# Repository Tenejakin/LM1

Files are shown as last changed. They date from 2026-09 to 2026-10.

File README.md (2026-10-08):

<p align="center">
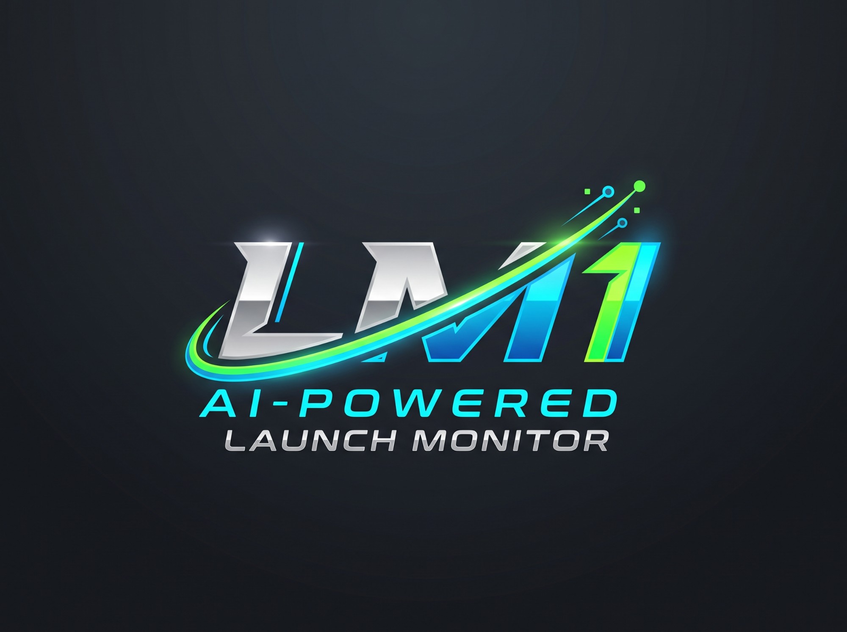
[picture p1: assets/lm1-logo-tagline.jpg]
LM1 - AI-powered launch monitor
  
</p>

<h1 align="center">LM1 — DIY Camera Golf Launch Monitor</h1>

<p align="center">
  A Raspberry Pi 5 + OV9281 global-shutter camera launch monitor, with a React Native companion app that talks to it over Bluetooth LE.
</p>

<p align="center">
  
  
  
  
  
</p>

---

> [!WARNING]
> **LM1 is an experimental hobby project.** Its measurements are unvalidated estimates and have not been checked against a reference launch monitor. Every value is labelled as measured, camera-estimated or club-estimated, with a confidence score. Treat the numbers as indicative only.

## What it is

LM1 has three parts:

| Part | Where | What it does |
| --- | --- | --- |
| **Mobile app** | [`App.tsx`](App.tsx), [`src/`](src) | Expo / React Native app for iOS and Android. It arms the monitor, shows shots, sessions and putting, and handles calibration and device setup. |
| **Pi service** | [`raspberry_pi/`](raspberry_pi) | A Python BLE peripheral on a Raspberry Pi 5. It keeps a rolling high-speed capture buffer, detects shots and runs the computer vision. |
| **Hardware** | [`hardware/`](hardware) | Parametric CAD scripts and printable STLs for the enclosure, camera brackets, IR light mounts and cable clips. |

```text
OV9281 camera ──► Raspberry Pi 5 ──BLE──► LM1 app ──► OpenGolfSim / n8n webhook
                  │                                  
                  ├─ rolling RAM buffer              
                  ├─ ball + AprilTag detection       
                  ├─ trajectory fit                  
                  └─ club silhouette / tag tracking  
```

The phone and the Pi talk **only over Bluetooth LE**. You don't need a shared network, an IP address or port forwarding. The Pi's Wi-Fi is left free for updates, SSH and simulator traffic.

## Features

**Measurement (Pi)**
- Ball speed, launch angle and start direction from a sub-pixel trajectory fit over up to 48 tracked frames
- Clubhead speed, attack angle and club path, from a club AprilTag or from the clubhead silhouette when no tag is fitted
- Smash factor, strike location on the face and surface spin estimates
- Putting motion analysis: pace, start line, skid and roll
- AprilTag ground calibration saved as a 3D pose, so the tag can be removed after calibration
- Lens calibration, a saved target line, and automatic exposure (shutter + gain)
- The last 100 rolling captures are kept on the Pi, each with a contact sheet for review

**App**
- Live monitor with ready → armed → processing → result states
- Club selection, carry estimates, shot history, session averages and consistency
- Shot review shows each metric's source and confidence
- Dedicated putting monitor and a manual shot calculator
- Device screen covering Wi-Fi setup over BLE, camera tuning, calibration and health diagnostics
- Metric or imperial units, set once and used on every screen
- [OpenGolfSim](OPENGOLFSIM.md) Desktop and Web forwarding, plus n8n webhook export
- Interactive demo mode, so you can try the app without any hardware

## Hardware

| Component | Notes |
| --- | --- |
| Raspberry Pi 5 | 1 GB is enough; use active cooling |
| OV9281 global-shutter camera | CSI, high frame rate (90–200+ fps depending on mode) |
| Continuous LED / IR lighting | Needed for the short exposure times |
| AprilTag target | For ground-plane calibration (see [`scripts/create_apriltag_target.py`](scripts/create_apriltag_target.py)) |
| 3D-printed parts | See [`hardware/enclosure/README.md`](hardware/enclosure/README.md) |

The full design rationale is in [`golf_launch_monitor_project.md`](golf_launch_monitor_project.md).

## Getting started

### 1. Run the app

You need Node.js 20+ and an LM1 **development build** installed on a phone. BLE uses native code, so the app **does not run in Expo Go**.

```bash
npm install
npm start
```

Then open the dev server from the LM1 development app on your phone. To build one:

```bash
npm run build:android:dev
```

```bash
npm run build:ios:dev
```

Android can also be built locally with `npm run android`. iOS builds go through EAS and need an Apple Developer account, but no Mac.

**No hardware?** Open the **Device** tab and choose **Use interactive demo**.

### 2. Set up the Raspberry Pi

Follow [`raspberry_pi/README.md`](raspberry_pi/README.md): flash Raspberry Pi OS Lite (64-bit), copy the `raspberry_pi/` folder over and run `install.sh`. This installs the BLE service as a systemd unit. The app finds the Pi by its BLE service UUID, so there is nothing to configure.

### 3. Calibrate

In the app, work through the checklist on the home screen:

1. **Lens calibration**, done once per lens and focus setting
2. **AprilTag ground calibration**, done with the tag in view; you can remove the tag afterwards
3. **Automatic exposure**, then fine-tune shutter and gain by hand if needed

[`LAUNCH_MEASUREMENTS.md`](LAUNCH_MEASUREMENTS.md) covers the full setup.

## Scripts

| Command | Purpose |
| --- | --- |
| `npm start` | Start the Expo dev server for the dev client |
| `npm run android` / `npm run ios` | Build and run on a connected device |
| `npm run web` | Web preview (demo only, no BLE) |
| `npm run typecheck` | TypeScript check |
| `npm run lint` | ESLint |
| `npm run ogs:bridge` | Start the OpenGolfSim Desktop WebSocket→TCP bridge |
| `npm run test:ogs` | Test the OpenGolfSim bridge |
| `npm run test:capture` | Test the capture client |

The Pi tests live in [`raspberry_pi/tests/`](raspberry_pi/tests). Run them on the Pi with:

```bash
python -m unittest discover -s raspberry_pi/tests -q
```

## Project layout

```text
App.tsx                  App shell and tab navigation
src/
  components/            UI and shot visualizations
  context/               Device/demo state and reconnection
  screens/               Home, Putting, Calculator, History, Calibration, Device
  services/              BLE client, OpenGolfSim and n8n integrations
  theme.ts, types.ts     Design tokens and shared types
raspberry_pi/            Pi BLE service, vision pipeline, calibration, tests, systemd
bridge/                  OpenGolfSim Desktop bridge
scripts/                 Calibration targets, capture audit and replay tools
hardware/                Enclosure, bracket and clip CAD (Python) + STLs
shared-hosting-server/   Optional PHP/MySQL API for uploading shot data and images
camera-tests/            Reference frames from camera bring-up
```

## Documentation

| Doc | Contents |
| --- | --- |
| [`DEVICE_API.md`](DEVICE_API.md) | BLE protocol spec (commands, events, chunking) |
| [`LAUNCH_MEASUREMENTS.md`](LAUNCH_MEASUREMENTS.md) | How measurements are made and how to calibrate |
| [`OPENGOLFSIM.md`](OPENGOLFSIM.md) | Simulator connection setup |
| [`raspberry_pi/README.md`](raspberry_pi/README.md) | Pi installation and service details |
| [`hardware/enclosure/README.md`](hardware/enclosure/README.md) | Enclosure revisions and print notes |
| [`shared-hosting-server/README.md`](shared-hosting-server/README.md) | Optional upload API |
| [`CHANGELOG.md`](CHANGELOG.md) | Release history |

## Security note

In this MVP, BLE pairing and Wi-Fi provisioning work for anyone in Bluetooth range. Before using LM1 in a shared space, turn off provisioning or add authenticated bonding.

## Contributing

This is a personal project, but issues and pull requests are welcome. Before opening a PR, run `npm run typecheck` and `npm run lint`, and run the Pi test suite if you changed the Pi service.

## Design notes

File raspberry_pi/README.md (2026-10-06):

# LM1 PRO Raspberry Pi BLE Service

Service **0.45.0**, protocol **2.31.0**: three clean paired stereo ball frames are sufficient for measured-grade speed, launch angle, and direction when all timing, geometry, calibration, and fit-quality gates also pass. Two paired frames remain an estimated speed-only fallback.

Service **0.44.0**, protocol **2.30.0**: putting captures can emit a putt result when ball and putter motion are resolved even if face strike is unavailable. An unavailable strike is `null`; `airborne` flags launch above 10° so the app does not present a ground-roll estimate for it.

Service **0.43.0**, protocol **2.29.0**: status reports the active capture mode so the app can show whether the Pi is set to a normal shot or putting, including after reconnecting. The app can switch modes in one tap before a ball is placed.

Service **0.42.0**, protocol **2.28.0**: full shots save up to 48 frames after the measured departure (plus any later tracked ball frame), discarding the empty detector-confirmation tail. Putting retains the full rolling burst. The Pi still observes the confirmation window before it reports a shot. Set `PINPOINT_FULL_SHOT_TAIL_FRAMES` to tune the saved full-shot tail.

Service **0.41.0**, protocol **2.28.0**: a signed-in app can issue a short-lived
ticket for one shot, then ask the Pi to upload every retained original JPEG from
both cameras directly to the Supabase frame ingest function. The ticket is
limited to that shot and expires after six hours. Set
`PINPOINT_SUPABASE_PROJECT_REF` in `/etc/default/pinpoint` for this feature.

Service **0.40.0**, protocol **2.27.0**: two high-quality stereo ball frames may
yield estimated interval-average ball speed, using the resting-ball impact
bracket as a consistency check. Two frames cannot resolve the flight curve,
so launch angle, direction, and carry remain unavailable.

Service **0.39.1**, protocol **2.26.1**: capture summaries distinguish a valid
mono fallback from shots where both stereo and mono tracking failed.

Service **0.39.0**, protocol **2.26.0**: the lower camera arms only when the
whole resting ball fits in the left-half green placement zone. The right half
remains available for outgoing tracking; the upper camera must still see the
resting ball and early flight. The stock ROI is `0,0.30,0.50,0.98`.

Service **0.38.1**, protocol **2.25.1**: tag-free club silhouette speed and
attack angle are retained for the selected club. Only an explicitly calibrated
club marker for a different club invalidates those values.

Service **0.38.0**, protocol **2.25.0**: full-shot carry now uses a
still-air drag/lift flight model. The selected club, ball speed and measured
attack angle set provisional spin when surface spin cannot be tracked.
`carryModel` records which spin source was used; landing is never observed.

Service **0.36.0**, protocol **2.23.0**: valid stereo geometry now supplies the
launch vector directly. Ball movement without resolved club motion is retained
as a capture, not emitted as a full shot. Ground recalibration invalidates the
previous target line; roll a fresh ball toward the target afterward. Keep the
entire resting ball, plus a little background, visible in both camera views.

Service **0.35.0**, protocol **2.22.0**: failed stereo tracks retain matched frame
indices and rejection counts for the app's capture review.

Service **0.34.0**, protocol **2.21.0**: stereo launch can use three validated paired
frames as an estimate, while three are needed for measured-grade metrics. A second
circle-detection pass recovers weak ball edges only when normal stereo pairing fails.

Service **0.33.0**, protocol **2.21.0**: when both camera lens and shared-ground-
tag calibrations are present, launch analysis triangulates the ball in both
views. If the lower-camera track fails, each view detects the ball independently
and pairs candidates using ray geometry and a coherent 3D path. It checks
tag-pose age, pair timing, resting position, ray agreement and two-view
reprojection before reporting a result. See
[dual-camera setup](../DUAL_CAMERA_SETUP.md) for calibration and limits.

Service 0.26.0 / protocol 2.17.0: speed, launch angle and direction come from an anchored trajectory fit to up to 48 sub-pixel tracked frames. It starts from the resting ball's ground position, chooses between a ground roll and a gravity flight, re-estimates the start of a ball nudged before release and reports fit uncertainty. Contact analysis ignores a hand or finger that stays in view. A departure must start at the resting ball, the resting ball must not reappear afterwards, and the motion nearest the trigger wins. A ball armed while the placing hand still touched it now tracks from a clean resting image. A ball that stays at resting height is reported as a ground roll with 0-degree launch, measured along the ground plane. The armed-ball reference stays paired with its original bounding box, refreshes only while the ball rests there, and is saved losslessly for replay. captures now retain calibration and outline-rejection diagnostics, and failure messages distinguish camera frames from usable 3D outlines. contact analysis now re-anchors slightly shifted resting balls and rejects stationary offset matches as outgoing motion. reconnect history is bounded to the newest ten records so the 100 retained captures cannot overflow one BLE message. The default ball-detection region covers 90% of the frame width and 68% of its height while retaining a small edge safety margin. Keep hands, clubheads, screens and moving shadows out of that region whenever possible. Tracker-guided partial silhouettes can produce explicitly lower-confidence launch estimates only after three consecutive matches, stable apparent radius and the existing 3D fit check. The strict full-silhouette path remains the default. Saved manifests now retain exact ball bounds for replay. The service also selects the best of up to 12 static ground-AprilTag detections; poses from 1–3 px reprojection error remain explicitly lower-confidence estimates and anything worse is rejected. It includes seam-split silhouette repair, convex-hull ball depth fitting, half-resolution ball tracking (analysis ~2 s instead of ~6 s), MTU-sized BLE notifications, no previews during result delivery, ~1.35 s rolling bursts by default, background AprilTag/focus/snapshot/BLE-preview work, an 8-request camera queue, per-capture contact sheets, live persistent exposure/gain controls, contact-window detection, AprilTag-referenced launch estimates, club-marker tracking, surface spin and putting motion analysis. The Pi retains the newest 100 rolling captures by default. See [measurement setup](../LAUNCH_MEASUREMENTS.md). Values remain unvalidated estimates.

Current service 0.42.0 · BLE protocol 2.28.0

This is the BLE-only Raspberry Pi half of Pinpoint. It opens no Pinpoint network port. The app can connect, arm, trigger, and receive synthetic shots or putts before the camera arrives, while Wi-Fi remains available for internet, SSH, software updates, and OpenGolfSim.

Synthetic results prove communication only. They are not measurements. When a USB webcam is attached, test mode also captures a real diagnostic JPEG so the camera path, framing, lighting, and exposure can be checked before the high-speed camera arrives.

Version 0.2.6 supports an automatic test loop: begin with an empty hitting area, wait for calibration, and place a ball inside the configured region. A ball that remains in the same location and at a consistent size changes the app state to **Armed**. Removing it changes the state to **Processing**, saves the last frame that contained the ball, and sends a synthetic result to the phone.

Version 0.3.0 sends a 160×120 grayscale placement preview to the LM1 app every three seconds over the existing BLE event channel. The app draws the configured detection area and target over the image. No Wi-Fi connection or camera web server is required.

Version 0.4.0 lets the LM1 app scan nearby Wi-Fi networks and ask Raspberry Pi OS NetworkManager to save and join one over BLE. Credentials are sent only in the connect command, are not returned to the app, and are not written to the service log.

## Prepare Raspberry Pi OS

In Raspberry Pi Imager, choose **Raspberry Pi OS Lite (64-bit)**. In customization:

1. Choose any hostname and create your own username/password.

2. Configure Wi-Fi or use Ethernet so the Pi can download the initial packages.

3. Enable SSH.

Bluetooth does not require the phone and Pi to share a Wi-Fi network. A suitable Raspberry Pi 5 USB-C power supply is recommended because under-voltage can cause unreliable radio and camera behaviour.

## Copy and install the service

From PowerShell in the project directory, replace `YOUR_PI_USER` and the hostname if needed:

```powershell

scp -r .\raspberry_pi YOUR_PI_USER@launchmonitor.local:~/pinpoint-setup

ssh YOUR_PI_USER@launchmonitor.local

```

Then run on the Pi:

```bash

cd ~/pinpoint-setup

chmod +x install.sh

sudo ./install.sh

```

The installer enables BlueZ and NetworkManager, installs the Python environment, removes the previous Pinpoint HTTP/mDNS service if present, and starts the BLE peripheral automatically at boot. Run the same installer again to update it.

If service 0.3.0 is already installed but the Pi has no internet, copy this folder to the Pi over temporary Ethernet or removable storage and reuse the existing packages:

```bash

cd ~/pinpoint-setup

sudo ./install.sh --offline

```

Offline mode requires the existing `/opt/pinpoint/.venv`, Bless dependency, and Raspberry Pi OS NetworkManager. It updates the service files and restarts LM1 without downloading packages.

The one-time 0.3.0 → 0.4.0 upgrade cannot be transferred through the old BLE protocol itself. After 0.4.0 is installed, Wi-Fi can be configured from the phone without SSH, Ethernet, or a monitor.

## Verify the Pi

```bash

systemctl status pinpoint --no-pager

bluetoothctl show

journalctl -u pinpoint -n 50 --no-pager

```

The service log should say that `LM1 PRO` is advertising. `bluetoothctl show` should report `Powered: yes`.

To confirm that Pinpoint no longer listens on the network:

```bash

sudo ss -lntup

```

SSH and other normal OS services may still appear, but there should be no Python process listening on port 80.

## Build the mobile app without a Mac

BLE uses native phone APIs and therefore cannot run inside Expo Go. Install a Pinpoint development build instead.

### Android from Windows

The simplest local route is Android Studio plus USB debugging:

```powershell

npm install

npm run android

```

This creates and installs the native Android app on the connected phone. No paid developer account is required.

Alternatively, use Expo's cloud build:

```powershell

npx eas-cli login

npx eas-cli build:configure

npm run build:android:dev

```

Open the build link on the Android phone and install the APK.

### iPhone from Windows

Expo's cloud can build iOS without a Mac, but Apple requires an Apple Developer account for signing and installing this custom BLE build:

```powershell

npx eas-cli login

npx eas-cli build:configure

npm run build:ios:dev

```

After installing either development build, start the JavaScript development server with `npm start` and open the Pinpoint development app.

## Connect and test

1. Keep the phone within a few metres of the Pi and enable Bluetooth.

2. Open **Device** and select **Find Pinpoint over Bluetooth**.

3. Allow the Bluetooth permission when prompted.

4. Confirm **Pi communication is working**.

5. Open **Wi-Fi setup**, scan, select a network, enter its password, and choose **Connect LM1 to Wi-Fi**.

6. Select **Arm**, then **Send test shot**.

7. Open Monitor and confirm a **Synthetic link test** result appears.

Wi-Fi remains connected throughout this process and can send the result to OpenGolfSim.

## Settings

Settings live in `/etc/default/pinpoint`:

```bash

PINPOINT_NAME="LM1 PRO"

PINPOINT_BLE_NAME="LM1 PRO"

PINPOINT_CAPTURE_BACKEND=simulator

PINPOINT_APRILTAG_ID=0

PINPOINT_APRILTAG_SIZE_MM=100

PINPOINT_CAMERA_DEVICE="/dev/v4l/by-id/usb-example-video-index0"

PINPOINT_CAMERA_RESOLUTION=1280x720

PINPOINT_CAMERA_FPS=30

PINPOINT_EXPOSURE_US=15700

PINPOINT_AUTO_BALL_DETECTION=true

PINPOINT_BALL_ROI="0,0.30,0.50,0.98"

PINPOINT_BLE_PREVIEW=true

PINPOINT_BLE_PREVIEW_INTERVAL_SECONDS=3

PINPOINT_CAPTURE_RETENTION=100

PINPOINT_WIFI_PROVISIONING=true

PINPOINT_WIFI_INTERFACE=wlan0

```

Apply changes with `sudo systemctl restart pinpoint`. Set `PINPOINT_WIFI_PROVISIONING=false` after setup when the device will be used in a shared or public space; the current MVP BLE link is proximity-only and not authenticated. Keep the short BLE name because advertising packets have limited space. Keep the simulator backend until the real camera capture module is installed. The installer records the first stable USB camera `video-index0` path it finds. Each test trigger then replaces `/var/lib/pinpoint/usb-test-latest.jpg` with a fresh frame and reports `frameCount: 1`, while `simulated: true` remains set because the shot numbers are synthetic.

`PINPOINT_BALL_ROI` is `left,top,right,bottom`, expressed from `0` to `1` across the camera frame. Keep hands, clubheads, screens, and moving shadows outside this rectangle when possible. Restart the service with an empty hitting area whenever the camera is moved.

Inspect the most recent diagnostic frame from another computer with:

```powershell

scp YOUR_PI_USER@launchmonitor.local:/var/lib/pinpoint/usb-test-latest.jpg .

```

## Main files

```text

pinpoint_ble.py          BlueZ/Bless GATT peripheral and notification framing

pinpoint_protocol.py     Commands, state, history, and synthetic capture backend

wifi_manager.py          NetworkManager Wi-Fi scan, status, and connection adapter

ball_detector.py         Debounced USB-camera ball placement/removal detector

install.sh               Repeatable Raspberry Pi OS installer/updater

systemd/                 Automatic startup and restart policy

tests/                   Transport-independent BLE protocol tests

```

## OV9281 on CAM0 (service 0.5.0)

Install `python3-picamera2` through apt (included by the online installer). The existing venv must expose system site packages. Offline installation needs Picamera2 already installed for CSI use.

With the ribbon attached to CAM0, boot configuration `/boot/firmware/config.txt` needs an `[all]` section containing `camera_auto_detect=0` and `dtoverlay=ov9281,cam0`. Back up the file before changing it and reboot once. Confirm with `rpicam-hello --list-cameras`.

Set these in `/etc/default/pinpoint` and restart `pinpoint`:

```bash

PINPOINT_CAMERA_SOURCE=csi

PINPOINT_CAMERA_INDEX=0

PINPOINT_CAMERA_RESOLUTION=1280x800

PINPOINT_CAMERA_FPS=30

PINPOINT_EXPOSURE_US=0

PINPOINT_DETECTOR_WIDTH=640

PINPOINT_DETECTOR_HEIGHT=400

PINPOINT_BLE_PREVIEW_WIDTH=160

PINPOINT_BLE_PREVIEW_HEIGHT=100

PINPOINT_BLE_PREVIEW=true

PINPOINT_CAPTURE_BACKEND=simulator

```

Exposure 0 enables automatic exposure; a positive value uses manual microseconds with `PINPOINT_CAMERA_GAIN` (default 1). `PINPOINT_CAMERA_INDEX=0` selects the first enumerated libcamera sensor, not the physical connector number. The boot overlay determines CAM0. `PINPOINT_CAMERA_DEVICE` is ignored for CSI.

For focus setup, set `PINPOINT_AUTO_BALL_DETECTION=false`: the preview continues without automatic shot triggers. Enable it again with an empty hitting area after positioning/focusing. The CSI stream runs at full resolution; detection uses a smaller copy and BLE sends a bounded 160×100 JPEG every three seconds. The same stream atomically saves `/var/lib/pinpoint/camera-latest.jpg` for full-resolution inspection. Do not start a second rpicam process while the service owns the camera.

The Device screen can change CSI exposure live from 20–250 μs while LM1 is ready. Changes are rejected while armed or processing so a capture cannot mix exposure settings. The selected value is saved atomically in `/var/lib/pinpoint/camera-settings.json`, overrides `PINPOINT_EXPOSURE_US` on later starts, and stays within the current launch-measurement exposure gate.

The same screen can change OV9281 analogue gain from 1×–16× in 0.25 steps while manual exposure is active. Higher gain brightens the frame but also amplifies noise, so prefer more lighting and the lowest gain that exposes the ball clearly. The selected value is stored with exposure in `camera-settings.json`, overrides `PINPOINT_CAMERA_GAIN` on later starts, and remains in effect when exposure changes.

Open Device in the app for the camera model, capture settings, preview and relative sharpness reading. Put a printed target at the intended ball distance in the green ROI. For a lens without autofocus, gently adjust its focus mechanism while keeping framing and lighting fixed; use the full-resolution snapshot to confirm details. A higher sharpness score can also reflect noise or different scenery, so it is not an absolute pass/fail grade.

```powershell

scp -i "$env:USERPROFILE/.ssh/lm1_codex_ed25519" lm1@192.168.0.140:/var/lib/pinpoint/camera-latest.jpg .

```

These settings verify the camera and positioning. They do not implement measured launch speed, angle or spin.

## Staggered cameras (0.55.0, experimental)

Set `PINPOINT_CAMERA_STAGGER=true` in `/etc/default/pinpoint` and restart the service. The two sensors then run
without libcamera sync and the upper one is held about half a frame (2 ms) behind the lower one, so the pair sees
the ball twice as often in time. The phase is chosen at start by restarting the upper camera until it lands near half
a frame, watched on every pair, and restored while the mat is empty if it drifts (about 25 minutes of margin).
Ball detection pauses while it is out of step. Club stereo is skipped on staggered bursts, and the camera pair must be
calibrated with the flag off. `scripts/test-stagger-phase.py` measures the phase behaviour on the device (stop the
service first), and `scripts/simulate-stagger.py` estimates the gain for each shot type.

## Level rig: no tag (0.54.0)

By default the Pi no longer needs the AprilTag. It assumes the stand sits level on the surface the ball is
hit from: gravity runs down the rig at the lower camera's stored pitch, the target is to the right of where the
bottom camera points, and the camera height is a stand constant that each shot corrects from the resting ball
(up to 40 mm). Lens intrinsics and the checkerboard camera-pair calibration are still required.

The tilt is a per-unit constant in `/var/lib/pinpoint/rig.json`, written once by `install.sh` from the saved
tag calibrations of both cameras (fused through the stereo pair), or by hand:

```text
python /opt/pinpoint/rig_pose.py --show
python /opt/pinpoint/rig_pose.py --from-tags --dry-run
python /opt/pinpoint/rig_pose.py --set 8.5 157.5     # pitch in degrees, height in mm
```

A tilt error costs accuracy: pitch error e shifts launch direction by about e x tan(launch angle) and a sideways
lean shifts launch angle by about the lean, so keep the stand level and re-measure the constants if the stand or
camera mounts change. `PINPOINT_GROUND_MODE=tag` restores the AprilTag ground calibration described below.
`scripts/compare-ground-modes.py` replays saved captures both ways and reports the difference.

## AprilTag calibration (0.12.0)

Print `output/pdf/lm1-apriltag-36h11-id0-100mm-v1.0.0.pdf` at 100% and verify its 100 mm ruler. Place the tag flat beside the ball with its top edge parallel to the intended target line. The Calibration screen outlines a detected tag and reports detection quality. **Capture AprilTag calibration** persists `/var/lib/pinpoint/apriltag-calibration.json`.

The saved record contains normalized image corners, pixels per millimetre, target-line rotation, perspective distortion, and a 3 × 3 homography that maps full camera pixels onto the tag plane in millimetres. Each later rolling capture copies this record into its `capture.json`, keeping the frame burst and its physical reference together for trajectory analysis. Set `PINPOINT_CAMERA_FOCAL_LENGTH_PX` after an intrinsic camera calibration if you also want an estimated camera-to-tag distance. Re-capture whenever the camera or tag moves.

AprilTag geometry gives the later trajectory analyzer a real scale and planar perspective correction. Current shot and putting numbers remain explicitly synthetic until the measurement backend consumes captured ball/club tracks.

## Ball detection overlay (0.6.0)

Set `PINPOINT_AUTO_BALL_DETECTION=true` to enable detection. For the 200 fps setup use `PINPOINT_BALL_FRAME_STRIDE=20`, `PINPOINT_BALL_CALIBRATION_FRAMES=30`, `PINPOINT_BALL_PRESENT_FRAMES=8`, and `PINPOINT_BALL_ABSENT_FRAMES=5`. Restart with the green ROI empty and wait for Waiting for ball before placing a ball there. Moving the camera requires a restart and empty-area calibration. The detector identifies a newly placed round object relative to its background, not semantic object identity.

The camera overlay shows Ball detected after stable placement and draws a box in the same preview image. It updates with the three-second BLE snapshot. During removal debounce it retains the last confirmed box. At 200 fps, service 0.7.0 samples detection at 50 Hz by default to reduce missed balls under flickering indoor lighting. Stale previews stop claiming detection. Automatic arming/removal still produces synthetic shot values.

## Analysis denoising (0.25.0)

Departure analysis uses a gentle per-frame bilateral filter (5 px, sigma colour 12, sigma space 3), also applied to the armed reference. Raw saved frames and displayed evidence stay unchanged. Set PINPOINT_ANALYSIS_DENOISE=none in the service environment and restart to disable. Filter time and parameters appear in capture diagnostics. Replay showed improved tag pose fit but no extra trajectory frames or spin, and worse radius fit; physical accuracy remains unvalidated. Filtering happens after capture, adding processing time rather than reducing camera acquisition FPS.

## Stored ground calibration (0.26.0)

Reset empty plane with the ball removed, then place the ground tag flat and fully visible and use Capture AprilTag calibration. Lens calibration at the exact current resolution must exist first. Successful capture saves 3D ground pose and lens inputs; you may remove the ground tag afterward. Keep camera position, focus, capture mode and surface fixed. Empty-plane reset and successful lens recalibration clear ground geometry and target line. Recalibrate with the tag again, then set target line from a roll. Old planar-only saved records are insufficient for tag removal. With no stored pose, a visible ground tag retains the previous burst fallback. Stored-pose diagnostics are retained in each analysis.

## Light controller (optional, service 0.57.0)

An ESP32-S3 on the IR ring can switch it off, steady or strobing. Plug it into a Pi USB port, flash
`hardware/strobe-test/strobe_master`, then add this to `/etc/default/pinpoint` and restart the service:

```
PINPOINT_LIGHT_CONTROL=esp32
# PINPOINT_LIGHT_PORT=/dev/ttyACM0   # only if auto-detection picks the wrong port
```

Without `PINPOINT_LIGHT_CONTROL` nothing changes. The Device screen's Light selector (Auto, Daylight, Flat,
Strobe) then moves the camera and the ring together. See `DEVICE_API.md` for `setLightMode`.

## Raw 10-bit frames (optional, service 0.59.0)

`PINPOINT_CAMERA_RAW=true` in `/etc/default/pinpoint` makes every camera frame also carry its linear raw 10-bit data
(only with `PINPOINT_CAMERA_BIT_DEPTH=10`). The service keeps the last 100 raw frames per camera
(`PINPOINT_RAW_BUFFER_FRAMES`, about 50 MB each) and saves those from 25 before to 45 after the impact next to the
JPEGs as 16-bit `raw-NNNN.png` files (value = 10-bit count x 64, data floor about 1024; `capture.json` has a `raw` entry).
Open them with `cv2.imread(path, cv2.IMREAD_UNCHANGED)`; subtract the black level and divide by 64 to get counts.

`PINPOINT_ANALYSIS_SOURCE=auto|raw|isp` chooses what the ball detector sees (default `auto`: raw-derived frames only while
strobing in a dark scene, the 8-bit picture otherwise; see `raw_frames.py` for why raw is not simply better).

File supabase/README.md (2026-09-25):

# LM1 cloud deployment

The mobile app uses Supabase Auth and row-level security. Each signed-in user's
shots and putts are stored under that user's `auth.uid()`. The app uploads shot
images through the `shot-images` Edge Function, which checks the user's session
and shot ownership before accessing Bunny Storage. The Bunny password must
never be included in an Expo build.

## Database

Run migrations in order using Supabase SQL Editor, or apply them with the
Supabase CLI if the project is linked:

1. `migrations/20260924000100_initial_cloud_sync.sql` (already applied if you
   created the accounts and cloud tables earlier).
2. `migrations/20260924000200_shot_images.sql` (adds Bunny image paths to shots).
3. `migrations/20260924000300_preserve_shot_images.sql` (keeps image paths when shot data changes and adds the RLS-scoped shot sync function).
4. `migrations/20260924000400_shot_frames.sql` (private per-user original frame index and upload tickets).

## Edge Function secrets

In Supabase Dashboard, open **Edge Functions → Secrets** and set:

| Name | Value |
| --- | --- |
| `BUNNY_STORAGE_ENDPOINT` | `https://storage.bunnycdn.com/lm1-live` |
| `BUNNY_STORAGE_PASSWORD` | The **Password** from Bunny's Storage Zone Credentials (write access) |
| `BUNNY_STORAGE_READ_ONLY_PASSWORD` | Optional read-only password for fetching images |

The function uses `@supabase/server` with user authentication and a client
scoped to that user's row-level security policies. Do not copy Bunny passwords
into the Expo `EXPO_PUBLIC_` variables.

## Deploy the function

Deploy `functions/shot-images/index.ts` as `shot-images`. Disable the platform's
automatic JWT check for this function: `config.toml` sets
`[functions.shot-images] verify_jwt = false`. `@supabase/server` verifies the
user's Supabase token, and the function checks the user's row-level-secured shot
record before any Bunny operation. The automatic check cannot accept newer
`sb_publishable_` client keys.

With the Supabase CLI linked to the project:

```powershell
npx supabase functions deploy shot-images --no-verify-jwt
npx supabase functions deploy shot-frame-ingest --no-verify-jwt
```

The app then uploads each live shot's primary image and, when present, its upper
camera image. Failed uploads remain in an account-scoped local queue and retry
when the app returns to the foreground. Opening a saved shot fetches its images
through the same authenticated function. The Sessions screen displays only the
signed-in user's cloud history and shots recorded in that app session.

The contact sheet is a small overview of 12 moments. Original capture frames
are separate files under `shots/<user>/<shot>/frames/`, with one primary and,
for a two-camera capture, one secondary JPEG per frame index. The app obtains a
short-lived upload ticket for the signed-in shot and sends it to the Pi over
Bluetooth. The Pi uploads the original files to `shot-frame-ingest` over HTTPS;
the function checks the ticket, writes Bunny objects, and records frame paths
under that user's shot. An interrupted upload resumes from missing frame
indices. Shot review reads uploaded originals through the authenticated
`shot-images` function, with live Pi previews as a fallback.

If an older app build cleared an image path, the `repair` action checks that
user's expected Bunny object and restores the path. If Bunny has no image, a
connected Pi can provide a retained contact sheet for the app to re-upload.

For private images, keep this Storage Zone off a public Pull Zone, or enable
Bunny Token Authentication on any Pull Zone attached to it. The app does not
publish or use a CDN URL for these images.

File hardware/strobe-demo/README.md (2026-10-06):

# LM1 Strobe Lab — 0.10.0

Standalone unchanged-wiring prototype for the dual OV9281 cameras and existing
ESP32-S3 IR ring controller. It temporarily replaces camera ownership by the
normal Pi service. No app, BLE protocol, calibration or ESP32 firmware update
is required. The browser page is at `http://192.168.0.140:3113` on the local network.

## Capture improvement (0.10.0)

The verified profile remains 120 captures/s and one 250 us flash per trigger.
Live trials at 200 and 160 triggers/s delivered only 100 and 80 primary frames/s;
those rates are therefore disabled. The underlying sensor/driver trigger limit
has not yet been isolated. Increasing the requested rate alone loses data.

The rolling capture now retains 350 ms before departure and 250 ms afterward
(42 pre-departure frames instead of 24). A manual scene check saved 73 frames per
camera, compared with 46 in the previous shot: about 59% more saved frames,
not 59% more motion samples per second. Both cameras delivered approximately
120 fps, with no timing gaps and 72/73 inferred shared-flash pairs.

Each new raw capture includes a copy of its lens and stereo calibration. Replay
uses that snapshot so later calibration changes cannot silently change old
geometry. Ball tracking retains up to 12 outgoing positions instead of five.
Empty scenes return unavailable measurements instead of failing the review.

Bridge 0.5.0 writes `raw-quality.json` next to the app replay: actual frame rate,
pre-departure frame count, timing gaps, inferred complete-flash coverage and raw
ball-core clipping. Quality warnings accompany the app analysis. The raw values
remain 10-bit data stored in 16-bit PNGs; a white preview is not proof of sensor
saturation. The last moving-ball shot had at most 0.573% sampled core clipping.

Timing correspondence is inferred from camera exposure metadata and the ESP
programmed delay; electrical STROBE feedback has not validated the flash phase.
Keep the room dark for this single-flash experiment. Longer buffers preserve
more approach/follow-through evidence but cannot extend the cameras' field of
view. Next validation: a gentle and faster chip, comparing actual visible head
positions, template consistency, stereo ray mismatch and timing coverage.

## App bridge (0.5.0)

`app_bridge.py` runs the existing LM1 Bluetooth protocol alongside the demo,
without opening either camera or the ESP32 serial port. It registers recent
0.7.1/0.8.0 captures and newly completed shots, and persists app-compatible
analysis and replay frames separately under `/var/lib/pinpoint/strobe-app-captures`.
Reconnect the app to LM1 PRO; newly completed captures become live app shots.
Recent historical captures are retained on the Pi for explicit recovery; the
app does not automatically import device history on connection. Select the club
in the app before new shots; imported historical chips default to lob wedge.

Camera 1 now runs at 120 fps with an 8 ms shutter, while camera 0 keeps its
1.5 ms shutter and one 250 us flash per frame. The longer secondary shutter
catches the same flash. Exposures are paired only when metadata shows that
the complete flash lies within both shutters; they are not paired by nearest
sensor timestamp. This requires a dark room so the flash dominates motion.

The bridge uses the existing fixed stereo calibration (checked against both
lenses, resolution and camera order) and the user-confirmed level/image-right
target assumption. Paired ball rays yield provisional 3D speed, launch and
left/right direction. A consistent pre-departure head/hosel stereo track yields
provisional club speed, attack angle and club path; smash divides the speeds.
These are estimates requiring reference validation. Failed tracks remain
unavailable. Without paired ball rays the image-plane fallback still uses an
explicitly assumed zero direction for the existing app flight model. Spin and
strike position remain unavailable; modeled spin and carry are not measurements.
Original raw captures are retained.

When only two consistent same-feature club positions can be triangulated, the
bridge reports low-confidence interval speed, attack and path. It does not use
two points to replace a longer club track that failed physical checks. Two
positions cannot independently validate feature identity or swing curvature.

Version 0.3.0 also forwards a usable two-point side-view club pair as a
low-confidence estimate (0.15) when stereo club tracking fails. Feature identity,
rotation and depth remain unverified; the reason is included in every metric.
It does not derive a left/right club path from that side-view angle. Stereo ball
rays missing by 6–12 mm are admitted only as low-confidence estimates (0.2),
with calibration bias and possible direction-sign error stated explicitly.
Ball-circle matching weighs radius agreement so a clipped bright-core contour
does not displace a better full-ball circle simply to reduce the ray gap.
Recent 0.9.1/0.10.0 shot analyses are upgraded under their existing capture IDs and
original timestamps, preserving club selection and avoiding duplicate shots.
Revised recent shots wait for the app's connection/status handshake before
delivery, so restarting the bridge does not send their initial fragments before
the app subscribes.

Version 0.4.0 searches for a broad head region near the shaft's projected ground
intersection, then matches a textured patch across consecutive pre-departure
frames. Correlation below 0.7, stationary motion, an image-border component,
or a ball-clipped head is rejected. A matched patch can provide provisional
image-plane club-feature speed and attack even when the visible head's area
changes with orientation; smash is the ratio of estimated speeds. Patch
correlation and the remaining depth/identity assumptions accompany the metrics.
Run this bridge instead of `pinpoint.service` while the demo owns the hardware.
Camera calibration commands are blocked while the demo runs to prevent another
camera owner. The bridge service is installed for this test and is not enabled
at boot. The demo must be running for live capture.

## Club visibility trial (0.7.1)

Version 0.8.0 also writes `review.json` for each new club-mode capture, with ball
trajectory, two-point/multi-position launch fits, velocity components, observed
displacement, departure bracket, and provisional club pair calculations. These
use the user's level-camera assumption. Two club candidates are sufficient for
provisional arithmetic but their identity remains unverified. Shaft orientation
is not face angle. `full_shot_review.py` exports saved shots to HTML and JSON.

Run `demo.py --club-mode --sync-camera0`. Camera 0 receives 120 triggers/s,
one 250 us flash 1 ms after each trigger, a requested 1.5 ms exposure, and gain 4.
The sensor uses its 242 fps limit to leave readout time between triggers.
Measured delivery is 8.333 ms per frame with 1491 us actual exposure. Camera 1
continues independently; stereo estimates require both exposures to contain
the same full flash as described above.

Saved summaries include `clubAnalysis`, and the page displays the latest club
result or rejection reason. A consistent pre-departure head-centroid path can
produce an experimental image-plane speed assuming the head is at ball depth.
This is not calibrated clubhead-centre speed. Attack angle remains unavailable
until the same physical club feature, flash correspondence and ground-relative
3D path are verified. Shaft endpoints and ball launch direction are not attack angle.

`--copies --sync-camera0` restores the three-copy ball experiment: 50 Hz,
8 ms exposure, 100 us flashes with 2.5/4 ms start spacings. Replayed multi-flash
club reflections do not become single-flash club measurements.

## Original free-running capture profile (0.3.2)

- 640 × 400, raw 10-bit words retained losslessly as 16-bit PNGs (count × 64).
- Both sensors free-run at 242 fps, 250 µs requested exposure, gain 4.
- ESP32: 250 Hz bursts, sixteen 20 µs flashes with 250 µs start intervals.
  The 4000 µs repeating period has the same spacing across its boundary, at 8% duty.
- IR supplies pulsed illumination inside short camera exposures. Positions are
  timed by the sensor, not by resolving individual flash copies. The continuous
  ambient contribution is still present; optical exposure is not claimed to be 20 µs.
- Trigger output stays off. No electrical camera synchronization is claimed.
- Each stream has its own sensor timestamps, actual exposure and gain metadata.
- 24 pre-trigger frames and approximately 180 ms after departure are retained.
- Before arming, both cameras locate the resting ball near the usual placement;
  green circles follow its actual position, which becomes the track origin.
- Replace the ball after each capture; the demo arms after a stationary interval
  with contrast and a clear surrounding annulus. Departure compares normalized
  ball-patch shape, so changes in pulse brightness cannot alone trigger it.
- Every departure/occlusion is a diagnostic capture, including rejected attempts.
- Positive, negative and absolute background-difference sweeps look for round
  ball silhouettes against the mat, floor, and their boundary, and require at least three
  consecutive sensor-timed positions, consistent size, a path originating at
  the resting ball, low fit residual and an estimated blur bound below 6 mm.
  Prefer the earliest valid interval. Conflicting positions over overlapping
  frames invalidate the estimate; different later interval speeds alone do not.
  Rejected fits retain their blur, origin and residual reasons. The old cyclic pulse fitter
  remains available for experiments with separated flashes; it is not used by
  this capture profile.
- Accepted numbers are **image-plane estimates** using reference ball diameter.
  Camera pitch, perspective, depth and stereo synchronization are not resolved.
  Spin, 3D direction and carry are unavailable.

`summary.json` retains the pulse pattern, per-view timestamps, candidate fits,
rejections and reference geometry. `contact.jpg` shows frames around departure.
The underlying raw frames and reference images are retained for offline iteration.

## Run on the Pi

Use the existing `/opt/pinpoint/.venv/bin/python`; no package installation needed.

```sh
sudo systemctl stop pinpoint
/opt/pinpoint/.venv/bin/python /home/lm1/strobe-demo-v0.3.2/demo.py
```

For the test session this runs under a temporary `lm1-strobe-demo` systemd unit.
Version 0.3.2 logs shutdown reasons and runs with `Restart=always` and
`RestartSec=3`, so unexpected process exits recover automatically.
Stop it before restarting `pinpoint`; they must never own the devices together.

```sh
sudo systemctl stop lm1-strobe-demo
sudo systemctl start pinpoint
```

Normal exit returns the ring to steady light. The existing ESP32 watchdog also
returns it to steady light if the host heartbeat stops. Captures are stored in
`/home/lm1/strobe-demo-v0.3.2/captures/`. There is no automatic capture deletion.
First prototype validation is against synthetic timing plus live static hardware;
moving-ball performance must be established from the user's wedge shots.

## Bench observations — 2026-10-01

At gain 4, stationary-ball raw data clips during long exposures. At gain 1,
4000 µs requested exposure, 60 µs flashes add about 71 raw counts in each view
in the sampled static setup. Near-full 8000 µs exposure with 100 µs flashes adds
about 100 raw counts averaged across the stationary ball. The stationary ball
partly clips, so these numbers establish visible flash contribution, not optical
pulse duration or moving-ball accuracy. Ambient light remains substantial.
`bench.py` contains the initial gain-4 diagnostic sweep; the Pi also retains the
gain-1 follow-up and its report in `/home/lm1/strobe-demo-v0.1.0/bench/`.

Version 0.1.1 adds ball-to-surrounding contrast to the arming check, so the empty
mat cannot automatically arm after a shot, and maps previews across the full
raw sensor range. Version 0.1.0 completed a live static capture in both views
without inventing a ball-speed result; both streams sustained approximately
120 fps, with frame intervals near 8.338 ms.

## First shot review and 0.2.0 changes

Version 0.1.1 retained three actual wedge shots and one placing-hand trigger.
All shot windows cover departure in both cameras, but the moving ball is an
elongated overlapping image rather than three resolved copies. No numerical
result was emitted. The first pattern cannot time those attempts unambiguously.
Their raw frames, timing and contrast reviews remain in the 0.1.1 directory and
were copied into `output/strobe-demo-v0.1.1/captures/` in the workspace.

Version 0.2.0 reduces exposure from 8000 to 500 µs and doubles camera sampling
rate, testing dense IR illumination and silhouette tracking for these shots.
It does not reinterpret the old long-exposure data as short-exposure data.
Ten focused tests on the Pi verify pulse timing rejection, frame-timed speed,
wrong-origin rejection, brightness-invariant departure and hands-clear arming.
Further moving-ball validation requires another shot batch.

## Second shot review and 0.3.0 changes

Four 0.2.0 shots were retained. The third produced an upper-view image-plane
estimate of 10.08 m/s from three points (0.65 px fit residual). The first and
fourth have coherent detections but fail the unchanged 6 mm blur gate at the
recorded 497 µs exposure. The ball becomes dark against the floor, where the
original positive-only detector loses it.

Version 0.3.0 adds bright/dark/boundary detection and halves the requested shutter
to 250 µs, increasing gain to 4 to maintain approximately the same ambient signal.
The ring pattern and 8% electrical duty are unchanged. Replay of the original
497 µs data preserves the third shot's upper estimate, recovers a later lower
view track on shot two and another lower track on shot three, and still rejects
the blur-limited shots. Those later image-plane speeds are not calibrated launch
speeds and should not be averaged with earlier intervals. Raw metadata is never
rewritten to simulate the new shutter. Twelve focused tests pass on the Pi.
Replay results and annotated frames are in `output/strobe-demo-v0.3.0/replay-v0.2.0/`.
The new live exposure still requires user-shot validation.

Version 0.3.1 locates the resting ball in both views before learning the reference,
fixing arming when placement differs from the original fixed circle. Thirteen
focused tests pass on the Pi, including a ball displaced from that anchor.

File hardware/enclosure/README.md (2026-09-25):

# LM1 enclosure CAD

## Vertical development stand v0.7.2

The newest development stand is v0.7.2 and is generated by
`lm1_development_v0_7_2.py`.
It uses an 85 mm vertical stereo baseline, mounts the Pi 5 behind the optical
carrier for 150 mm CSI ribbons, and places the measured 150 x 65 x 30 mm power
pack low in the base. Its camera plate now prints flat without supports; two
small side-printable rails provide the fixed 18-degree pitch. The power pack is
now crosswise behind the mast feet, and every major component has a separate
printable enclosure. See `VERTICAL_DEVELOPMENT_STAND_v0.7.2.md` for the print
list, provisional ring/light dimensions, assembly assumptions and safety notes.

Regenerate with `python hardware/enclosure/lm1_development_v0_7_2.py`.

## Open bench prototype v0.5.1 — 28-degree camera bracket

The latest three-piece bench prototype is generated by `lm1_test_v0_5_1.py`.
Its camera plate pitches **28 degrees downward from horizontal**, replacing
the 13-degree bracket in v0.5.0. The tray, mast and four M3 attachment holes
retain the v0.5.0 geometry, so only the camera bracket needs reprinting.
The bracket's print-oriented dimensions are 120 x 58 x 28 mm.

Print `stl/v0.5.1-test/lm1_test_camera_bracket_28deg_v0.5.1.stl` on its
provided side orientation. The folder also contains the tray, mast, assembly
reference, preview and build report. All three exported printable meshes
pass watertightness, positive-volume and single-connected-solid checks.

Regenerate with `python hardware/enclosure/lm1_test_v0_5_1.py`.
This revision changes pitch only; the model's lens centre remains 150 mm above
its base reference. Your measured 230 mm installation height depends on how
the stand is mounted or raised. Recalibrate the camera/ground pose and reset
the empty detection background after fitting the new bracket.

To set the target line left-to-right in the camera view, run
`sudo /opt/pinpoint/.venv/bin/python /home/lm1/set-camera-target-line.py`
after copying `scripts/set-camera-target-line.py` to the Pi. Tool v1.0.0
uses the newest capture, lens calibration and a tag lying on the ground.
Set it again after changing camera or tag placement. The previous line is
backed up to `/var/lib/pinpoint/target-line-before-camera-v1.0.0.json`.

## Flat-pack enclosure v0.4.0

Enclosure version **0.4.0**

This folder contains a narrow, flat-pack enclosure for the LM1 Raspberry Pi 5
launch monitor. Version 0.4.0 is an engineering prototype intended to verify
placement, camera framing, cooling and service access before cosmetic refinement.
The earlier v0.2.0 and v0.3.0 files remain available for comparison.

## Geometry represented by the model

- Lens centre is 150 mm above the hitting surface.
- The OV9281 plate is pitched 13 degrees downward.
- The assembled body is 174 x 144 x 189 mm, excluding the removable hood.
- The enclosure is placed approximately 500 mm downrange and 300 mm on the
  toe side of the ball, then aimed inward at the hitting area.
- The camera hood clears an approximately 100-degree horizontal field of view.
- Two generic 28 mm LED openings sit below the camera hood.
- A replaceable 3 mm polycarbonate window is clamped behind the camera opening.
- Raspberry Pi 5 mounting bosses use the standard 58 x 49 mm hole pattern.
- A generic 2.79-inch, 16:9 OLED sits in a separate display pod.
- The OLED face is tilted 35 degrees above horizontal.
- The OLED pod swivels 35 degrees left or right and locks with two M3 screws.
- A rear 40 mm fan pattern and side ventilation slots provide active airflow.
- Flat panels are clamped between a base, top and four universal corner rails.

## Generated files

The `stl/v0.4.0` directory contains:

- `lm1_base_v0.4.0.stl` - floor with Pi 5 bosses and ballast holes
- `lm1_front_sensor_panel_v0.4.0.stl` - replaceable camera/LED panel
- `lm1_rear_service_panel_v0.4.0.stl` - fan and cable-access panel
- `lm1_side_panel_v0.4.0.stl` - reversible ventilated panel; print two
- `lm1_corner_rail_v0.4.0.stl` - universal screw rail; print four
- `lm1_top_swivel_v0.4.0.stl` - removable roof with cable and swivel slots
- `lm1_oled_swivel_base_v0.4.0.stl` - rotating OLED base and cable collar
- `lm1_oled_tilt_cradle_35deg_v0.4.0.stl` - angled OLED bezel and supports
- `lm1_oled_retainer_v0.4.0.stl` - rear display clamp
- `lm1_sun_hood_v0.4.0.stl` - camera glare and sun hood
- `lm1_camera_mount_13deg_v0.4.0.stl` - adjustable OV9281 board plate
- `lm1_window_retainer_v0.4.0.stl` - clamp for the polycarbonate window
- `lm1_led_adapter_v0.4.0.stl` - generic LED adapter; print two
- `lm1_assembly_reference_v0.4.0.stl` - assembled reference, not for printing

## Important fit assumptions

The OLED dimensions are provisional because "2.79 inch" describes only its
diagonal, not the PCB or mounting holes. Version 0.2.0 assumes:

| Item | Assumed size |
| --- | --- |
| OLED visible opening | 65 x 37 mm |
| OLED PCB pocket | 80 x 48 mm |
| OLED mounting pattern | 72 x 42 mm, M2.5 |
| OV9281 board | up to 54 x 54 mm |
| OV9281 mounting slots | 24-34 mm centres, M2.5 |
| LED body opening | 28 mm |
| Fan | 40 mm, 32 mm mounting pattern |

Measure the exact OLED and camera board before committing to a long print.
The values are grouped at the top of `lm1_case_v0_2_0.py` for easy editing.

## Hardware

- 4 x M2.5 screws for Raspberry Pi 5
- 4 x M2.5 screws and nuts for the OLED retainer
- 4 x M3 screws for the camera mount
- 4 x M3 screws for the window retainer
- 4 x M3 screws for the sun hood
- 24 x M3 screws for the panels, rails, base and top
- 2 x M3 screws and lock nuts for the OLED swivel slots
- 4 x M3 screws for attaching the tilted cradle to its swivel base
- 4 x M3 screws for an optional 40 mm fan
- 90 x 68 x 3 mm clear polycarbonate camera window
- Heat-set inserts are recommended for repeatedly removed parts
- Rubber feet and a steel ballast plate are recommended for stability

Do not use acrylic for the protective window. A golf-ball impact can shatter
acrylic; polycarbonate is the safer sacrificial material. This prototype has
not been impact certified, so it must remain outside the intended ball line.

## Printing

- Material: ASA is preferred outdoors; PETG is the easier prototype material.
- Walls: 4 perimeters.
- Layer height: 0.20 mm.
- Infill: 25-35 percent, with 45 percent around the camera bracket.
- Every v0.3.0 part fits within 180 x 174 mm on the print bed.
- Print the base and all panels flat.
- Print four corner rails horizontally and two copies of the side panel.
- Print the hood on either side wall to avoid a long unsupported bridge.
- The OLED swivel base STL is already oriented with its main plate on the bed.
- Print the OLED tilt cradle on one triangular side support.
- Print the retainers flat.
- Use supports only for the camera mount if the slicer cannot bridge its arms.

## Regenerate the STL files

```powershell
python -m pip install -r hardware/enclosure/requirements-cad.txt
python hardware/enclosure/lm1_case_v0_4_0.py
```

After changing camera or display geometry, increment `CASE_VERSION` and the
output folder before exporting another revision.

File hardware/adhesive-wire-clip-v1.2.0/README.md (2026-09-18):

# LM1 vertical single-wire clip v1.2.0

A compact adhesive-backed clip for one wire running vertically along the
printed LM1 frame. It uses the same snap geometry as the two- and four-channel
clips and fits typical 1.5–3.8 mm electronics wires.

The clip is 10 x 16 x 8.5 mm. Mount it with the 16 mm channel direction vertical.
The complete flat 10 x 16 mm underside accepts double-sided tape.

Print flat-side down at 100% scale in millimetres using 0.2 mm layers, four walls
and 25–40% infill. PETG is recommended for repeated use; PLA is suitable for a
mostly permanent installation. No supports are required.

Clean the clip and mounting surface with isopropyl alcohol and allow both to dry.
Apply thin high-bond double-sided tape across the underside, press firmly for 30
seconds, and let the adhesive settle before inserting the wire. Keep the wire
away from heat, moving parts, sharp edges and tight bends.

The generated STL is validated as one watertight solid. Physical fit and tape
strength depend on printer calibration, filament and adhesive.

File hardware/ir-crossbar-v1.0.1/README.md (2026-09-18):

# IR tape-pad stand v1.0.1

Updated from the preliminary v1.0.0 zip-tie frames to two solid flat pads, as requested for double-sided tape.

Overall size: 120 x 28 x 42 mm. Each tape pad: 32 x 38 mm, 3 mm thick. LED optical centres should be 86 mm apart, aligned to the centre of each pad at 23 mm above the underside. Each pad turns inward 4.915 degrees. Nominal beam axes meet on the centreline 500 mm forward of the midpoint between LED centres, at the same height as those centres. This is aiming geometry, not optical focusing. Actual LED protrusion changes the intersection slightly. Tilt the entire stand if the ball sits lower than the LEDs.

The centre notch marks the forward side. Attach each board to the forward face of its pad, with the LED facing toward the notch/target. Keep boards parallel to their pads and centre the emitter, rather than the PCB. Board dimensions are not verified; boards may overhang the pads and the 120 mm outside limit applies to the printed part, not automatically to the attached boards. Measure the assembled outside width before use.

Use narrow strips of double-sided tape on clear PCB areas only. Do not cover the heatsink, contacts or components. These solid pads are unsuitable if they obstruct the board's heatsink; keep a gap or move attachment to clear edges. The plastic and tape do not replace LED cooling. Switch off LEDs before alignment and stop if tape loosens or plastic softens.

Print the broad 120 x 28 mm base flat on the bed. Suggested: PETG, 0.2 mm layers, 4 walls, 25% infill. The pads are vertical with straight walls; no window bridges or supports are needed. Two 3.4 mm base holes can take M3 fixings. Hardware and camera mounting are not included.

The STL is one connected watertight solid in millimetres. build-report.json records mesh checks and analytical beam-axis intersection. preview.png is rendered from that mesh. build.py is editable source, requiring numpy, trimesh, manifold3d and Pillow; run `python build.py` to regenerate. Fit, print tolerances, temperature and real beam shape require physical checking.

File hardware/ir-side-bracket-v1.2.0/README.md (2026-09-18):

# LM1 IR side brackets v1.2.0

These mirrored brackets move the two IR modules from below the camera to the
left and right sides of the open LM1 v0.5.1 mast. Each bracket uses the two
existing M3 holes in one upright (44 mm vertical spacing), so it can share the
camera-bracket bolts when fitted with longer screws.

The IR optical centres sit approximately 12 mm inward from the upright
centrelines. On the 110 mm upright spacing shown in the current mast, this puts
the LED centres 86 mm apart. Each 32 x 38 mm tape pad has an integrated
4.915-degree horizontal wedge that points the emitter slightly inward; the
nominal beam axes meet 500 mm in front of the device. Version 1.2.0 also pitches
both mounting faces 28 degrees downward to match the current v0.5.1 camera
bracket. The top of each pad therefore projects farther forward than the bottom.
This is aiming geometry, not optical focus, and the real beam pattern may need
a small physical adjustment.

## Print and fit

Print one left and one right STL with the broad flat rear face on the bed. Use
PETG, 0.16-0.20 mm layers, four walls and 35-45% infill. The model includes
3.4 mm clearance holes for M3 hardware. Start with M3 x 16 mm screws if the
part shares the existing camera-bracket stack, but verify the required length
and ensure the nut has full thread engagement.

Attach each IR board to the sloped forward face using thin high-temperature
double-sided tape on clear PCB areas. Centre the emitter on the pad rather than
centering the PCB. Keep the LED heatsink, components, solder joints and wiring
uncovered. The plastic bracket is not a heatsink. Power the emitters off while
aligning and stop using the mount if tape loosens or the plastic softens.

The front face gets thicker toward the outside of each bracket. Therefore the
left and right files are not interchangeable. Viewed from the front of the
device, install `left` on the viewer's left and `right` on the viewer's right.

## Files and validation

- `lm1-ir-side-bracket-left-v1.2.0.stl` and `...right...`: printable parts.
- `preview.png`: assembly concept; cream mast and black camera are references.
- `build-report.json`: dimensions and mesh checks.
- `build.py`: editable source; requires numpy, trimesh, manifold3d and Pillow.
- `lm1-ir-side-bracket-v1.2.0.zip`: complete printable package.

The meshes are checked as single connected watertight solids. Dimensions were
derived from the v0.5.1 CAD and the supplied photo, but the IR PCB footprint,
screw stack and physical clearances have not yet been measured on the actual
device. Test-fit before a long unattended run.

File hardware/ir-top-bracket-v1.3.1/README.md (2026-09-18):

# LM1 above-camera IR bracket v1.3.1

This one-piece bridge places both IR emitters above the camera on the open LM1
v0.5.1 mast. It shares the two upper M3 camera-bracket screws, located 110 mm
apart, and does not require drilling or replacing the mast.

The emitter centres are 28 mm above the upper screws and 86 mm apart. Each
32 x 38 mm adhesive pad points approximately 32.27 degrees downward and 4.915
degrees inward. Unlike v1.3.0, the lights are not merely parallel to the
28-degree camera: their extra downward pitch compensates for the IR centres
being 50 mm above the camera centre. All three nominal axes therefore target
the same point 500 mm forward. The camera opening remains clear beneath the
two pads.

## Print and install

Print the STL with its broad, flat rear face on the bed. Use PETG, 0.16-0.20 mm
layers, four walls and 35-45% infill. The part has two 3.4 mm clearance holes.
It will probably require longer upper camera-mount screws; begin by checking
M3 x 16 mm or M3 x 20 mm hardware and ensure the nuts fully engage.

Viewed from the front, the horizontal bridge sits across the upper screw pair
and the two pads extend upward. Their top edges project farther forward than
their bottom edges; this is what aims the emitters downward. Centre each LED
emitter on its pad rather than centring the PCB.

Use thin high-temperature double-sided tape only on clear PCB areas. Keep
heatsinks, components, solder joints and wiring uncovered. The printed bracket
is not a heatsink. Power the IR modules off during alignment and stop using the
mount if the tape loosens or the plastic softens.

## Package

- `lm1-ir-top-bracket-v1.3.1.stl`: printable one-piece bridge.
- `preview.png`: installed concept; cream mast and black camera are references.
- `build-report.json`: dimensions and mesh validation.
- `build.py`: editable source requiring numpy, trimesh, manifold3d and Pillow.
- `lm1-ir-top-bracket-v1.3.1.zip`: complete printable package.

The exported mesh is checked as one connected watertight solid. Geometry uses
the v0.5.1 mast dimensions and the supplied photo. PCB size, screw-stack length,
camera field-of-view clearance and physical fit still require a test-fit.

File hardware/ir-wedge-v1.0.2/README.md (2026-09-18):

# Simple IR triangular wedge v1.0.2

Replaces the full stand with just a triangular wedge for attaching to the existing bracket, as requested.

Size: 32 x 38 mm footprint, rising from zero to 2.752 mm. Angle: 4.915 degrees between flat back and sloping board face. Print two copies; rotate the second 180 degrees on its mounting face to reverse the tilt. No holes, frame or stand included.

Print flat-face down at 100% scale in millimetres, preferably PETG with 0.12-0.16 mm layers and solid infill. The thin tip may lose a fraction of a millimetre during slicing; do not place supports under the slope. Tape the flat face to the existing bracket and the board to the sloping face. Equal tape thickness across each face preserves the angle. Keep heatsinks and components clear, and do not rely on tape or plastic for LED cooling.

On a bracket initially parallel to the LED baseline, orient the wedges so both LED axes turn inward. Angle alone does not fix crossing distance: 4.915 degrees intersects 500 mm ahead only at 86 mm LED optical-centre spacing. At 120 mm optical-centre spacing it intersects about 698 mm ahead. Any existing bracket angle adds to the wedge angle. Set LED centres at 86 mm if the existing mount is straight and you want the nominal 500 mm crossing. Beam shape and actual LED protrusion affect real illumination.

Mesh checked as a single watertight solid; angle checked from the triangular section. Board footprint, mounting heat and physical fit remain unverified. Source requires numpy and trimesh.

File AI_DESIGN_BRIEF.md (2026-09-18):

# LM1 Mobile App — AI Design Brief

Brief version 1.0.0

Create an original mobile interface design for **LM1**, a portable golf launch monitor. Do not inspect, reproduce, or describe any existing LM1 interface. Develop a fresh visual direction from the product requirements below.

LM1 connects a phone to a Raspberry Pi camera device over Bluetooth. Golfers use it beside a hitting mat, often outdoors or in dim simulator rooms. The interface must be readable at a glance, usable with one hand, and clear in bright and dark conditions.

Design these main areas:

- **Launch monitor:** connection state, selected club, arm/disarm control, processing feedback, ball speed, club speed, smash factor, launch angle, start direction, carry estimate, trajectory, and strike location.
- **Putting:** putter speed, ball speed, direction, launch angle, skid, roll, target pace, and green-speed context.
- **Calculator:** manual measurement entry with immediate calculated results and clear validation.
- **Sessions:** shot history, sorting, session averages, consistency, and an easy way to inspect one shot.
- **Device:** Bluetooth connection, camera preview, ball-placement area, camera calibration, focus/sharpness feedback, exposure, frame rate, storage, temperature, Wi-Fi setup, and simulator connection.

The camera preview needs four unmistakable states: **Calibrating — keep area empty**, **Waiting for ball**, **Ball detected**, and **Detection off**. When a ball is detected, show its location directly on the image with a clear bounding marker. Keep status text readable over both bright and dark camera frames. Also communicate stale or disconnected camera data instead of leaving an old detection visible.

Prioritize the live shot workflow: connect, select a club, position the ball, confirm detection, arm, capture, process, and review the result. Distinguish real measurements from synthetic test results. Use plain language, large touch targets, strong contrast, accessible type sizes, and more than color alone to convey status.

Deliver:

1. A compact visual system covering color, typography, spacing, icons, controls, cards, charts, and status treatments.
2. High-fidelity mobile screens for the five main areas and all launch-monitor states.
3. Camera-preview states, including detected-ball annotation and focus guidance.
4. Reusable component specifications and responsive behavior for common phone sizes.
5. A clickable prototype of the primary shot flow.

Keep technical implementation details out of the golfer-facing interface unless they help diagnose or configure the device. The result should feel precise, fast, trustworthy, and suitable for repeated use during practice.

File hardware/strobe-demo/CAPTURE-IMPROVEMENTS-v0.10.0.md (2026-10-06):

# Capture findings — 0.10.0 / bridge 0.5.0

## What limits the current measurements

At the last estimated club-feature speed of 6.294 m/s, 120 fps spaces
observations about 52 mm apart. A 250 us flash allows about 1.57 mm of motion.
Only the time that the head remains visible near the ball provides useful
pre-impact positions. Extending a recording does not change this spacing.

The latest raw shot has useful intensity detail: sampled moving-ball cores
clip by 0–0.573%. Do not reduce flash energy merely because the display looks
white. A shorter pulse trades photon count for less blur and needs a real
moving-feature comparison.

Live trials:

| Requested rate | Primary delivered | Secondary delivered | Decision |
|---|---:|---:|---|
| 200 Hz, 150 us pulse | 100 fps | about 200 fps | Reject: alternate primary frames missing |
| 160 Hz, 187 us pulse | 80 fps | about 160 fps | Reject: alternate primary frames missing |
| 120 Hz, 250 us pulse | 120 fps | about 120 fps | Retain |

The faster trials kept LED duty at or below 3%. The primary trigger limit
requires a separate sensor/driver investigation; readout overhead alone is not
yet a proven explanation. No wiring, firmware or calibration change was made.

## Changes retained

- 350 ms of pre-departure data and 250 ms afterward; manual check saved 73
  raw frames from each camera, versus 46 in the previous shot.
- Up to 12 outgoing ball positions retained for replay, previously five.
- Calibration copied into each capture and validated before stereo replay.
- Recorded pulse width/delay used for exposure matching.
- Frame timing, inferred flash coverage and clipping saved in raw-quality.json;
  quality failures also accompany the app analysis warnings.
- Missing-ball recordings yield unavailable results instead of crashing.

Bench capture `capture-1790901129626628779`: primary 120.0048 fps, secondary
119.9472 fps, 42 pre-departure frames each, zero timing gaps, 72/73 inferred
shared-flash pairs. It was a manual scene check, not a golf measurement test.
Calibration replay used the capture snapshot. No ball or club metrics were
invented. Forty Python tests and the app payload/display regression passed.

## Next priorities using this hardware

1. Compare two new chips with saved raw head patches. Prefer the same textured
   feature across three or more positions; keep two-position results explicitly
   provisional. A changing reflective blob centroid is not a stable head point.
2. Investigate stereo calibration bias: recent ball rays miss by about 9–12 mm.
   More samples do not remove this bias. Club path and left/right direction
   need stronger geometric validation before they are trustworthy.
3. Benchmark shorter exposures and flash delay separately if pursuing higher
   trigger rates. Require both actual frame delivery and raw illumination tests
   before using a faster profile for shots.
4. Attempt spin only when multiple sharply resolved views show repeatable ball
   markings or dimple texture. Current inferred/model spin is not measured spin.

PiTrac's relevant principle is coordinated illumination, exposure timing and
calibrated views—not simply requesting a higher frame rate. Its camera approach
is described in [the PiTrac camera documentation](https://docs.pitrac.org/hardware/cameras/).

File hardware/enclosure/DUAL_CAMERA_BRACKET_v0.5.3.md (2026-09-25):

# LM1 dual-camera bracket — v0.5.3

This revision replaces the single-camera v0.5.2 bracket with one rigid carrier
for two camera boards. The camera optical centres are horizontal, share the same
15-degree downward pitch, and are 58 mm apart. A single carrier fixes the
relative camera pose, which is preferable to two independently flexing mounts
for stereo reconstruction or synchronized secondary-view measurements.

The four mast holes are unchanged, so the v0.5.3 bracket is a direct replacement
on the v0.5.2 tray and mast. Only
`lm1_test_dual_camera_bracket_15deg_v0.5.3.stl` needs to be printed when upgrading
an existing stand. Print it in the supplied orientation with 0.2 mm layers,
four walls, and 25–35% infill. Use a stiffer material such as PETG, ASA, or CF-PETG
when camera-to-camera calibration stability matters.

Each camera has its own 22 mm lens aperture and four diagonal slots supporting
nominal square mounting-hole patterns from 24 to 34 mm. Fit identical insulating
spacers under both PCBs and avoid overtightening one board more than the other.
Route the two CSI/USB cables separately down the open mast with a small service
loop and strain relief; cable tension must not twist the carrier.

The 58 mm baseline is a practical compromise for this 130 mm mast: the two
54 mm boards remain within the stand envelope, have a 4 mm nominal gap, and keep
their fasteners clear of the mast flanges. Both cameras intentionally share pitch
and height. Correct residual alignment in stereo calibration rather than bending
the mount.

After installation, verify that both lenses see the full ball flight region,
synchronize exposure and frame timing, calibrate intrinsics for each camera and
then calibrate their stereo/extrinsic relationship. Re-run the device ground-pose
and target-line calibration after any camera or bracket movement.

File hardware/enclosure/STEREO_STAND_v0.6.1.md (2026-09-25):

# LM1 modular stereo stand — v0.6.1

This revision fits a 180 x 180 mm print bed. The mast is divided into lower and
upper rigid frames, joined at 120 mm by four printed splice plates: one on the
front and rear of each upright. Use eight M4 x 25 mm bolts, washers and locknuts.
The joint is deliberately below the cameras and uses both faces of each upright
to resist pitch and yaw.

The carrier baseline is 90 mm instead of v0.6.0's 120 mm so the one-piece camera
carrier remains printable and calibration-stable. Lens centres remain 200 mm high
at 20 degrees downward, intersecting the ground about 550 mm ahead. The 176 x
150 mm tray, 174 mm mast frames and 170 mm carrier all fit the target bed.

Print one tray, lower mast, upper mast and camera carrier, plus four copies of the
splice plate. Use PETG, ASA or CF-PETG, 0.2 mm layers, at least five walls around
the mast and splice plates, and 35–45% infill. Assemble on a flat surface, tighten
both sides evenly, then check that the upper frame cannot twist before calibrating.

Use identical externally synchronized global-shutter cameras, equal spacers and
independent cable strain relief. Calibrate each lens, then stereo extrinsics,
ground pose and target line only after final assembly. Retightening a joint or
moving a camera invalidates extrinsic calibration.

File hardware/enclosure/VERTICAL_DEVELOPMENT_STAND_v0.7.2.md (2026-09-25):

# LM1 vertical development stand — v0.7.2

Version 0.7.2 is a printable fit prototype for the two-camera LM1 development
hardware. It replaces the horizontal stereo carrier with two parallel cameras
on an 85 mm vertical baseline. The lower lens centre is 162.5 mm above the
hitting surface and the upper lens centre is 247.5 mm. Both are pitched 18
degrees downward.

## Architecture

- The lower camera is the primary impact camera and receives the 42-LED ring.
- The upper camera supplies the synchronized second view.
- Two 20 mm light-lens openings sit left and right of the lower camera.
- The Raspberry Pi 5 mounts immediately behind the optical carrier so both
  150 mm CSI ribbons stay in the head.
- The 150 x 65 x 30 mm power pack lies crosswise at the rear of the base,
  completely behind both mast feet and their mounting bolts.
- The provisional LiPo box lies front-centre between the mast uprights.
- The mast is split and reinforced with four splice plates so every printable
  part fits a 180 x 180 mm bed.
- The camera/light plate is completely flat and prints face-down without
  supports. Two small triangular rails create the 18-degree optical pitch and
  should also be printed on their broad sides without supports.
- The power pack, LiPo, camera boards, Pi, IR ring and side lights each have
  separate printable protective boxes, covers or shrouds.

## Important provisional dimensions

This is deliberately a development-fit version, not a final protective product.
The camera carrier supports boards up to 54 mm square and mounting patterns from
24–34 mm. The ring retainer assumes an 80 mm outer diameter and 32 mm centre
opening. The side-light apertures assume 20 mm lenses. Measure the real parts
before committing to a long or expensive print.

The ring carrier includes four strap slots to tolerate a modest diameter
difference. Do not drill the camera carrier while cameras are fitted: a changed
camera pose invalidates stereo calibration.

## Print list

- 1 × `lm1_vertical_base_v0.7.2.stl`
- 1 × `lm1_vertical_mast_lower_v0.7.2.stl`
- 1 × `lm1_vertical_mast_upper_v0.7.2.stl`
- 1 × `lm1_vertical_camera_light_carrier_v0.7.2.stl`
- 2 × `lm1_camera_tilt_rail_18deg_v0.7.2.stl`
- 4 × `lm1_mast_splice_plate_v0.7.2.stl`
- 1 × `lm1_ir_ring_retainer_80mm_v0.7.2.stl`
- 1 × `lm1_ir_ring_shroud_80mm_v0.7.2.stl`
- 1 × `lm1_pi5_head_cradle_v0.7.2.stl`
- 1 × `lm1_pi5_cover_v0.7.2.stl`
- 2 × `lm1_camera_board_cover_v0.7.2.stl`
- 2 × `lm1_side_light_pod_20mm_v0.7.2.stl`
- 1 × `lm1_power_pack_box_v0.7.2.stl`
- 1 × `lm1_power_pack_lid_v0.7.2.stl`
- 1 × `lm1_lipo_box_provisional_v0.7.2.stl`
- 1 × `lm1_lipo_lid_provisional_v0.7.2.stl`

Use PETG for the fit prototype and ASA or CF-PETG after the geometry is proven.
Suggested settings are 0.2 mm layers, five walls around the mast and carrier,
and 35–45% infill. Use washers and locknuts at the mast splice.

## Safety and validation

- Use constant-current LED drivers and metal heatsinks for the two 3 W emitters.
- Confirm the IR ring voltage, current and heat load before installing it.
- IR can be an eye hazard even when it looks dim; test at reduced power.
- Secure the LiPo without crushing or piercing it and use a fuse/BMS appropriate
  to the actual pack.
- Use a replaceable polycarbonate shield before hitting real golf balls.
- Externally synchronize both cameras. Two unsynchronized streams do not form a
  valid high-speed stereo measurement pair.
- Recalibrate both lenses, stereo extrinsics, ground pose and target line after
  final assembly or any fastener movement.

Regenerate the files with:

```powershell
python hardware/enclosure/lm1_development_v0_7_2.py
```

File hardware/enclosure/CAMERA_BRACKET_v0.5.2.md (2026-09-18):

# LM1 15-degree camera bracket — v0.5.2

This revision changes the open test stand camera pitch from 28 degrees to
15 degrees downward. The mast bolt pattern and diagonal camera-board slots are
unchanged, so the bracket is a direct replacement for the v0.5.1 bracket.

Print `lm1_test_camera_bracket_15deg_v0.5.2.stl` in the supplied orientation
with 0.2 mm layers, four walls and 20–25% infill. Reuse the existing four mast
fasteners and camera hardware. Install the bracket with the lens facing through
the open mast frame and the top of the camera tipped toward the rear.

The diagonal slots support nominal square camera-hole patterns from 24 to
34 mm. Use insulating spacers between the camera PCB and printed bracket, and
leave enough ribbon-cable slack to avoid pulling the camera out of alignment.

To regenerate all v0.5.2 test-stand files, keep `lm1_case_v0_2_0.py` beside
`lm1_test_v0_5_2.py`, install the packages in `requirements-cad.txt`, and run:

```powershell
python lm1_test_v0_5_2.py
```

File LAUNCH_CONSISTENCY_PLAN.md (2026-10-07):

# LM1 — Launch Data Consistency Plan

Why shot-to-shot numbers wobble, what the OV9281 datasheet says we're doing
right and wrong, and a no-new-hardware plan to make results repeatable.

Status: analysis + plan. No hardware purchases required.

---

## 1. TL;DR

The monitor is fighting two physics problems at once, and compounding both by
running the sensor **above its datasheet frame-rate envelope**.

1. **A golf ball at 30–70 m/s needs a shutter ≤ ~57 µs** (driver) to keep blur
   under 4 mm. A 3 µm pixel at 30–100 µs collects very few photons, so the image
   is shot-noise-limited. Noise makes the ball edge wander, and the edge is what
   every sub-pixel centroid / circle fit / velocity fit is built on.
2. **Velocity is a derivative.** You get 3–5 samples for a driver, each noisy.
   Few noisy samples → large variance in speed and launch, exactly the
   "inconsistent" behaviour you're seeing.
3. We make both worse by running **640×400 @ 242 fps**. The datasheet specifies
   **VGA @ 180 fps** and **1280×800 @ 120 fps**. 242 fps is ~35 % above the VGA
   ceiling — there is zero readout headroom, so any host hiccup drops frames or
   shifts timing, and the software stagger/sync has no margin to correct with.

The good news: the sensor choice is right (global shutter, mono, high NIR QE),
the timestamping is right, and a lot of the hardening already exists. Most of the
fixes are tuning, not construction.

---

## 2. What the OV9281 datasheet says

Sources: [OmniVision OV9281 product page](https://www.ovt.com/products/ov9281/) and
[OV9281 product brief](http://www.ovt.com/wp-content/uploads/2024/05/OV9281-PB-v1.4-WEB.pdf).

| Datasheet fact | What it means for us |
| --- | --- |
| 1/4", 1280×800, **3.0 µm** pixel, OmniPixel®3-GS **global shutter** | Global shutter = no rolling-shutter skew on a fast ball (correct choice). Small pixel = small full-well = low SNR at short exposure (our #1 limit). |
| **Monochrome**, "best-in-class NIR QE" | No Bayer filter → full spatial resolution + good response to the IR ring. Right sensor for IR-lit, high-speed machine vision. |
| **1280×800 @ 120 fps; VGA (640×480) @ 180 fps** | **We run 640×400 @ 242 fps — above the VGA ceiling.** This is the single most important finding. |
| 2-lane MIPI, 8/10-bit RAW | 10-bit is there; the 8-bit ISP path crushes the low end (see §3.2). |
| **Built-in strobe control + LED PWM** | The sensor can drive/phase a light to exposure. We instead let the ESP32 ring free-run and drift. Untapped. |
| 2×2 binning, 2:1 / 4:1 subsampling, ROI / context switching | We use subsampling to reach 640×400; binning is a cheap SNR lever we don't use. |

### 2.1 The frame-rate envelope (why 242 fps is the problem)

- In-spec: **640×480 @ 180 fps** and **1280×800 @ 120 fps**.
- We run **640×400 @ 242 fps** — *faster than the sensor is specified for*.
- `DUAL_CAMERA_SETUP.md` already records the cliff: 243/244/245 fps "stalled
  during startup"; 280/300 fps (8-bit) failed the 250 µs timing gate; **242 fps
  was the fastest that "passed"**.

"Passed startup" is not "operates cleanly." At the edge, the readout has no spare
time. Raspberry Pi's own software-sync docs (linked in `DUAL_CAMERA_SETUP.md`)
say software sync needs **spare frame-rate capacity** to absorb timing
corrections — at 242 fps there is none. The result: occasional dropped frames,
irregular inter-frame gaps, and stagger phase drift, all of which silently make a
shot's velocity fit worse.

---

## 3. Root causes of inconsistency (ranked)

### 3.1 SNR at short exposure (fundamental, dominant)

`MAX_MOTION_BLUR_M = 0.004 m` and the blur gate force exposure ≤ ~57 µs at driver
speed. A 3 µm mono pixel at 30–100 µs under the IR ring collects few photons, so:

- Photon shot noise dominates → the ball's edge (used by `ball_edge_fit`,
  `_circle_candidates`, template matching) moves frame to frame.
- `EDGE_MIN_CONTRAST = 12` and `EDGE_MAX_RMS_PX = 0.8` are fought by noise; the
  sub-pixel peak interpolation quantises and jitters.
- Gain up to 16× is available and the auto-sweep will use it; the code itself
  measured **gain 16 → background noise σ≈32 grey levels** vs gain 4 → clean.
  High gain directly injects variance into the tracker.

**Effect:** even with perfect timing, per-sample position error is large, so the
velocity (slope) estimate varies shot to shot.

### 3.2 The 8-bit ISP crushes the signal we need

`camera_source.py` documents it precisely: the sensor is 10-bit, but the image
processor subtracts 64 counts of real signal and applies a ~0.45 gamma, so the
darkest ~3 % of the range becomes exactly 0. At 20–100 µs exposure, "99.8–100 %
of the 8-bit picture was 0 while the raw data held a clear signal." The primary
measurement path still runs on that crushed 8-bit picture; raw 10-bit is captured
but only used for the strobe-copy path.

**Effect:** the faint-but-real ball signal at short exposure is quantised away,
turning a weak gradient into a hard, noisy edge.

### 3.3 Few samples for the fit

`TRAJECTORY_MIN_FRAMES = 3`, "measured" needs 6. At 242 fps a driver moves ~29 cm
per frame. From `DUAL_CAMERA_SETUP.md`'s own table, at the 40–56 px ball sweet
spot a driver yields only **1–3 frames**; to get 4–5 you must pull back to ~1 m
where the ball shrinks to 19–25 px (below the reliable 40 px floor). There is a
hard geometric conflict between *trackable ball size* and *visible flight path*.

**Effect:** for the fastest clubs you are fitting a line through 3 noisy points —
variance is inherent, not a bug.

### 3.4 Illumination phase drift (indoor / strobe)

The detector normalises brightness per frame (`gain = bg.mean / frame.mean`),
which masks whole-frame flicker but does **not** restore a consistent *ball* SNR.
In strobe mode the ESP32 ring free-runs; the changelog notes bursts "straddle the
gap between exposures" and that "optical exposure is not claimed to be 20 µs."
Different frames see different flash phase → different brightness → different
centroid. The datasheet's **built-in strobe/LED PWM** would fix this but is
unused.

**Effect:** frame-to-frame brightness changes are indistinguishable from motion,
adding fit noise.

### 3.5 Calibration / setup variance

Stereo depth rests on the ground AprilTag + lens focus + stand rigidity. 3 µm
pixels with a short-focal lens mean a fraction-of-a-pixel calibration error is
millimetres at 1 m. `readiness.py` catches drift but is advisory only. Any stand
bump, focus shift, or tag move silently degrades every shot.

---

## 4. What is already good (keep these)

1. **Global shutter** is exactly the right sensor for a 70 m/s ball — no skew.
2. **Monochrome + high NIR QE** — no Bayer losses, IR ring is the right light.
3. **Real `SensorTimestamp`** for velocity (not host arrival time) — correct and
   essential; `DUAL_CAMERA_SETUP.md` verified offsets ≤ 54 µs.
4. **Software stagger** to double effective sample rate — clever; just needs the
   in-spec headroom to be reliable.
5. **Auto-exposure that judges the ball (99.5th pct) and respects per-club blur
   limits** — thoughtful and correct in principle.
6. **Raw 10-bit capture** to recover the signal the 8-bit path destroys — the
   right idea; it just isn't wired into the primary measurement yet.
7. **Readiness checks + plain-language rejection reasons** — good proactive
   diagnostics; the failure messages already tell you *why* a shot died.
8. **Debounced departure + template re-anchoring + false-removal rejection** —
   robust against hand-lift / club-occlusion false triggers.

---

## 5. The plan (no new hardware)

Ordered by expected impact on *consistency*.

### Phase 0 — Measure the variance (do first, ~1 session)

You cannot fix what you don't quantify. Take **20 identical shots** (same club,
same mat, same light, same ball placement) and, for each, record from the saved
`capture.json` / `analysis.json`:

- measured/estimated status and which gate failed
- ball diameter px, frame count used, fit residual (px/mm)
- `measuredFps`, max inter-frame gap, stagger phase/state, sync offset
- exposure µs and gain actually applied

Goal: a per-shot table that separates *detection failures* from *measurement
variance*. The existing `scripts/audit-capture.py` and
`scripts/review-capture-reliability.py` already read these captures — extend or
script the aggregation rather than writing new plumbing.

### Phase 1 — Bring the sensor back inside its envelope (biggest single lever)

Drop the frame rate into spec and lean on the stagger for temporal density.

1. Run **640×400 @ ~180–200 fps** (at/below the VGA ceiling), both cameras
   staggered. Staggered, that is still ~360–400 effective samples/sec.
2. Alternatively evaluate **1280×800 @ 120 fps** full-res, staggered → the ball
   is ~2× bigger in pixels (50 px vs 25 px at 1 m), spatial resolution and travel
   room double, and 120 fps is rock-solid in-spec. Trade-off: fewer temporal
   samples per shot, so verify the driver still clears `TRAJECTORY_MIN_FRAMES`.
3. Measure, for each candidate rate: dropped-frame rate, max inter-frame gap,
   stagger phase drift over 60 s, and the 20-shot speed variance. **Pick the rate
   by variance, not by max fps.** (The current 242 fps was chosen because it was
   the fastest that *passed*, not the most *repeatable*.)

This is reversible via `PINPOINT_CAMERA_FPS` in `/etc/default/pinpoint` — no code
change to try.

### Phase 2 — Stabilise the light (remove flash-phase noise)

1. **Measure in "Flat" (ring steady), not "Strobe".** Strobe captures are already
   saved-for-review-only and carry no measurements; steady light is the only mode
   that gives consistent frame-to-frame ball brightness. Auto-set already prefers
   Flat unless daylight is enough.
2. Prefer the **lowest gain that still exposes the ball** (target ≤ 4×, never
   16×). Buy brightness with the ring position/intensity and camera distance, not
   gain.
3. (Optional, existing hardware only) The OV9281 has **built-in strobe control /
   LED PWM**. Investigate driving the existing ESP32 ring from a signal derived
   from the sensor's exposure (via libcamera's flash/strobe controls or a GPIO on
   the existing camera module) so every flash lands deterministically inside every
   exposure. This is a firmware/software change; treat it as a stretch goal after
   Phases 1–2, and only if strobe is ever needed for measurement.

### Phase 3 — Use the raw 10-bit signal for measurement (SNR)

1. Run the **ball edge / circle fit and centroid on the linear raw 10-bit data**
   (`raw_frames.py` already preserves it; `RAW_SCALE` / `raw_black_level` are
   already in place), instead of the gamma-crushed 8-bit picture. At short
   exposures this is the difference between "real signal" and "exactly 0".
2. Keep the 8-bit path only for display/preview and the presence detector.

### Phase 4 — More usable samples per shot (geometry, not hardware)

1. Enforce the documented sweet spot operationally: ball **40–56 px**, near the
   **upstream edge**, camera ~1 m back for fast clubs. `readiness.py` already
   computes this — make it a *hard* gate for "measured" grade, not advisory.
2. Reject (downgrade) any shot with **< 5–6 frames** or a **frame gap** rather
   than letting a 3-point fit carry "measured" status. The code already has the
   `FREE_START_MIN_FRAMES = 6` / measured-needs-6 logic; extend the same bar to
   the mono path.
3. Verify the frame-gap warning (`intervals.max() > 2.5 / fps`) actually
   downgrades the shot; it currently only appends a warning string.

### Phase 5 — Calibration & validation discipline

1. Re-run lens + stereo + AprilTag calibration at the **exact** resolution and
   fps you settle on in Phase 1 (calibration is mode-specific).
2. Build a **no-hardware reference** for repeatable validation: roll balls down a
   fixed ramp/incline (known height → repeatable speed), or putts of known
   distance, and use those to measure shot-to-shot variance. Compare against the
   same reference for every tuning change.
3. Use `readiness` "Camera alignment" (ray-gap / rest-height) before each session;
   treat a `fail` there as blocking, not advisory.

### Phase 6 — Surface consistency to the user

1. Add a per-shot / session summary showing **why** shots varied: blur, ball size,
   frame count, frame gaps, SNR, gate failures. The data already exists in
   `diagnostics`; it just isn't surfaced as a trend.
2. Keep the rejection hints — they are already good — but tie them to the new
   variance table so a user can see "driver shots fail 60 % on blur/coverage"
   at a glance.

---

## 6. What NOT to do

- **Do not raise fps further.** 242 fps is already above spec; more fps buys
  nothing but dropped frames and drift.
- **Do not chase gain to 16×.** Noise is the enemy of consistency, and gain is
  noise.
- **Do not trust strobe mode for measurement.** It is review-only by design.
- **Do not keep the ball centred.** Half the frame is wasted behind the ball;
  upstream-edge placement is the single cheapest "more frames" win.
- **Do not tune constants to make numbers look right.** Reject unsupported
  metrics (the code already does this; keep it).

---

## 7. Expected outcome

| Change | Expected effect on consistency |
| --- | --- |
| In-spec frame rate (Phase 1) | Fewer drops, stable timing/stagger → cleaner fits |
| Steady light + low gain (Phase 2) | Stable ball SNR → stable centroid |
| Raw 10-bit measurement (Phase 3) | Real signal instead of quantised 0 → better edges |
| More frames + hard gates (Phase 4) | Velocity fit from 5–6 points instead of 3 |
| Variance table + reference (Phase 0/5) | Visible, measurable progress instead of guesswork |

**Reality check:** this is still a 1 MP, 3 µm-pixel camera measuring a 70 m/s
ball at 1 m. Absolute accuracy will remain limited and should be validated
against a real reference monitor before trusting any number. This plan targets
**repeatability** (same input → same output), which is the concrete symptom you
asked about and is fully addressable with the hardware you already have.

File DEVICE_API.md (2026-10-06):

# Pinpoint Device BLE Protocol

Protocol version 2.31.0

Protocol 2.31.0 permits a three-frame stereo trajectory to receive measured-grade status when every timing, geometry, calibration, and fit-quality gate passes. Protocol 2.30.0 permits `putt.strike: null` when face contact is unavailable and adds `putt.airborne` for launch above 10°. Ball/putter speed, smash and launch inputs are still required before a putt result is emitted.

Protocol 2.29.0 adds `captureMode` (`full-shot` or `putting`) to status responses and status events. Clients should use this device-reported value when showing the active mode after reconnecting. Sending `arm` with a different mode switches modes while armed, provided a capture is not processing; the app also waits until the ball is removed.

Protocol 2.27.0 permits a `shared-tag-stereo-two-point-v1` speed-only estimate.
Capture `tracking.status` is `stereo-two-point`, with `speedOnly: true` and
`speedUncertaintyPct`; launch angle, direction, and carry remain unavailable.
The resting-ball/impact bracket checks the two-point path but is not treated
as an exact third timed observation.

Protocol 2.26.1 adds `tracking.monoFallback`, `tracking.stereoFailure`, and
`tracking.monoFailure` to capture summaries. `tracking.source` is null when no
ball speed survived validation; a rejected stereo fit does not count as a
stereo-matched measurement.

Protocol 2.26.0 changes the default lower-camera placement `preview.roi` to
`[0,0.30,0.50,0.98]` and its `preview.target` to `[0.25,0.72]`. This is a
placement/arming region only; outgoing-ball analysis continues across the full
frames from both cameras. Custom `PINPOINT_BALL_ROI` values remain supported.

For the fixed left-to-right rig, `startDirectionDeg` remains a signed number:
positive is right/toward the cameras, negative is left/away, and zero is the
bottom camera's across-image target line. This is a display clarification in
app 3.18.2, not a protocol sign change.

Protocol 2.25.1 preserves tag-free club measurements when no club-marker
profile ID is attached to the capture. A present marker profile ID still must
match the selected club. The returned metric values and confidence retain the
camera's estimated provenance.

Protocol 2.25.0 adds `capture.measurements.carryModel` with `version`,
`spinSource`, `spinRpmUsed`, and `attackAngleDegUsed`. `estimatedCarryM` is
always a modeled still-air target-line distance to the launch-height plane;
it is never a measured landing. Missing spin uses the selected club's average,
scaled for ball speed and adjusted for attack angle only when that angle was
resolved. Wind, terrain, spin-axis curvature and landing-height differences
are not included.

Protocol 2.23.0 adds `measurements.shotEvidence` (`status`: `club-motion-observed`
or `motion-only`, `clubFrames`, `reason`) and `measurements.tracking.source`
(`stereo` or `single-camera`). Full-shot consumers must not promote or send a
`motion-only` capture as a shot. Putting still accepts resolved ground motion.
The matched-pair count describes detection evidence; `source` identifies the
fit actually used for the returned launch metrics.

Protocol 2.32.0 changes the meaning of `motion-only`: the ball was measured but no
pre-impact club track was resolved. Such a capture is a shot with club speed,
smash and strike unavailable. A new full-shot status, `not-a-strike`, marks
movement that cannot be a strike (ball speed under 2 m/s, direction more than 60°
off the target line, or a ground roll with no club seen); consumers must not
promote or send it. Putting captures are never classified this way.

Protocol 2.38.0 adds staggered capture diagnostics to `status.camera`: `syncMode` may be `"stagger"`,
with `staggerState` (`locking`, `locked`, `drift-soon`, `drifted`, `resyncing`, `failed`), `staggerPhase`
(the upper camera's offset behind the lower one as a fraction of a frame, 0.5 ideal) and `staggerRelocks`.
While the state is `drifted`, `resyncing` or `failed` the Pi does not arm on a ball. Saved bursts carry
`dualCamera.mode: "stagger"` and `dualCamera.staggerOffsetUs`; `pairOffsetsUs` is then about half a frame,
not zero, and `stereo.staggered` and `stereo.instants` appear in the analysis diagnostics.

Protocol 2.37.0 adds `status.rig`: `{mode: "rig"|"tag", pitchDeg, rollDeg, heightMm, source: "default"|"tag-derived"|"measured", createdAt, error?}`.
In `rig` mode (the default, `PINPOINT_GROUND_MODE=tag` restores the old behaviour) the Pi takes its ground
from the stand: gravity runs down the rig at the stored camera pitch, the target is to the right of the
bottom camera, and the camera height is a stand constant corrected on every shot from the resting ball
(up to 40 mm; `diagnostics.surface`). No AprilTag is looked for; `groundCalibration` may be null and the
readiness `ground` item reports the rig constants. `diagnostics.groundPose.source` is `level-rig`,
and `diagnostics.calibration.groundMode` records the mode used. Constants live in `rig.json`
(`PINPOINT_RIG_PATH`); `python rig_pose.py --from-tags|--set PITCH HEIGHT|--show` manages them.

Protocol 2.36.0 adds a `placement` readiness item (`status`, `detail` with the move to make,
`clubFrames`, `ballFrames`, `ballDiameterPx`, `speedBasis`) and `diagnostics.surface` on each
analysis (`source: resting-ball|calibration`, `offsetMm`, `rayGapMm`, `frameIndex`).

Protocol 2.35.0 adds `{"id":"..","type":"captureClip","captureId":"capture-..","startFrame":100,"count":8}`
(count 1-8). It returns `{captureId, mimeType, frameCount, cropBox:[x,y,w,h], frames:[{frameIndex,
timeMs, base64}], impactFrameIndex, firstMovingFrameIndex, lastStationaryFrameIndex}`: lower-camera
frames cropped to one fixed box around the resting ball (club approach behind it, flight ahead and
above), 240 px wide, brightened for display only. Use a 30-second timeout; the first request can
wait while the Pi finishes saving the burst.

Protocol 2.34.0 adds named clubs. `setClub` and `arm` accept an optional
`"bagClub": {"id": "bag-...", "name": "Vokey 56", "faceWidthMm": 78, "faceHeightMm": 50}`
(id 1-64 of letters, digits, `-`, `_`; name 1-40 characters; face size optional but both or
neither, 55-135 x 20-80 mm). `clubId` stays the club type. Captures and legacy shot events then
carry `bagClubId` and `bagClubName`, and `status.selectedBagClub` reports `{id, name}` or null.
A face size is written to the club profile with `"source": "app"`; a profile without that
marker is never replaced or removed. Omitting `bagClub` clears the named club.

Protocol 2.32.0 also adds pre-shot readiness. When a ball arms, the Pi checks the
resting ball in both cameras and sends
`{"type":"readiness","data":{"version":1,"status":"ok|warn|fail","items":[...],"checkedAt":"..."}}`.
Each item has `id` (`exposure`, `ground`, `stereo-rest`, `club-profile`), `label`,
`status` and a `detail` saying what will fail and how to fix it; `stereo-rest` also
reports `offsetPx`, `rayGapMm` and `heightErrorMm`. The same object is returned as
`status.readiness`, re-evaluated for the current club and mode (null on the
simulator backend). It is advisory and never blocks a capture.

Protocol 2.22.0 adds a bounded `capture.measurements.tracking` summary to BLE
capture events and `listCaptures`: `status` (`failed`, `stereo-matched`, or
`single-camera`), `lowerFrames`, `pairedFrames`, `pairedFrameIndices`, `spanMs`,
`detection`, `imageResidualPx`, `failure`, and candidate `rejections`. Full
per-frame geometry stays in saved `analysis.json`. A failed track has null
physical metrics; the app does not replace missing ball speed with a club
profile or send it as a simulator shot. Three stereo pairs can produce an
estimate, while at least three clean pairs are required for measured-grade status.

Pi service 0.33.0 adds an optional stereo launch path without changing the BLE
contract. When both cameras have valid lens intrinsics and saved AprilTag poses,
paired ball detections can triangulate depth and recover speed, launch and start
direction even when the monocular ball track or outline fit fails. The capture's
`measurements.method` and `measurements.diagnostics.stereo` identify this path;
missing calibration or failed stereo quality gates leave the metrics
unavailable. The upper pose must be within five seconds of the lower pose, and
each paired exposure must be within 250 μs.

Protocol 2.17.0: `{"type":"status","mtu":247}` states the connection's negotiated ATT MTU (23–517). The Pi then sends notification chunks of `min(244, mtu - 3)` bytes and reports `notificationChunkBytes` in status; a status request without `mtu` restores 20-byte chunks. Send it first on every connection.

Service 0.15.0 adds `capture.measurements`: a `method` string, per-field `metrics` with `value` (number or null), `unit`, `status` (`estimated`/`unavailable`), and `reason`. Full 3D/spin traces are stored in Pi `analysis.json`; the BLE summary omits them to bound transfer size. Complete core results also emit the existing shot/putt shape with `simulated: false` and `measurementSource: monocular-estimate`. Optional metrics are omitted when unavailable. Reported metrics also carry `confidence` (0.05–0.95) and `checks` (`[{label, passed}]`); `status` is `measured` only when every check passed, otherwise `estimated`. Confidence is a quality grade, not a calibrated error bound. See LAUNCH_MEASUREMENTS.md for setup and coordinate conventions.

Service 0.27.0 adds `clubPathDeg` and `attackAngleDeg` to `metrics`, using the same value/unit/status/reason shape, so existing consumers need no change and may ignore them. The tag-free clubhead path supplies `clubSpeedMps`, `smashFactor` and `attackAngleDeg` when no club AprilTag is calibrated; `clubPathDeg` comes only from a calibrated club tag, because the silhouette path's swing plane is defined by the ball's own direction and a path taken from it would merely restate `startDirectionDeg`. `diagnostics.clubSilhouette` reports method, candidate and accepted frame counts, fit residual and, when resolved, shaft lean. Everything on this path is an estimate whose reason names the swing-plane assumption behind it, and `strikeXmm`/`strikeYmm` additionally require a measured `club-profile.json` rather than being inferred.

Start direction now defaults to a target line taken from the camera's across-image axis, so it no longer requires the rolled-ball calibration; `diagnostics.calibration.targetHeadingSource` is `camera-axis` or `rolled-ball`, and a saved explicit line still wins. Captures also carry `targetLineSource` alongside `targetLineHeadingDeg`.

Camera workflow (service 0.23.2): the default detection ROI is `[0.05,0.30,0.95,0.98]`, covering 61.2% of the camera frame. Status includes `automaticCapture` and, for CSI cameras, `exposureControl` and `gainControl` capability metadata. `autoCalibrateExposure` (service 0.28.0) measures the current lighting and picks both values automatically; manual control is unaffected. `setExposure` applies and persists a measurement-safe 50–250 μs manual exposure; `setGain` applies and persists OV9281 analogue gain from 1×–16× while manual exposure is active. Both commands require the device to be ready. Automatic camera departures emit `capture` events containing `id`, optional `captureId`, `capturedAt`, `clubId`, `mode`, `classification`, `frameCount`, `captureDurationMs`, `measuredFps`, backward-compatible `impactFrameIndex`, `coarseDepartureFrameIndex`, nullable `lastStationaryFrameIndex` and `firstMovingFrameIndex`, `imageFrameIndex`, `track`, `warnings`, and a bounded JPEG `image` (`mimeType`, `base64`). Measurements can include `tagPoseFrameIndex`, `tagPoseReprojectionErrorPx`, and quality warnings: the best of up to 12 static ground-tag detections is used, 1–3 px poses are labeled lower-confidence, and poses above 3 px are rejected. When the strict full-disc silhouette path cannot resolve three points, a tracker-guided partial-silhouette fallback may estimate launch only after independent image-plane agreement, three consecutive frames, stable apparent radius and the existing 8 mm 3D fit gate. Saved `capture.json` manifests include `ballBounds` for exact offline replay. A resolved contact window spans the last resting-ball frame and first coherent moving-ball frame; the coarse trigger is diagnostic and is not impact. Classification is `motion-observed` or `unconfirmed-departure`, never a claim of measured club contact. Unsupported physical metrics are omitted. `listCaptures` retrieves the newest ten records, including images; the Pi retains 100 captures by default, configurable with `PINPOINT_CAPTURE_RETENTION`. Use a 60-second BLE timeout. Existing `captureFrame` retrieves a frame from the named burst and includes all marker fields. Unsolicited `error` messages must be displayed. Automatic capture disables manual synthetic triggering. Explicit demo/test mode keeps the existing synthetic `shot`/`putt` contract.
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

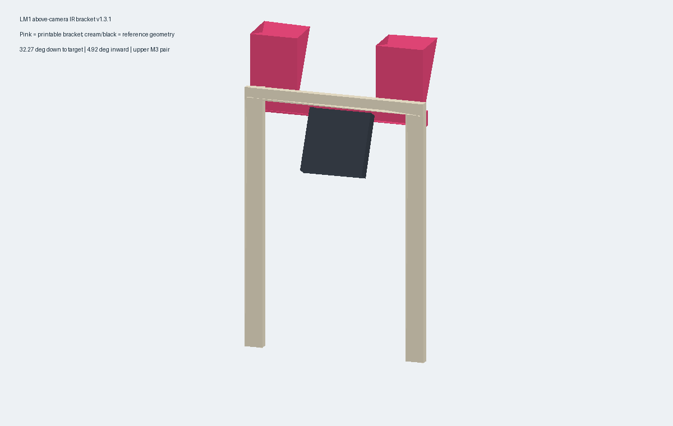
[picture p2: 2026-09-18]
hardware/ir-top-bracket-v1.3.1/preview.png

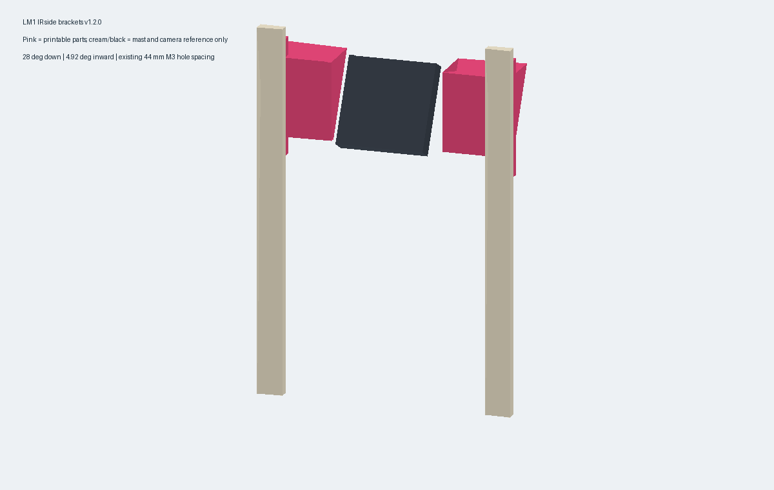
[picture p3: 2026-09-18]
hardware/ir-side-bracket-v1.2.0/preview.png

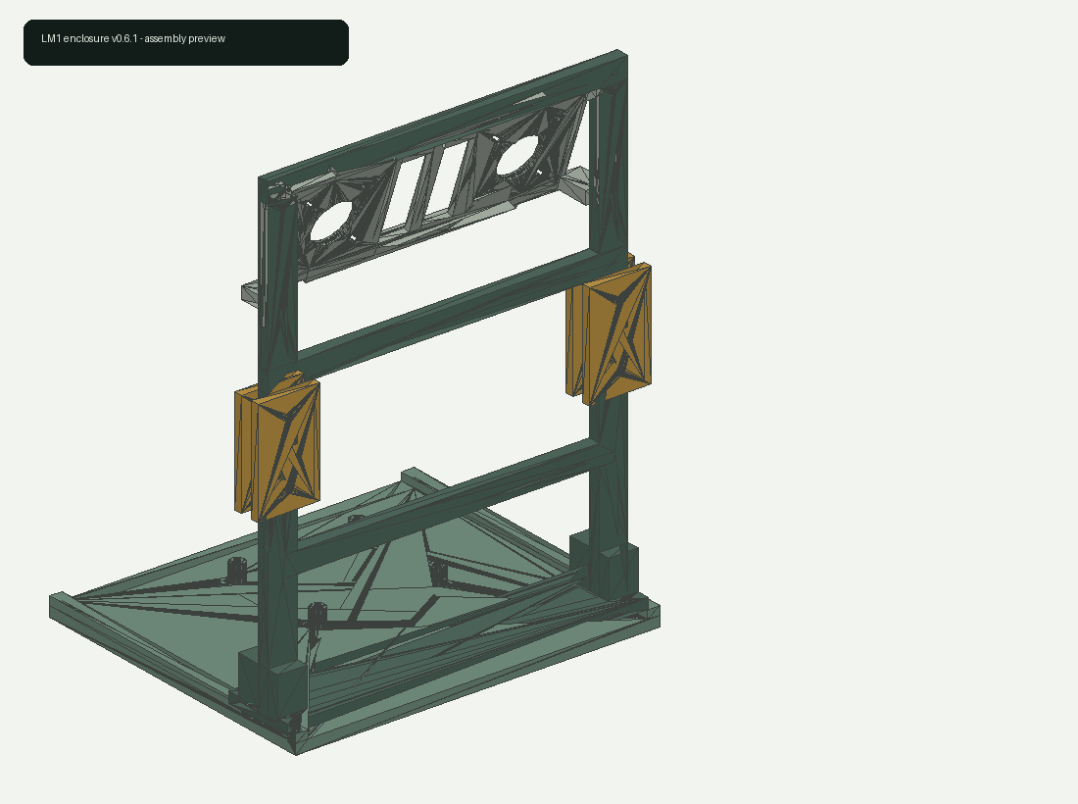
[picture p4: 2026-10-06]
hardware/enclosure/stl/v0.6.1-stereo-modular/preview.png

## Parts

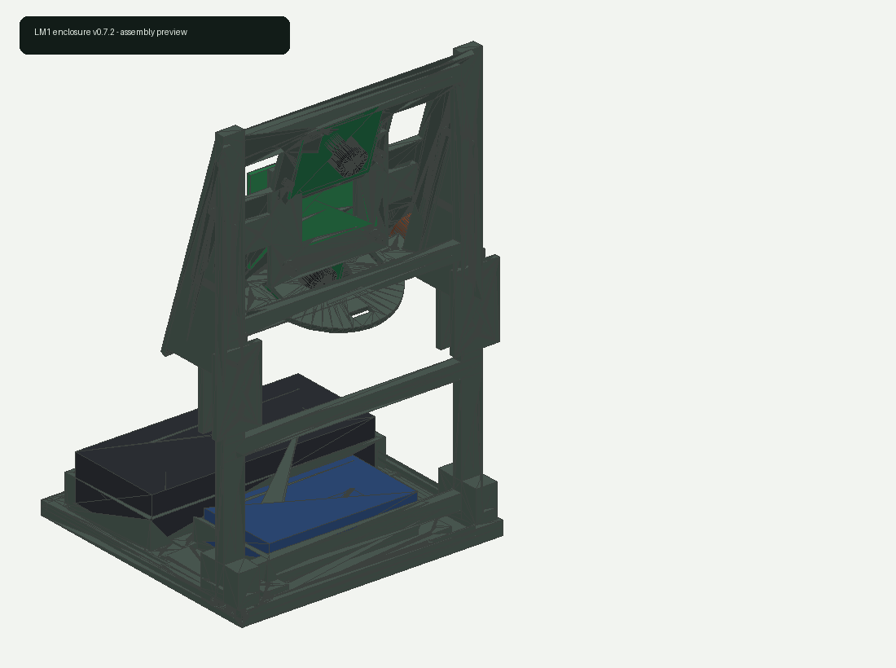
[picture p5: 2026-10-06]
hardware/enclosure/stl/v0.7.2-vertical-development/component-render.png

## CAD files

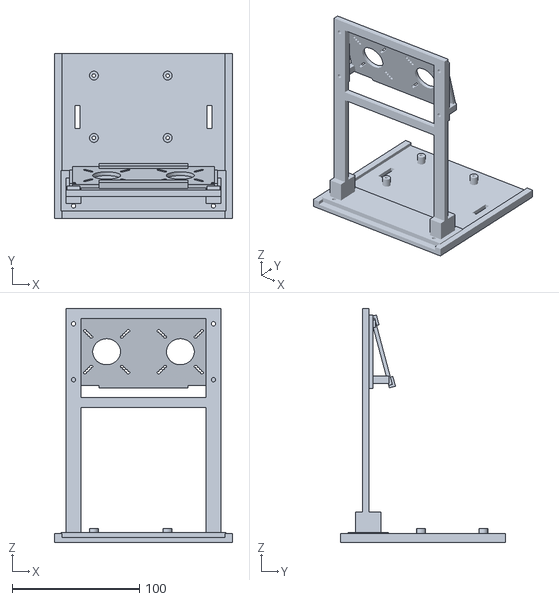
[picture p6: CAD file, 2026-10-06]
hardware/enclosure/stl/v0.5.3-test/assembly_reference_v0.5.3.stl
140.0 x 130.0 x 184.0

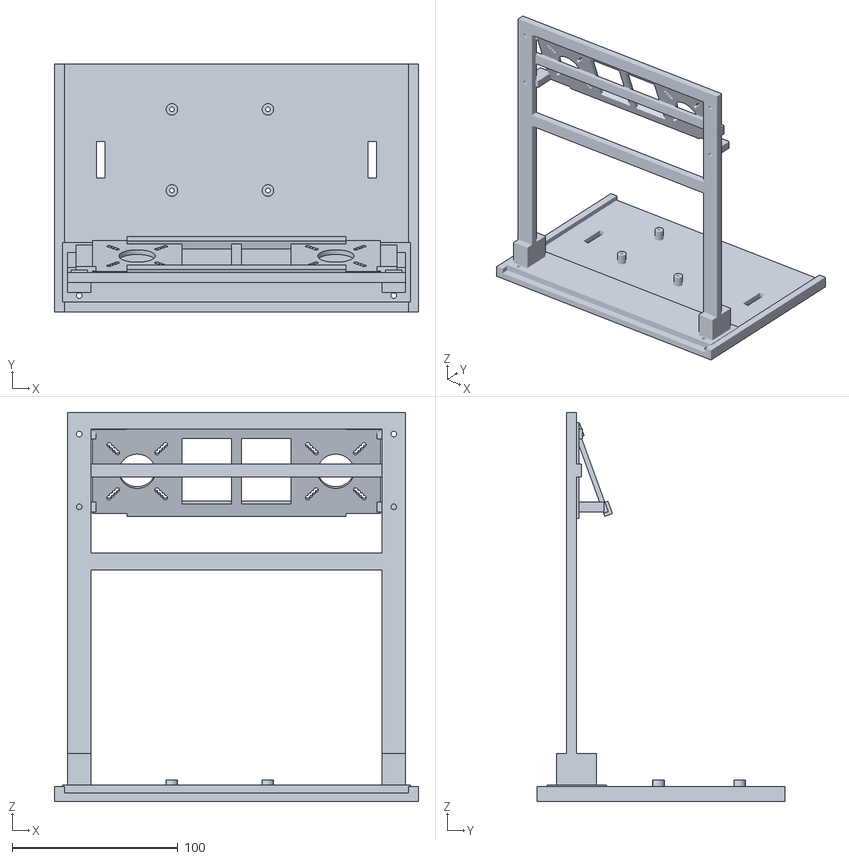
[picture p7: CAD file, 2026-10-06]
hardware/enclosure/stl/v0.6.0-stereo/assembly_reference_v0.6.0.stl
220.0 x 150.0 x 235.0

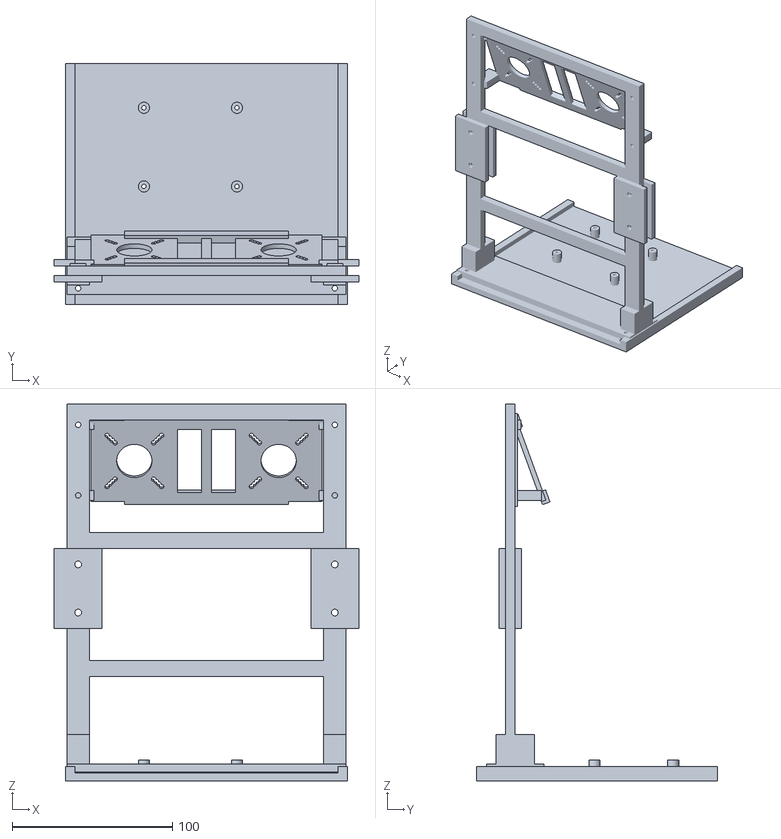
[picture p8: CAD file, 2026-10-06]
hardware/enclosure/stl/v0.6.1-stereo-modular/assembly_reference_v0.6.1.stl
190.0 x 150.0 x 235.0

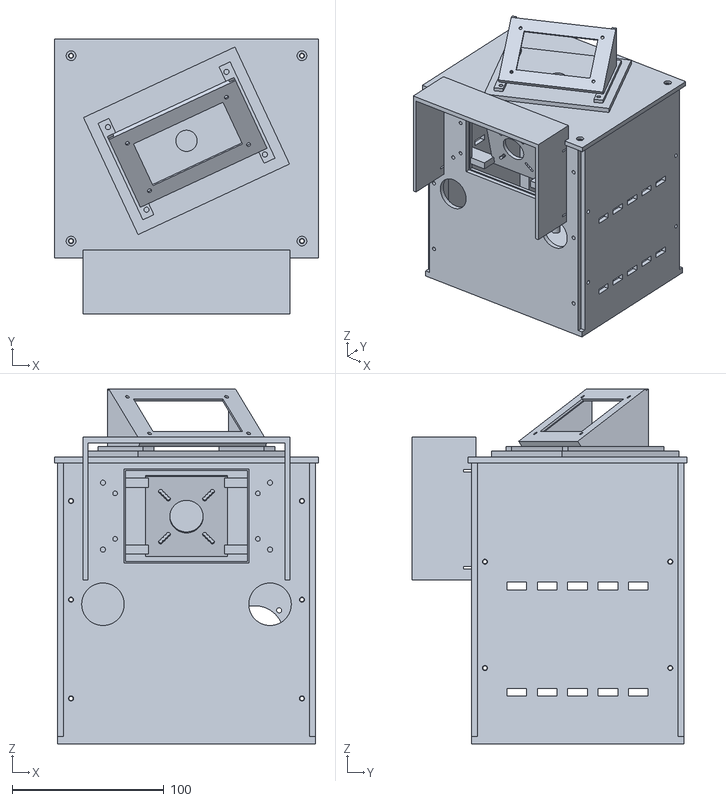
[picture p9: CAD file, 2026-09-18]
hardware/enclosure/stl/v0.4.0/lm1_assembly_reference_v0.4.0.stl
174.0 x 181.0 x 233.7

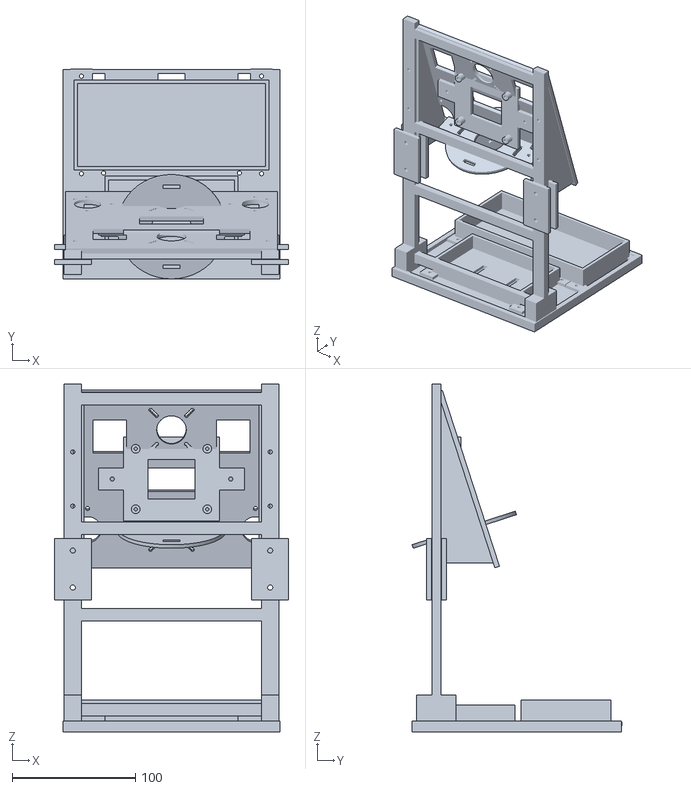
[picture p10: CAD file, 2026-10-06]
hardware/enclosure/stl/v0.7.2-vertical-development/assembly_reference_v0.7.2.stl
190.0 x 170.5 x 282.0

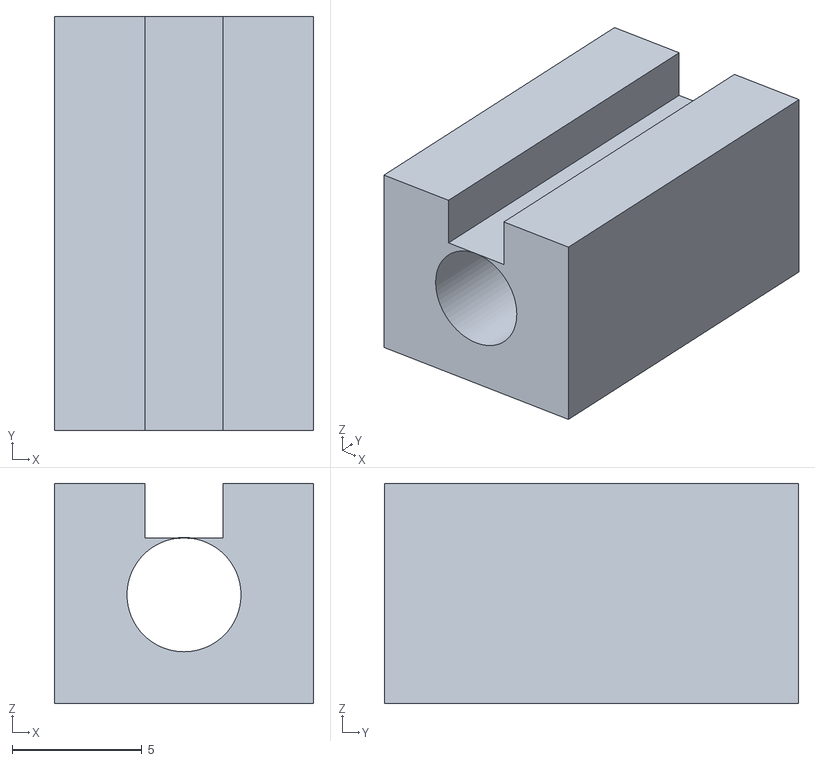
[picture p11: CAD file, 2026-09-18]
hardware/adhesive-wire-clip-v1.2.0/lm1-vertical-1-wire-clip-v1.2.0.stl
10.0 x 16.0 x 8.50

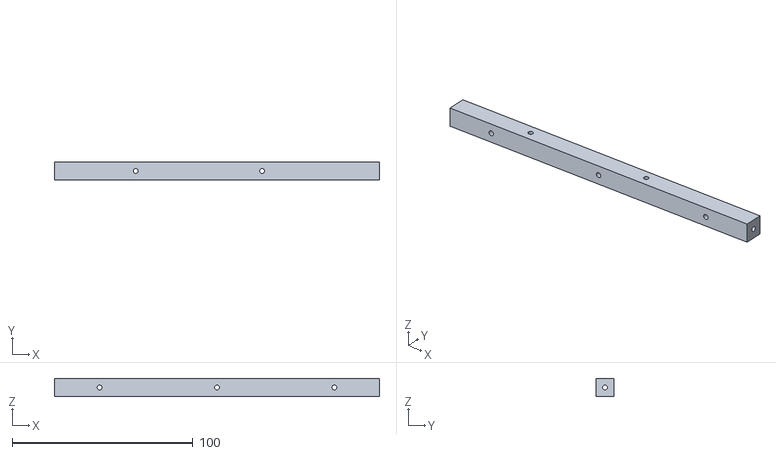
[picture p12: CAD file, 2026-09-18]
hardware/enclosure/stl/v0.4.0/lm1_corner_rail_v0.4.0.stl
180.0 x 10.0 x 10.0

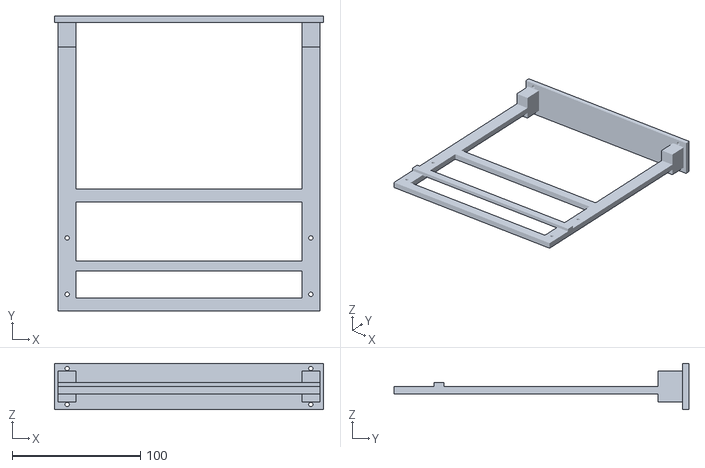
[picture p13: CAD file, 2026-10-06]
hardware/enclosure/stl/v0.6.0-stereo/lm1_test_camera_mast_v0.6.0.stl
210.0 x 230.0 x 36.0

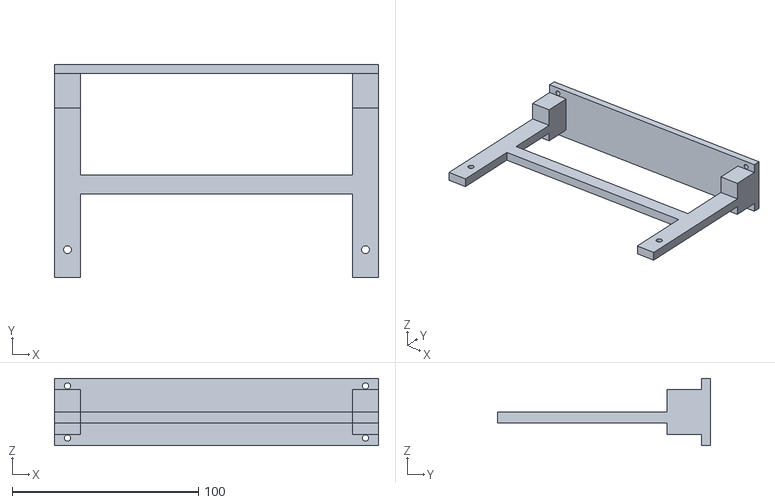
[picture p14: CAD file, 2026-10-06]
hardware/enclosure/stl/v0.6.1-stereo-modular/lm1_mast_lower_v0.6.1.stl
174.0 x 114.5 x 36.0

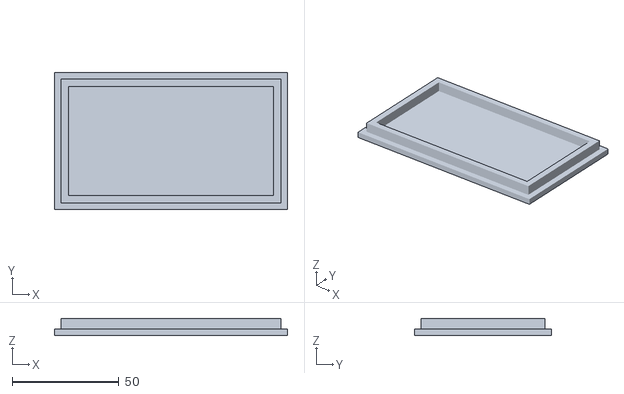
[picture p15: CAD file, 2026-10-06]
hardware/enclosure/stl/v0.7.2-vertical-development/lm1_lipo_lid_provisional_v0.7.2.stl
109.0 x 64.0 x 8.00

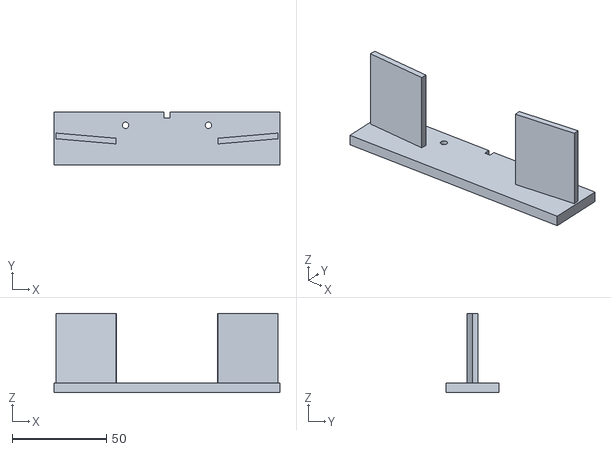
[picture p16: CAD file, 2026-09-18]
hardware/ir-crossbar-v1.0.1/ir-crossbar-v1.0.1.stl
120.0 x 28.0 x 42.0

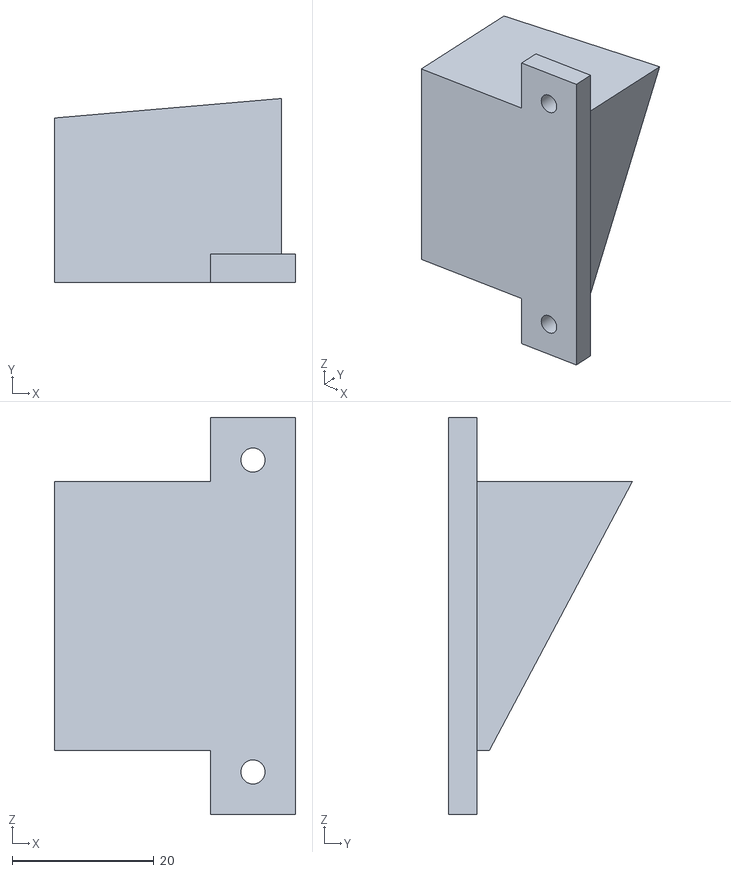
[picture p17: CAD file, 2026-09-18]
hardware/ir-side-bracket-v1.2.0/lm1-ir-side-bracket-right-v1.2.0.stl
34.0 x 26.0 x 56.0

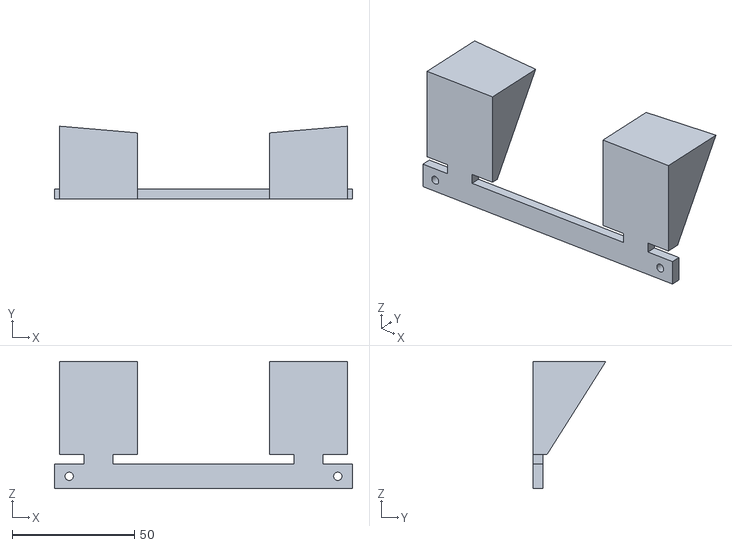
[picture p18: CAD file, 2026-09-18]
hardware/ir-top-bracket-v1.3.1/lm1-ir-top-bracket-v1.3.1.stl
122.0 x 29.8 x 52.0

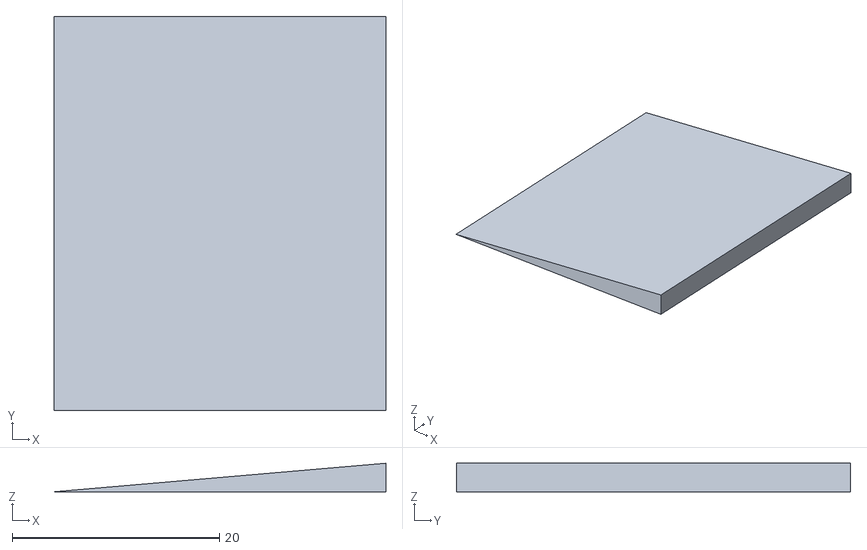
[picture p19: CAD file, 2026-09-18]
hardware/ir-wedge-v1.0.2/ir-wedge-v1.0.2.stl
32.0 x 38.0 x 2.75

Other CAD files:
hardware/enclosure/stl/v0.4.0/lm1_base_v0.4.0.stl
hardware/enclosure/stl/v0.5.3-test/lm1_test_dual_camera_bracket_15deg_v0.5.3.stl
hardware/enclosure/stl/v0.6.1-stereo-modular/lm1_dual_camera_bracket_20deg_v0.6.1.stl
hardware/enclosure/stl/v0.7.2-vertical-development/lm1_pi5_head_cradle_v0.7.2.stl
hardware/adhesive-wire-clip-v1.0.0/lm1-adhesive-wire-clip-v1.0.0.stl
hardware/adhesive-wire-clip-v1.1.0/lm1-vertical-2-wire-clip-v1.1.0.stl
hardware/enclosure/stl/v0.2.0/lm1_assembly_reference_v0.2.0.stl
hardware/enclosure/stl/v0.2.0/lm1_camera_mount_13deg_v0.2.0.stl
hardware/enclosure/stl/v0.2.0/lm1_chassis_v0.2.0.stl
hardware/enclosure/stl/v0.2.0/lm1_led_adapter_v0.2.0.stl
hardware/enclosure/stl/v0.2.0/lm1_oled_retainer_v0.2.0.stl
hardware/enclosure/stl/v0.2.0/lm1_sun_hood_v0.2.0.stl
hardware/enclosure/stl/v0.2.0/lm1_top_oled_v0.2.0.stl
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

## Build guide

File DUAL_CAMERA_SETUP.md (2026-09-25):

# Dual OV9281 setup — v1.2.0

App 3.14.0 / build 50 · Pi service 0.33.0 · protocol 2.21.0.

## Enclosure and camera roles

This profile follows the latest vertical enclosure v0.7.2. The user confirmed
that **CAM0 is the lower camera**. It detects the ball and triggers both saved
views. CAM1 is the upper camera. The stand's nominal lens heights are 162.5 mm
and 247.5 mm, its vertical baseline is 85 mm, and both cameras point down 18°.
These CAD dimensions are mounting references, not measured stereo calibration.

1. Keep both lenses parallel in the carrier. Aim the whole enclosure so the
   ball and its initial path are visible in both previews.
2. Turn on the hitting-area illumination. Both views were still very dark at
   the saved short shutter setting during the installation checks.
3. Reload app 3.13.0 and connect. Device shows the lower placement preview,
   upper preview, matched frame rate and timing status. Use the existing shutter
   and brightness controls; both cameras receive the same settings. Automatic
   brightness uses the lower view, so also inspect the upper view for clipping.
4. Put a printed target at ball distance and focus each lens manually. The
   existing numeric sharpness score refers to the lower view only.
5. Remove the ball and hands, then reset the empty background after aiming or
   changing lighting. Place a ball in the lower preview's detection region.
   When it departs, both views are saved under one capture ID. The upper view
   accompanies the initial capture image and matching replay frames.

## Calibrating each camera

App 3.14.0 calibrates the lenses one camera at a time. On the Calibration
screen, the lens calibration card has a **Lower CAM0 / Upper CAM1** selector.
The preview under it shows the selected camera's live view, and the counts,
Clear images and Run calibration all act on that camera alone.

1. Select a camera, hold the printed checkerboard in its preview and capture at
   least 12 diverse tilted views. Views are never shared between cameras.
2. Run calibration for that camera, then repeat for the other one. The upper
   camera's intrinsics are written to
   `/var/lib/pinpoint/intrinsics-secondary.json`
   (`PINPOINT_SECONDARY_INTRINSICS_PATH`).
3. Running it for the lower camera clears the saved ground calibration and
   target line, because launch geometry is built on that lens; capture the
   AprilTag again afterwards. A run for the upper camera leaves them untouched.

Upper CAM1 is selectable only while the second stream is running; a capture
request for it is refused otherwise rather than saving the lower view.

The same fixed AprilTag 36h11 ID 0 calibration must be captured in both camera
views after installing each camera's intrinsics. Each stored camera pose uses
the tag's shared coordinate frame; together they define the stereo geometry.
The primary camera remains the shot trigger. When its own trajectory fit
succeeds, the upper image cross-checks the ball along the expected ray path.
When that fit fails, both image bursts independently supply ball-sized circle
candidates. The service pairs them using the calibrated rays, apparent ball
size and a coherent 3D path. Changing either camera, lens focus, tag location
or hitting surface requires recalibrating the affected lens/pose before trusting
stereo results.

## Stereo measurement quality gates

Service 0.33.0 keeps the monocular fit as the first path and runs stereo as a
cross-check. If the monocular fit fails, independent detections from both views
can recover a trajectory even without its lower-view track. A stereo-only
result needs at least three paired detections and passes paired timing (≤250 μs),
median ray gap (≤3 mm),
resting-ball height (≤5 mm), start anchor (≤30 mm), and joint image residual
(≤3 px) checks. Failed gates leave the result unavailable. Review
`measurements.diagnostics.stereo` in `analysis.json` to see matches, rejected
frame numbers and reasons, calibration errors and fit diagnostics. These are still camera-derived
estimates until checked against a reference launch monitor.

## Designing for 240 fps: shot coverage

At 241.6 paired fps there are 4.14 ms between frames. The launch fit needs the
ball in at least 3 frames after impact (4 gives it a residual to check), so the
limit is how much of the ball's early path the camera sees, not the frame rate:

| Shot | Ball speed | Travel per frame | Path for 3 frames |
|---|---|---|---|
| Putt | 3 m/s | 1.2 cm | 4 cm |
| Wedge | 30 m/s | 12 cm | 37 cm |
| 7-iron | 54 m/s | 22 cm | 67 cm |
| Driver | 70 m/s | 29 cm | 87 cm |

Projected through the lens and ground pose saved with capture
`capture-1789515451301879262` (the lower camera about 34 cm from the ball, as
set up before the v0.7.2 stand), then with that camera pulled back along the
same aim:

| Camera to ball | Ball placement | Ball width | 7-iron frames | Driver frames |
|---|---|---|---|---|
| 34 cm (as saved) | mid-frame | 70 px | 0 | 0 |
| 34 cm | upstream edge | 72 px | 1 | 1 |
| 67 cm | upstream edge | 37 px | 3 | 2 |
| 99 cm | mid-frame | 24 px | 2 | 1 |
| 97 cm | upstream edge | 25 px | 5 | 4 |
| 129 cm | upstream edge | 19 px | 6 | 5 |

Frame counts are the minimum of the two possible values. "Upstream edge" means
as close to the image edge as the whole ball still fits; at about 1 m, placing
the ball 10% in from the edge drops the driver to 3 frames. Rolled putts get
dozens of frames in every case.

Conclusions:

1. 240 fps is enough for ball speed, launch and direction if the lower camera is
   about **1 m from the ball** and the ball sits near the **upstream edge** of
   the image. Half of a centred view is wasted behind the ball.
2. The ball is then about 25 px wide. That is fine for centroid tracking and
   depth from ball size, but too small for spin from surface marks. Spin stays
   estimated unless strobed multi-exposure is added later.
3. Check your own setup with **Calibration → Shot coverage** after saving the
   lens and AprilTag calibration, with a ball placed where you hit from. It
   uses the live ball position and the measured paired frame rate.

The v0.7.2 stand has no saved ground pose yet, so its coverage has not been
calculated. The table above describes the older lower-camera geometry.

## Capture settings and timing

- Two OV9281 streams at **640×400, requested 242 fps, 10-bit sensor mode**.
- CAM0 is the software timing server; CAM1 is the client. Each sensor is drained
  independently into a bounded queue. Frames are paired using SensorTimestamp.
- Each accepted pair must be within 250 μs. Missing cameras, missing timestamps
  or failure to acquire timing lock fail acquisition; they do not silently
  produce a single-camera capture in dual mode.
- SyncReady is intermittent libcamera metadata. Its last explicit value is
  retained, while timestamp differences are checked on every frame pair.
- Existing short shutter/gain settings and ball detection thresholds are retained.
- Existing buffer settings retain 325 frames per camera, about 1.34 seconds at
  the verified rate. Sensor timestamps retain any frame gaps.
- This is **software synchronization**. It does not establish externally
  validated exposure timing. Service 0.33.0 uses both views for triangulated
  launch estimates after per-camera lens and shared-tag ground calibration;
  physical accuracy still needs reference validation.

Raspberry Pi's [software synchronization documentation](https://www.raspberrypi.com/documentation/computers/camera_software.html#software-camera-synchronisation)
explains why spare sensor frame-rate capacity is needed for timing corrections.

## Verification on this Pi, 2026-09-22

- Both sensors open concurrently and deliver distinct image data.
- At requested 242 fps, a saved real burst contained 325 frames per camera at
  241.57 observed paired fps. Maximum timestamp offset: 40 μs.
- A 30-second run of the full detector and preview pipeline produced 4,832 paired
  frames in its final 20-second measurement window: 241.56 observed fps,
  maximum offset 54 μs, maximum adjacent-frame gap 4.189 ms. Nine previews
  contained both camera images. No physical shot was performed in this check.
- 243, 244 and 245 fps in 10-bit mode stalled during startup. At 280 and 300 fps
  in 8-bit mode, the pair failed the 250 μs timing gate. Requested 242 fps was
  therefore the fastest tested setting that passed the capture checks.
- Old one-camera captures remain readable. New captures place upper frames in
  `camera-secondary/` with their own manifest/contact sheet. The main
  `capture.json` records both camera indexes and each pair's timestamp offset.
- This 2026-09-22 acquisition verification predates service 0.32.0. At that
  time, upper frames did not inherit the lower camera's AprilTag calibration;
  capture the shared tag with both views to save each camera's pose before
  stereo estimates can be used.
- 197 Python tests passed on the Pi with test calibration/storage paths isolated
  from production data. App type checking, lint and the fragmented BLE client
  integration check passed. Phone rendering/reception and a physical golf strike
  have not been verified in this setup session.
- The deployed service restarted successfully with zero automatic restarts;
  both snapshot files update and the detector reaches waiting-for-ball state.

## Installation and rollback

The Pi boot camera configuration is v0.2.0, with both `dtoverlay=ov9281,cam0`
and `dtoverlay=ov9281`. The existing SSH connection is
`lm1@192.168.0.140`, using `~/.ssh/lm1_codex_ed25519` on the Windows host.

The normal Pi installer includes the updated camera modules and preserves
existing environment settings. To enable the verified profile on this already
provisioned Pi, copy the service folder and run:

```sh
sudo python3 scripts/setup-dual-camera-v1.0.0.py raspberry_pi
```

The setup script backs up the four changed service files, environment and boot
configuration under `/var/lib/pinpoint/backups/pre-dual-0.30.0-*` before replacing
service files. It sets `PINPOINT_DUAL_CAMERA=true`, primary index 0, secondary
index 1, requested 242 fps and 10-bit mode. It restarts the service.

To return to one camera, set `PINPOINT_DUAL_CAMERA=false` in
`/etc/default/pinpoint` and restart `pinpoint`. To roll back code, stop the
service, restore the four Python files and `pinpoint.env` from the printed
backup location, then start it. The second boot overlay can remain enabled.

The diagnostic scripts must run while the service is stopped, with a shell
trap to restart it on exit. Hardware test captures live separately from shot
history in `/home/lm1/dual-camera-0.30.0/`.

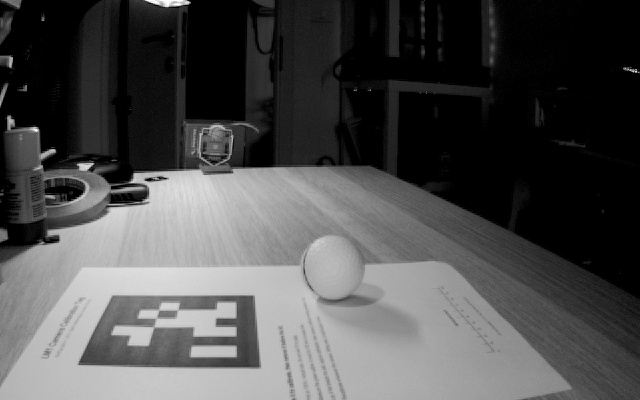
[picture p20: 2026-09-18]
tmp/apriltag/live-ball-final-setup.jpg

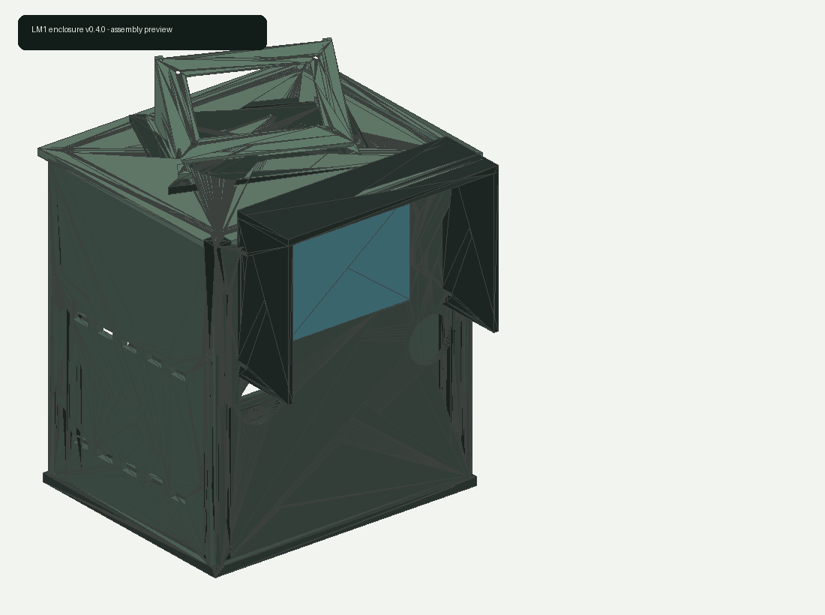
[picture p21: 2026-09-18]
hardware/enclosure/stl/v0.4.0/lm1_assembly_preview_v0.4.0.png

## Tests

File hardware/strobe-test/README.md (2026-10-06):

# LM1 strobe bench test

Firmware 0.3.0 drives two low-brightness addressable status pixels on GPIO 7:
breathing blue for `led searching`, steady white for `led ready`, and breathing
orange for `led processing`. Pi service 0.62.0 supplies actual ball/processing
state and restores it after reconnect. The breathing cycle is 2.2 seconds.
The original 0.2.0 blue test used the same pixels
(GRB, 800 kHz protocol). This does not identify the connected 12 V strip model;
blue output was visually confirmed by the user. Power comes from the strip's
specified supply, with common ground.

The current Pi connection uses a USB-to-UART adapter. Build with
`CDCOnBoot=default` (disabled) so commands use UART0. The old native-USB
configuration is only appropriate when connected through native USB.

Work in progress on the `strobin-effect` branch. Nothing here touches the Pi service.

| File | What it is |
|---|---|
| `strobe_smoketest/` | ESP32-S3 sketch, no serial needed. Idle, slow blinks, then 120 Hz bursts. First power-up check. |
| `strobe_test/` | ESP32-S3 sketch with serial commands for single bursts and uneven spacing. |
| `strobe_master/` | ESP32-S3 light controller: `mode off\|flat\|strobe [driver\|iron\|chip]`, `ping`, a 3 s watchdog back to steady light, plus the bench commands below. Boots in flat light. This is what the Pi service drives (`PINPOINT_LIGHT_CONTROL=esp32`). |
| `strobe_capture_test.py` | Pi script: compares camera frames with the light off and on, saves images. |

## Wiring (ESP32-S3)

| ESP32 | Goes to |
|---|---|
| GPIO 4 | ULN2003 IN1 to IN4 (joined) |
| GPIO 5 | Camera STROBE `+`, with a 1 to 4.7 kΩ pull-up to 3.3 V (optional) |
| GND | ULN2003 `−`, camera STROBE `−`, 12 V supply `−` |

The camera TRIG input is **not used**. The camera free-runs and the ESP32 flashes
on its own clock. `strobe_master` has a TRIG output on GPIO 6 that is off by default.

## How the free-running setup works

- Camera: 640×400 at 242 fps, exposure about 4000 µs (nearly the whole 4132 µs frame),
  so a burst from the ESP32 almost always lands inside an exposure.
- ESP32 default ("driver" preset): 5 flashes of 15 µs with gaps of 0.7, 0.8, 0.9 and
  1.0 ms, repeated 242 times a second. At 80 m/s a 15 µs flash blurs the ball by 1.2 mm.
  The copies of a 60 to 85 m/s ball do not overlap, and the uneven gaps tell you which
  copy came from which flash.
- The two clocks drift slightly, so some bursts straddle the gap between exposures and
  lose a flash or two. The shot is still there.
- `preset iron` is the same idea for about 40 to 60 m/s.

## Flash the ESP32

```
arduino-cli compile --fqbn esp32:esp32:esp32s3:CDCOnBoot=default strobe_master
arduino-cli upload -p COM5 --fqbn esp32:esp32:esp32s3 strobe_master
```

Open a serial monitor at 115200. It starts flashing on its own. Useful commands:

```
show              current settings
preset driver     60-85 m/s (the boot default);  preset iron for 40-60 m/s
rate 242          bursts per second, match the camera's real frame rate
f 4 1000          4 flashes 1 ms apart
i 700 800 900     uneven spacing (4 flashes)
p 15              15 us flashes
light off / on    flashes off or on
stop / go         stop or resume
strobe on         print the camera STROBE statistics
```

## Test with the camera (on the Pi, dark room)

```
sudo systemctl stop pinpoint
python3 strobe_capture_test.py --serial /dev/ttyACM0
sudo systemctl start pinpoint
```

It sets the ESP32 to the driver preset and the camera's real frame rate, prints the
mean brightness with the light off and on, and says PASS when the flashes are visible. Then wave a small ball through the view and open
`strobe_test_out/on_*.png` to look for separate copies.

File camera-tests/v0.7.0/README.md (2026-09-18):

# Stationary ball stability v0.7.0

The live Pi logs showed that the ball was detected repeatedly, but the detector alternated between detected and removed while the ball remained visible. The 200 fps image also showed strong horizontal bands from the indoor lighting.

Service 0.7.0 samples CSI detection every fourth frame (about 50 samples per second at 200 fps) instead of every twentieth frame. It also keeps the last confirmed ball bounds during a brief missed-contour debounce period so the app does not drop the box immediately. BLE preview cadence remains three seconds.

App 2.5.0/build 15, Pi service 0.7.0, BLE protocol 2.5.0.

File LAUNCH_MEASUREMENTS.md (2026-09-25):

# Update: App 3.8.2 / Pi 0.26.0 — stored ground pose

Explicit ground calibration now permits tag removal. Reset empty plane requires recalibration with the tag. See raspberry_pi/README.md for the current flow.

# AprilTag launch measurements — app 3.16.0 / Pi 0.36.0

This release implements monocular and calibrated stereo measurement paths. Values derived from camera geometry are **estimates** until checked against a reference launch monitor. Missing evidence produces an unavailable value with a reason.

Current 3.16.0 behavior: three geometrically matched stereo frames spanning at
least 8 ms can provide a speed **estimate**; six are required for measured-grade
status. A camera capture becomes an app shot only when its speed, launch, and
direction come from camera measurements. If tracking fails, these values stay
unavailable, no club-profile ball speed is substituted, and nothing is sent to
the simulator. The app reports matched frame indices and failed quality checks.
The Pi's numeric `confidence` is an uncalibrated quality score, not a percentage
chance of correct tracking or speed accuracy, so it is not shown as a percentage
for camera shots.

Valid stereo fits are preferred over a successful single-camera fit. Stereo
geometry failures stay visible and force the remaining single-camera result to
estimated status. The app names the actual measurement source. Since 3.35.0 a
measured ball without a resolved club track is still a shot, with club values
unavailable; only movement classified `not-a-strike` (under 2 m/s, over 60° off
line, or a roll with no club) is excluded. This is evidence
of a swing near departure, not direct proof of face contact. Ground recalibration
invalidates a saved target line, since it may rotate the coordinate system.

## Pipeline and metrics

Sensor-timestamped grayscale burst → resting-ball position and camera poses → primary trajectory and ball-outline analysis. When that fit fails, each calibrated camera detects ball-sized circles independently. Candidates are paired by ray geometry, apparent size and a coherent 3D path; a joint fit recovers speed, launch and direction without using apparent ball size for depth. Stereo needs both lens calibrations and saved ground-tag poses from the same fixed tag placement. Three paired frames spanning at least 8 ms are eligible for measured-grade status when every timing, geometry, calibration, and fit-quality gate passes. Pair offsets must be ≤250 μs, median ray gap ≤3 mm, resting-height error ≤5 mm, start-anchor error ≤30 mm, and reprojection residual ≤3 px. Failure of a required geometry gate leaves metrics unavailable; failing a stricter grading gate leaves them estimated. Ground-tag pose error above 3 px is rejected. The sampled presence detector supplies only `coarseDepartureFrameIndex`; the last stationary and first coherent moving observations bound contact.

| Metric | Implemented method | Required evidence |
| --- | --- | --- |
| Ball speed | Fit velocity through monocular sphere centers or at least three paired stereo centers; three clean pairs can receive measured-grade status | Resolved ball positions and valid sensor timestamps |
| Launch / start direction | Vertical/horizontal angles of the fitted 3D velocity; start direction is measured against the calibrated target line (`/var/lib/pinpoint/target-line.json`, set from a ball rolled toward the target), not the tag's orientation | Ground tag lying flat; a target line for start direction (speed and launch angle do not need one) |
| Club / putter speed | AprilTag pose transformed to calibrated face center, then velocity regression | ≥3 pre-impact club-tag observations and correct club-specific rigid transform |
| Smash | Ball speed / club speed | Both accepted speeds |
| Strike toe/high | Ball relative to extrapolated face axes near departure; contact-plane proximity check | Face geometry, stationary ball observation, club pose within 10 ms |
| Backspin / spin axis | Optical-flow surface marks → ray/sphere intersection → rigid surface rotation | ≥3 nondegenerate marks, forward/backward flow agreement, ≥2 consistent pairs and <60° rotation per pair |
| Carry, total, apex, landing angle, offline | Still-air drag/lift model fitted to Trackman PGA Tour averages (carry within 1-7% driver to wedge), then a slide-to-roll turf model for roll | Accepted speed, launch and direction; spin from camera, else estimated from club speed and attack angle, else the club average. Excludes wind, terrain, curvature |
| Dynamic loft, spin loft | Rolling-contact impact model: launch minus attack angle fixes spin loft | Measured launch and attack angle; unavailable when launch exceeds attack by more than 40° |
| Putting roll distance | Straight-line placement-to-stop displacement on ground | Continuous ball visibility, ground-height consistency, ≥100 ms observed stop |
| Skid distance | Displacement until three consecutive low-slip translation/rotation pairs | Ground track and simultaneous resolved surface rotation |

Partial values appear automatically in the capture card on Monitor, Putting and Sessions. The Pi's legacy shot/putt message still requires all seven core values (speed, club speed, smash, launch, direction, strike X/Y). The app creates a camera shot only when camera-derived speed, launch and direction are all available; missing ball speed remains a failed capture, never a club-profile shot. Optional spin/carry/roll/skid fields are included only when available. `measurementSource` identifies camera estimates. Ball size in the trajectory fit comes from a sub-pixel edge fit (`ball_edge_fit`), and its comparison with the standard ball is a grading check.

Each reported value is graded by `grade_metrics`: `measured` means every applicable device quality gate passed, not that accuracy was validated against a reference launch monitor. Stereo checks include both pose errors, reprojection residual, ray gap, resting height, start anchor, pair timing, paired-frame count, and fit uncertainty. Anything else is `estimated`, with a `checks` list naming failed gates. The legacy `confidence` field multiplies gate penalties; it is an uncalibrated quality score, not the probability that the ball was tracked or that speed is accurate. The app shows Measured/Estimated labels and individual checks, not that percentage, on camera shots. Carry, face contact, roll/skid, and tag-free club values remain estimates.

## Physical setup needed

1. Keep the existing OV9281 rigidly mounted and focused. Use its **actual sensor timestamps**, fixed short exposure and enough light. The software rejects exposure above 250 µs and rejects estimated blur above 4 mm; at a hypothetical 70 m/s, 4 mm requires exposure below about 57 µs. This is a calculation, not a lighting specification.
2. Calibrate intrinsics/distortion for both cameras at exactly the capture resolution, sensor crop and lens focus. The ground AprilTag alone cannot determine lens parameters.
3. Print the supplied ID 0 ground tag at 100 mm black outer-edge size. Keep it fixed, flat, visible to both cameras and outside the swing path/detection region. Its decoded top edge points downrange. After lens calibration, use **Capture AprilTag calibration** with both cameras seeing the same tag; verify that both camera poses are saved. The shared tag frame establishes their relative geometry. Then you may remove it while both cameras and the surface remain fixed. Empty-plane reset invalidates saved poses and target line.
4. Attach a different tag (supplied ID 1, 20 mm) rigidly to the club where the camera can see it before contact. It must not interfere with the face or change position relative to the head. Size is a starting template, not a guarantee it will resolve at your speed/distance. Measure its transform for each club; do not reuse a driver's transform for an iron.
5. Use a ball with distinct, nonrepeating visible surface marks for spin. A plain silhouette cannot reveal rotation. The pipeline assumes radius 21.335 mm; actual ball size/deformation and image threshold bias affect depth.
6. For complete putting distance, keep the ball visible until stopped. The current burst tracker examines up to 256 post-departure frames. Longer putts outside that field/time window will correctly remain unavailable.

**Recommended next hardware step:** a second externally synchronized global-shutter camera for more reliable depth and occlusion coverage. An independently timestamped impact sensor would help reject hand-lift events. A ground tag plus a single image cannot guarantee exact club contact. Do not purchase a specific camera solely from this document; choose a supported synchronized pair after checking the required frame rate, exposure and field of view with your fastest shot.

## Lens calibration

Collect at least 12 images of a checkerboard with diverse tilts and positions covering the image, at the exact capture mode and fixed focus. The dimensions below count INNER corners. Measure the square size; replace the example values with the actual board.

```text
python scripts/calibrate-lens.py calibration-images --columns 9 --rows 6 --square-mm 20 --output intrinsics.json
```

Copy the accepted file to `/var/lib/pinpoint/intrinsics.json`, or set `PINPOINT_INTRINSICS_PATH`. The script rejects reprojection RMS above 0.7 pixels; low RMS alone does not establish absolute accuracy. Verify known distances across the hitting volume, not only on the tag plane. Changing focus, crop, sensor mode or resolution requires recalibration.

## Club calibration file

Create `/var/lib/pinpoint/club-marker.json` (or `PINPOINT_CLUB_MARKER_PATH`). This example is a **schema illustration, not usable measured geometry**:

```json
{
  "clubId": "driver",
  "tagId": 1,
  "tagSizeMm": 20,
  "faceCenterM": [0.01, -0.01, -0.03],
  "faceAxes": [[1, 0, 0], [0, 1, 0], [0, 0, 1]]
}
```

Replace the position and axes with measurements for the actual mounting. Position is face center in tag-local metres; columns of `faceAxes` are unit toe, high and outward-normal vectors expressed in tag coordinates. The basis must be orthonormal and right handed. Match `clubId` to the selected app club (`putter` in putting mode). Unsupported or mismatched geometry blocks club and strike values.

## Target line

Start direction is measured against a target line. By default this now comes from the **camera's own across-image axis**, projected onto the ground from the calibrated pose: with the monitor squared to the target, the ball's line is whatever runs left to right across the image, so no calibration step is needed. This is taken from the camera pose rather than the tag, so it is unaffected by how the ground tag happens to be rotated. `diagnostics.calibration.targetHeadingSource` reports `camera-axis` when this is used.

Rolling a ball and using **Set target line** still saves an explicit heading, and an explicit line takes precedence (`targetHeadingSource: rolled-ball`). Clearing it returns to the camera axis rather than making start direction unavailable. The only case with no target line at all is a camera rolled towards portrait, where the across-image axis has no ground direction; level the monitor or save an explicit line.

## Tag-free club measurement

**Two cameras (preferred, 0.47.0).** The clubhead is dark against the mat, but the lit shaft and hosel highlight form a "check" whose lowest point, the hosel, is one physical point in both views. It is triangulated per frame (rays must meet within 10 mm), the longest run that one smooth path explains within 10 mm is kept, and its velocity at the last frame before impact gives `clubSpeedMps`, `attackAngleDeg` and `clubPathDeg`. Three frames are the minimum; five or more add a constant-acceleration term for the swing arc. The hosel moves slightly slower than the face centre. The single-camera swing-plane method below remains the fallback when the pair is not calibrated or the stereo track fails; on real chips it read about 20% low.

**Single camera (fallback).**

When no `club-marker.json` exists, the analysis falls back to tracking the clubhead silhouette. A monocular view cannot scale an unknown shape, so this path borrows scale from geometry that is already known: the head is back-projected onto a vertical swing plane pinned to the ball's position at contact, using the ball's own outgoing direction for the plane. It yields `clubSpeedMps`, `smashFactor` and `attackAngleDeg` as **estimates**, each naming its assumption.

`clubPathDeg` is deliberately **not** produced by this path. The swing plane is constructed from the ball's horizontal direction, so a club heading read off that plane equals the ball's start direction exactly, by construction. It would look like an independent measurement while restating one that already exists. Horizontal club direction needs depth the silhouette cannot supply, so it stays unavailable until a club tag or a second camera is present. Attack angle survives the same objection because the plane is vertical and does not constrain vertical motion.

This requires the camera to look **across** the swing, not along it. A camera whose rays lie inside the swing plane cannot resolve clubhead depth at all; that geometry is refused with a message rather than answered, and no amount of lighting fixes it.

Face contact needs one more number that a silhouette cannot supply: how wide the clubhead actually is. Since app 3.38.0 enter it per named club in the app ("My clubs"); the Pi writes it to `/var/lib/pinpoint/club-profile.json` (or `PINPOINT_CLUB_PROFILE_PATH`) when that club is selected. A hand-made file in the format below is still honoured and never overwritten. No tag and no mounting are involved:

```json
{
  "version": 1,
  "clubId": "sand-wedge",
  "faceWidthMm": 82,
  "faceHeightMm": 48
}
```

`faceWidthMm` is the heel-toe width, `faceHeightMm` the sole-to-crown face height. With the profile present, `strikeXmm`/`strikeYmm` are derived in the contact frame using the ball's known 42.67 mm diameter as the local scale reference, since ball and contact patch sit at the same depth. The measured face span is cross-checked against the profile, so a profile for the wrong club is rejected rather than applied. Without the profile both stay unavailable with a reason; they are never filled from a club profile.

Accuracy of the tag-free path has not been established against any reference. Attack angle is the most sensitive to the swing-plane assumption and should be the last value trusted.

Print-ready SVGs are in `output/measurement-targets-3.4.0`. Regenerate with `python scripts/create-measurement-targets.py`. Measure the black outer square and 100 mm ruler after printing.

## Install and acceptance

Run the existing Pi installer; it also installs `launch_measurements.py`. Keep automatic detection enabled. Deploy app 3.8.0/build 39, configure lens/club files and fixed exposure, then restart the service.

First validate slow motion at known distances. Then test actual strikes against an independent launch monitor and impact tape. Check image overlays, missed detections, false ball identity, ball-depth bias, club-pose ambiguity and spin aliasing. Test each club separately. Reject unsupported metrics rather than adjusting constants until they look plausible.

Known remaining engineering risks: analysis/JPEG saving still pause the acquisition worker; long occlusion can overwrite the trigger interval; brightness-based silhouettes can merge with the background; single-tag planar pose can be ambiguous; surface-flow rotation can alias or follow wrong marks; face extrapolation is not exact compression-time contact; full ball roll often exceeds the current capture window. The spin and roll/skid algorithms need real marked-ball footage before accuracy claims. A second-camera acquisition/synchronization pipeline is **not** implemented in this release.

## Evidence and references

Tests exercise off-axis sphere geometry, tag-pose round trips, known nonuniform-time velocity, surface rotation, sensor metadata, calibration rejection, a rendered moving-ball burst, core-result delivery and mismatched-club rejection. These are algorithm/software checks, not real-shot validation.

Verification for 3.4.0: 69 Python tests passed, including club speed/contact geometry and observed stop/skid fixtures. Fragmented-BLE client and OpenGolfSim bridge integration tests passed. TypeScript, ESLint and production web export passed. No real Pi/camera deployment, native-screen visual verification or real golf strike was performed.

Primary documentation: [OpenCV calibration and 3D reconstruction](https://docs.opencv.org/4.x/d9/d0c/group__calib3d.html) and [Picamera2 sensor metadata](https://datasheets.raspberrypi.com/camera/picamera2-manual.pdf). [Raspberry Pi camera documentation](https://www.raspberrypi.com/documentation/accessories/camera.html) explains short-exposure global-shutter capture and its lighting requirement.

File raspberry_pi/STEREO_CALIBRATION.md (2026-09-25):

# Fixed-pair calibration — workflow version 1.0.0

Available in app 3.17.0 / Pi 0.37.0 / protocol 2.24.0.

## App workflow

1. Keep both cameras rigidly attached; lock lens focus. Calibrate each lens at the
   actual capture resolution first. Stereo calibration does not alter lens files.
2. Open **Calibration → Calibrate both cameras as a fixed pair**.
3. Enter checkerboard INNER-corner columns and rows and measured square size.
   Defaults match the existing 5×5 inner-corner, 25 mm board. Mount it flat on a
   rigid backing. A square size error creates a scale error even with good fit.
4. Start a new set. Existing sessions and active calibration are retained.
5. Hold the entire board still and clearly visible in both previews. Capture at
   least 16 distinct pairs, ideally 20–28, distributed left/right, high/low and
   near/far, with forward/back and sideways tilts. Move only the board, never the
   cameras. The previews are live, not evidence that a capture succeeded.
6. Press **Capture synchronized pair** at each pose. Images come from the same
   dual-camera read, with actual sensor timestamps, not the phone previews.
   Both board detections must succeed; missing timestamps, more than 250 µs skew,
   near-edge corners and near-duplicate poses are rejected. Accepted PNG pairs,
   corners, timestamps, camera order and lens inputs stay on the Pi.
7. Press **Solve camera pair**. Every fourth accepted pair is held out. At least
   12 training and 4 validation views are required. Training must cover multiple
   positions and tilts. Intrinsics remain fixed during OpenCV stereoCalibrate.
   Symmetric board corner rotations are aligned by transform consistency across
   training views; validation ordering is compared against the frozen transform.
8. Review separation and errors. Initial engineering gates: training RMS ≤0.7 px,
   held-out prediction RMS ≤1.0 px, worst held-out view ≤2.0 px, separation
   10–1000 mm. These are quality gates, NOT a guarantee of millimetre accuracy.
   Failed candidates remain visible but cannot be activated. Capture more varied,
   sharp views, or start a new set if existing views are poor.
   The app also shows a 0–100 fit score. A score of 100 means training RMS ≤0.35 px,
   held-out RMS ≤0.50 px, and worst held-out view ≤1.00 px. It summarizes margin
   inside the validation limits; it is not a physical accuracy measurement.
9. **Use this calibration** explicitly activates a passed candidate. The previous
   active file is backed up. Existing lens, ground and shot-history files are not
   rewritten. Verify the reported separation against the physical mount.
10. Remove the board before closing the screen. Shot detection is paused while
    the screen is open, and its empty-scene model resets on exit. If the phone
    disconnects, the pause expires after 120 seconds without a refresh.
11. Capture/check the bottom-camera ground AprilTag after moving the rig. Future
    shots use the bottom ground pose plus the fixed pair transform for the top
    camera. Left-to-right camera-relative zero direction is unchanged. Validate
    known stationary ball positions/heights before trusting launch estimates.

## Storage and safety

Default root: `/var/lib/pinpoint/stereo` (`PINPOINT_STEREO_PATH` override).
`sessions/<uuid>/session.json` stores board, lens inputs, accepted paired corners
and timing; matching PNGs are adjacent. `candidate.json` is a staged result.
`current.json` points to the current resumable session. `active.json` is the
atomic active selection; previous selections are under `backups/`.

The fixed transform uses `X_secondary = R_pair X_primary + t_pair`. Therefore
`R_secondary_world = R_pair R_primary_world` and
`t_secondary_world = R_pair t_primary_world + t_pair`.

If no fixed calibration exists, legacy independent ground poses still work.
If an active calibration exists but lens parameters, image size or configured
camera indices differ, stereo fails explicitly; stale geometry is not used.
Changing physical focus/mount position cannot be detected reliably by a file
fingerprint: recalibrate after either changes. New capture manifests include the
active stereo snapshot for diagnosis. Old captures are not reprocessed.

## Offline script

Use the same solver on an existing paired session (OpenCV and NumPy required):

```sh
python stereo_calibration.py --session /path/to/session.json --output /path/to/candidate.json
```

The command writes a candidate only; it never activates it or captures from a
second competing camera handle. Use a new output path to preserve older reports.

BLE command: `stereoCalibration`, actions `status`, `start`, `capture`, `solve`,
`activate`, `end`. Start accepts `columns`, `rows`, `squareMm`; activate requires
the exact staged `candidateId`. Capture replies only after the camera callback
has saved or rejected the paired images. A compact status is returned for each
action. The app polls status every 30 seconds while idle to keep the pause alive.

Reference: [OpenCV stereo calibration](https://docs.opencv.org/4.13.0/d9/d0c/group__calib3d.html),
using `CALIB_FIX_INTRINSIC` and independent held-out cross-camera reprojection.

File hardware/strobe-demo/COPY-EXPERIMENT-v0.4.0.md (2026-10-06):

# Three-copy experiment 0.4.0

Run `demo.py --copies` using the existing Pi environment. Current deployed folder is `/home/lm1/strobe-demo-v0.4.0`, browser port 3113. Stop the existing camera owner first. The temporary service uses automatic restart; stop it explicitly before returning to normal operation.

The camera runs at 50 fps with requested exposure 19500 us and gain 1. The ring emits 100 us pulses at offsets 0, 5000, 13000 us in each 20000 us cycle. Cyclic gaps are 5000, 8000, 7000 us, at 1.5% electrical duty. No peak-current increase or hardware modification is made.

Distance is speed times elapsed time. At 10 m/s the consecutive spacings are 50, 80, 70 mm, while a pulse contributes 1 mm of movement. At 14 m/s these become 70, 112, 98 mm and 1.4 mm pulse blur. For a 42.67 mm ball, the shortest gap separates complete copies above about 8.53 m/s. Slower shots may overlap. Perspective and ambient contribution remain unresolved.

Each image is analyzed independently for at least three distinct ball copies. All cyclic flash phases are fitted; ambiguous phase or poor fit prevents a result. Camera exposure boundaries can clip or omit pulses, since there is no hardware synchronization. Raw images, commanded pattern, sensor metadata and failed attempts are preserved.

The off/on bench used the initial 5/6.5/8.5 ms gaps and 100/250/500 us pulse widths, with actual 19497 us exposure. Minimum gain did not make the room dark: the lower placement ROI had 4.45% clipping, upper 0.67%. ROI statistics are not isolated ball photometry. Saturation prevents concluding that a weak measured difference means the ring itself is weak. The raw bench is in `output/strobe-demo-v0.4.0/bench/`; moving shots are required to inspect whether separate flash copies survive ambient trails.

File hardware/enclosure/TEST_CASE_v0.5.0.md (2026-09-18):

# LM1 camera test case — v0.5.0

A three-piece open prototype for Pi 5 and camera setup. Print one tray, one
mast, and one camera bracket. No display or LED modules are required.

The footprint is 140 x 130 mm; assembled height is 184 mm. The nominal camera
board centre is 150 mm high with a 13-degree downward pitch. Actual lens-centre
height depends on lens projection and module construction. Add foot thickness
to all height measurements. Check framing before calibration.

## Assembly

1. Bolt the mast foot onto the tray with four M3 x 10 mm screws, nuts and washers.
   Screw heads enter the recessed underside holes. A shim/washer may be needed
   depending on the screw-head profile.
2. Bolt the camera bracket to the rear of the mast at its four matching holes
   with M3 x 12 mm screws and nuts. Lens looks through the open frame toward the
   short front edge of the tray. Both sides of these screws remain accessible.
3. Mount Pi 5 on the four tray bosses using M2.5 x 16 mm through-bolts and nuts.
   Holes are 2.8 mm clearance diameter. Add feet at least 4 mm thick to clear
   the underside nuts, or mount on a board with clearance pockets. Do not force
   the PCB down. Board outline is 85 x 56 mm and hole spacing is 58 x 49 mm.
4. Mount the camera with insulating spacers so solder joints cannot touch the
   bracket. Its diagonal slots span square hole patterns from 24 to 34 mm.
   Exact OV9281 module dimensions still need confirming. A USB webcam needs its
   own adapter; this bracket is intended for the planned board camera.
5. Route a sufficiently long CSI cable down through the open mast, with slack
   and no tight folds. All Pi ports and the active cooler remain accessible.

## Printing and use

STLs are millimetres and already oriented: tray flat, mast and bracket with
their broad faces parallel to the bed. They may need local supports under overhangs; inspect
the slicer preview. Use 0.2 mm layers, four walls and 20–25% infill. The longest
part is 180 mm. Test a fastener hole before committing to all parts.

This open stand is for dry bench/framing tests. It does not shield the electronics
from a golf-ball strike or rain. Secure it to a board or add ballast through the
tray slots before swing capture, and use a separate protective barrier outside
the camera view. There is no protective window included in this simple revision.

`assembly_reference` is for viewing, not a print job. Print the three named
parts separately. The green Pi and grey cooler in the preview are placeholders.

## Regeneration

Keep the included `lm1_case_v0_2_0.py` beside `lm1_test_v0_5_0.py`; it supplies
shared mesh primitives and the camera bracket. Install numpy, trimesh,
manifold3d and Pillow, then run `python lm1_test_v0_5_0.py`.

Mesh checks cover closed surfaces, positive volume and a single connected
solid for each exported printable STL. No physical print or hardware fit test
has been performed.

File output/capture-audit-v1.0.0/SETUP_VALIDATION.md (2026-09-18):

# LM1 setup validation v1.0.0

15 September 2026. Pi service 0.23.4; diagnostic audit tool 1.0.0.

## What the saved footage establishes

The latest capture, `capture-1789478965522399703`, contains 325 sensor-timestamped frames over 1.341 seconds. The measured rate is 241.57 fps, with a maximum interval of 4.144 ms and no gaps suggesting dropped frames. Image tracking follows eight outgoing frames, 177–184.

The Pi replay detects the floor tag and estimates the camera height above the tag plane at 215.2 mm and downward pitch at 13.04 degrees. The user measured the lens centre at 215 mm above the ground and reports a 2 mm raised surface. These measurements broadly agree; they do not by themselves prove the entire lens and ground calibration accurate. The print ruler checked correctly; keep the printed black square at 100 mm.

The strict ball-outline path accepts no frames. The partial-outline path considers five motion matches with sufficient tracking score, finds one candidate at frame 178, and rejects it because its calculated centre is 28.7 mm below the tag plane. Frames 182–184 are visible in the image track but do not pass the fallback's tracking-score threshold. The failure is therefore not a shortage of captured images.

The same patch inside the resting ball varies from 160.6 to 196.7 on the 0–255 brightness scale across the first 100 frames (maximum/minimum 1.225). An earlier capture varies by 1.287. Exposure is fixed at 143 microseconds and gain is 4.0. This variation is consistent with unsteady illumination. The difference-mask images show how the shaded ball edge disappears and the club/ball regions merge.

An experimental edge fit finds additional outline pixels but its frame-to-frame depth is unstable. It is not enabled in live measurements. More reported numbers would not establish more accurate measurements.

## Physical observation limit

The latest framing has approximately 0.222 m of ground-level travel to the right from the hitting position before the ball approaches the edge. This estimate assumes ground-level left-to-right travel and the current apparent radius; flight direction, lens errors and club occlusion reduce its usefulness.

At 50 m/s and 241.57 fps, the ball travels 0.207 m between frames. Three outgoing samples require at least two frame intervals, or approximately 0.414 m at that speed, plus margin for exposure phase and club overlap. Increasing post-trigger retention cannot recover observations outside the camera view. This framing is suitable for investigating slow shots; it cannot reliably provide three full-ball observations of a 50 m/s shot.

## Next controlled tests

1. Keep the camera, tag and focus fixed for the next test. Put the ball in the same hitting position and gently roll it left-to-right without a club next to it. Confirm the monitor is armed first. This isolates ball-outline extraction from club overlap. Do not infer airborne launch or spin from a ground-only model.
2. Repeat that roll with steadier, more even illumination on both the top and lower ball edge. Keep exposure and gain fixed so the comparison is meaningful. Compare the stationary brightness variation, accepted outline count, consecutive run length and ground/depth rejections in the saved diagnostics.
3. Fit the 28-degree bracket and inspect the framing. Keep the full ball inside the frame, with clear space below and along its outgoing path. Reset the empty-scene background and refresh ground/target-line calibration. Lens calibration needs repeating if focus or sensor mode changes; rotating the whole camera alone does not change its intrinsic lens parameters.
4. Validate a stationary ball and several slow rolls at left, centre and right positions. A resting ball centre should be about 21.3 mm above its supporting surface (about 19.3 mm above a tag plane raised 2 mm relative to that surface). Consistent position-dependent height errors indicate calibration/outline bias before any velocity calculation.
5. After clean rolls produce a stable sequence, repeat slow club strikes. Seek at least six to eight usable outgoing observations as an engineering test target; the software's three-frame minimum is only a minimum fit condition. Compare against an independent speed reference or a separately timed measured path before calling the speed accurate.
6. For faster shots, measure the required visible travel using `speed * frame intervals / actual fps`. Increase field coverage and/or actual sensor rate while keeping the ball large enough for outline measurement. Additional camera viewpoints can help club overlap and depth, but require synchronization and calibration work.

Core goal: dependable ball speed and launch/start direction first. Club speed and face strike require a calibrated club reference; reliable spin requires resolved surface features. Neither is solved by the current outline diagnostics.

## Files and repeatability

- `latest/audit-on-pi-v1.0.0.json`: replay on the Pi's OpenCV 4.10.0 runtime.
- `latest/audit-v1.0.0.json`: local OpenCV 5.0.0 replay. Small tag-pose differences across versions are recorded explicitly.
- `latest/outline-audit-v1.0.0.jpg`: camera frames beside the actual difference-mask algorithm output.
- `previous/audit-v1.0.0.json`: preceding capture comparison.
- `scripts/audit-capture.py`: repeatable read-only replay with explicitly supplied lens calibration.

Future service 0.23.4 captures save calibration matrices, tag size, inferred camera height/pitch, strict-outline counts and per-frame partial-outline rejection reasons in `analysis.json`. Detailed diagnostics stay off BLE; the shorter failure explanation reaches the app.

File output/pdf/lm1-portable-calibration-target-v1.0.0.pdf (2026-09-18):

# LM1 PORTABLE CALIBRATION TARGET

v1.0.0 - 6 x 6 checkerboard - 25 mm squares

0 | 50 | 100

mm - verify this is 100 mm
Print at 100% / Actual size. Do not use Fit to page.

Place the board flat beside the ball with its top edge parallel to the target line.
Keep the complete board visible during calibration; re-calibrate whenever LM1 is moved.

For durable use, mount the print on a rigid, matte backing.

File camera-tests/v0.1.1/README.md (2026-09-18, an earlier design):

# Camera test v0.1.1

OV9281 on Raspberry Pi 5 CAM0. Full sensor resolution 1280x800, 10-bit mode, requested 30 fps.

Successfully captured a visible room image with 30000 us exposure and gain 4, but it was overexposed. Captured a second image after four seconds of automatic exposure.

These are standalone rpicam tests; the LM1 BLE service camera backend has not been changed.

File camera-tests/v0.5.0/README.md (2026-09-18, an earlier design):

# LM1 CSI integration verification v0.5.0

Tested 2026-09-07 on the existing LM1 Pi: `lm1@192.168.0.140` (`raspberrypi.local`). SSH uses the existing `~/.ssh/lm1_codex_ed25519` key on the Windows host. Camera: OV9281 on CAM0.

- Pi service 0.5.0 / BLE protocol 2.3.0 deployed and enabled; zero automatic restarts at verification.
- App 2.3.0 / build 13; TypeScript, lint, iOS bundle and simulator bridge check passed.
- All 29 Python tests passed on the Pi, including OpenCV tests.
- Picamera2 captured 1280x800 at a sensor-reported 30 fps. Automatic exposure settled around 10 ms at gain 1.
- Service produced a 1275-byte BLE JPEG and live diagnostics including focus score 50.8 in the current room scene. This is a relative score, not a focus calibration.
- `/var/lib/pinpoint/camera-latest.jpg` updates about every three seconds from the service-owned stream. `focus-latest.jpg` here is a saved snapshot, not a live feed.
- Autofocus control is unavailable. Optical focus is adjusted at the lens with a target at ball distance.
- Automatic ball detection is disabled during focus setup; shot metrics remain synthetic.
- The Windows BLE scan did not find LM1. Phone-side preview reception remains unverified.

Boot configuration backup: `/boot/firmware/config.txt.pre-lm1-camera-v0.1.0`.
Previous service Python files and environment/systemd configuration: `/var/lib/pinpoint/pre-csi-0.5.0` (root only).
Deployment sources: `/home/lm1/lm1-csi-0.5.0`.
Phone development server: `http://192.168.0.199:8081`.

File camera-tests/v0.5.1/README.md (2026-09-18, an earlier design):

# Camera lighting configuration v0.5.1

2026-09-07: switched the running CSI service to 90 fps at 1280x800 with automatic exposure. App remains 2.3.0 and service remains 0.5.0; this is a camera configuration change.

First preview sensor metadata: 90.1 fps, 4427 us exposure, gain 1.0. Service active with zero automatic restarts. Fresh full-resolution snapshot saved as 90fps.jpg; the scene is visible with dark background areas. Camera position differs from the earlier 30 fps snapshot, so these images are not a controlled brightness comparison.

Left 90 fps active for phone preview. Previous environment backed up on the Pi at /var/lib/pinpoint/pre-90fps-v0.5.1.env. BLE preview still refreshes every three seconds. User confirmed phone preview reception before this test.

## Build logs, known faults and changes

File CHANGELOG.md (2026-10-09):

# Changelog

## App 3.45.0 / Pi service 0.63.0 - 2026-10-09

- Shutter speed is limited only by the camera. The Pi reads the sensor's exposure range from libcamera when the cameras open, capped at one frame period (about 4132 us at 242 fps), and accepts any whole microsecond in it in every light mode. The old software caps (20-250 us normally, 4000 us in strobe) are gone from the manual setting.
- The automatic sweep (Auto light and Auto-set) still chooses only measurement-safe shutters, and the launch measurement still rejects frames above 250 us (motion blur). The app says so when a longer shutter is set.
- A shutter set by hand while the light is on Auto switches the light to the mode in use (Flat or Daylight), so the next automatic sweep cannot overwrite it.
- The app shows the shutter the sensor actually runs (it rounds to whole lines, e.g. 3900 -> 3891 us), offers presets from 10 us to 4000 us, and accepts up to six digits.
- Also in this release (Pi, 2026-10-08): `install.sh` installs `adaptive_capture.py`; raw 10-bit capture switched off in `/etc/default/pinpoint` (it used about a third of the CPU and is only useful for strobe in a dark room).

## App 3.44.1 - 2026-10-08

- Package the latest app changes for TestFlight with the new LM1 app icon and splash artwork.
- New font: Space Grotesk for text, Space Mono for telemetry labels.
- New look: black mission-control theme. Bottom menu is now Play (Swing or Putting, chosen with a switch above the menu), Calibrate, Sessions, Device, Cloud.
- Bump the app release version; production iOS build numbering is incremented by EAS.

## Pi service 0.62.4 - 2026-10-06

- Strobe now measures slow shots (wedges, short irons). Their flash pattern has one wide gap (1970 us for a 30 m/s ball) so only two flashes fit in a frame, and the copy search needed three in one frame, so it never ran. A new pair fit takes the two copies from each frame and fits all frames together: the same flash repeats every flash period, and the second copy of a frame is either the burst's own flash (one gap later) or the next burst's first (period minus gap later). Both timings are fitted; the straighter line wins, a near tie is ambiguous and not reported.
- A pair result needs at least two frames with exactly two separate copies on one straight line, a speed within 0.6-1.6 times the club's expected speed, a residual under 3 mm and a plausible launch angle. Patterns with three or more flashes use the existing single-frame fit unchanged. A pattern with a single flash per frame is still not measured.
- Replaying the real 22:42 wedge capture (8-bit frames, ball smeared by room light) gives no result: only two frames held two separate blobs and one of them was the club. The fit refuses it, so a pair result needs a dark enough room that the copies come out separate; it has only been verified on synthetic frames so far.
- New messages for a slow pattern: too few frames with a pair (with the count), and the 2-flash case is no longer reported as too short.

## Pi service 0.62.3 - 2026-10-06

- Cut the CPU cost of strobing in the dark. Profiling the idle service with py-spy showed about 28 % of its time in the raw-10-bit-to-8-bit conversion that runs on every frame of both cameras (a float32 subtract, divide, add, clip and cast). It is now two OpenCV passes (a saturating 16-bit subtract, then a scaled saturating narrow) and takes about 0.06 ms per frame instead of 0.9 ms on a PC, with output identical to the old formula for every 16-bit word; other black levels or scales still use the old arithmetic. The Pi was reaching 83 C and throttling, which dropped frames to 80-120 fps.
- A strobe shot whose club pattern fits fewer than 3 flashes per frame (a wedge's single 1970 us gap) is now explained as that, not as the ring not flashing: copies for slow balls need wide gaps and a frame is only about 4 ms long.
- Tests compare the fast conversion with the formula over every 16-bit word.

## Pi service 0.62.2 - 2026-10-06

- Fix a stuck white status LED with no ball detected. In strobe mode the analysis source flipped between the raw 10-bit and 8-bit pictures several times in a few seconds (a single flash-lit frame was enough to leave raw), and every flip restarted the ball detector's empty-plane calibration. With the ball on the mat the new calibration learned it as background, so the detector reported nothing while the Pi still thought a ball was present and kept the LED white.
- The source no longer changes while a ball is on the mat or armed, and leaving raw because the scene brightened now needs 24 steady frames (about 100 ms) instead of one. Turning strobe off still switches at once.
- If a switch does restart the detector while it held a ball, the Pi now reports the ball removed so the app and the LED return to searching.
- Add tests for the flash-lit frame and the ball-on-mat cases.

## Pi service 0.62.1 - 2026-10-06

- Strobe shots that cannot be measured now say why. The old message blamed the long strobe exposure, but the 250 us rule only guards the ordinary frame-by-frame measurement; the flash-copy search does not use it. The new text names what the copy search found: the ring was not flashing when the shot was analysed (with the light controller's mode and error), no copies stood out (or the room light drowned them), copies merged because the ball moved too little between flashes (with the speed that would separate them for the active flash pattern), or copies were found but did not fit the pattern.
- Always save a `diagnostics.strobe` report on strobe captures, including failed ones: light mode, controller state, flash pattern, frames searched, most copies in any frame, copy span in ball widths, and a reason code.
- When a strobe fit measures the shot, the ordinary path's exposure complaint is no longer shown as a failure.
- Add tests for each reason code and the wording. No change to which shots are measured.

## Night strobe prototype 0.8.0 / full shot review 0.1.1 - 2026-10-02

- Replay all ten brighter-setting shots and recover ball tracks of three to five positions. Export projected launch speed and angle, multi-position fit, horizontal/vertical velocity, observed displacement and duration, apparent radius change, and a stationary-to-moving departure bracket where visible.
- Calculate provisional club speed, assumed attack angle and smash factor from available consecutive two-point candidates under the user's level-camera and ball-depth assumptions. Keep feature-identity uncertainty explicit; retain shaft reflection orientation separately from face angle or dynamic loft.
- Flag inconsistent launch fits and substantial apparent size changes. Preserve original raw data and summaries; generate a standalone HTML review and JSON export with track overlays.
- Add extended review output to new single-flash demo captures and the browser page. Review errors do not interrupt raw capture saving. All 29 prototype checks pass, including timestamp units and upward/downward angle signs.

## Night strobe prototype 0.7.1 / club review 0.2.1 - 2026-10-02

- Review all nine 0.7.0 club captures: 120 Hz trigger delivery is stable, but no consistent pre-departure head-centroid track is recovered. Shaft reflections do not supply club speed or attack angle.
- Remove thin vertical shaft pixels before testing the broader head component. Saved-shot replay still rejects the nine shots; do not claim recovered measurements.
- Raise club-mode analogue gain from 1 to 4 while keeping the 250 us flash, 1.5 ms exposure and 3 percent duty unchanged to test head visibility without longer illumination blur.
- All 26 prototype checks pass, including shaft-only rejection and recovery of a synthetic visible head with an attached shaft.

## Night strobe prototype 0.7.0 / club review 0.2.0 - 2026-10-02

- Add club-specific visibility results and rejection reasons to saved captures and the demo display. Replaying existing multi-flash captures does not recover a verified pre-impact head-centre track, so club speed and attack angle remain unavailable for those shots.
- Add an optional single-flash club trial: 120 Hz trigger, one 250 us flash delayed 1 ms, 1.5 ms exposure, and a 242 fps sensor limit. Preserve both camera streams and original timestamps; only the externally triggered view enters the single-flash club speed estimator.
- Fit at least three consecutive, stable-area head candidates to an experimental image-plane speed using ball-depth scale. Reject ambiguous blobs, missing timing, inconsistent paths and post-departure samples. Never call image path direction attack angle.
- Add versioned visibility/replay utilities and four club validity tests. All 24 prototype checks pass, including accepted-copy saving and negative club cases.

## Night strobe prototype 0.6.3 - 2026-10-02

- Fix a crash when saving an accepted three-copy result: preview rendering now supports both the single-frame copy result and the multiple-frame track result.
- Reset status LEDs to searching on demo shutdown so the last processing animation does not persist after an exit.
- All 20 prototype checks pass, including a complete accepted-copy save that creates both the summary and contact preview and returns to searching.

## Night strobe prototype 0.6.2 - 2026-10-02

- After the gentle repeat retained multiple silhouettes and the faster shot had insufficient flight coverage, shorten copy-mode exposure from 19.5 ms to 8 ms and flash gaps from 5/8 ms to 2.5/4 ms. Keep 100 us flashes and 50 Hz bursts at 1.5 percent duty.
- Set the sensor frame-rate limit to 120 in copy mode to reduce the readout period under external triggering. Verify delivered timestamps before requesting another shot; the two views remain independently timed.
- All 17 existing timing, detection and rejection checks pass. Earlier rejected captures and raw images are retained.

## Night strobe prototype 0.6.1 - 2026-10-02

- Resolve touching flash silhouettes with circle voting while retaining the existing coded-spacing ambiguity and residual checks. Preserve rejected images and avoid asserting stereo or calibrated 3D measurements.
- Replay the first dark-room chip: recover three copies in each view, with image-plane estimates of 6.64 m/s at 29.5 degrees and 7.34 m/s at 24.0 degrees. This demonstrates multi-image strobe capture; the trigger pair is still not synchronized.
- Add touching-copy and empty-frame checks; all 17 prototype tests pass. Add versioned contrast review and saved-shot replay utilities.

## Night strobe prototype 0.6.0 - 2026-10-02

- Add optional external triggering of camera 0 in three-copy mode, with a 1 ms flash delay and restoration to free-running capture on shutdown. Camera 1 stays free-running; the pair is not stereo-synchronized.
- Drive searching, ready and processing status LEDs from the standalone demo.
- Add versioned stationary-light diagnostics. Removing camera 0's lens cover restored its IR image; both views locate the ball and the demo arms. Camera 0 delivers roughly 60 ms intervals with 19.5 ms external-trigger exposure while camera 1 delivers 20 ms intervals; this remains a single-view trigger experiment, not a synchronized stereo measurement.

## Status LEDs: ESP32 0.3.0 / Pi service 0.62.0 - 2026-10-01

- Show breathing blue while searching for the ball, steady white when the ball is present, and breathing orange during processing. Processing takes priority over ball presence; status returns to the current ball state afterward.
- Animate both GPIO 7 pixels locally on the ESP32 over a 2.2-second cycle at low brightness. Pi sends only changed states and resends the current state after USB reconnect.
- Add checks for state priority, duplicate-command suppression and reconnect restoration.

## ESP32 strobe controller 0.2.0 - 2026-10-01

- Add two blue status pixels on GPIO 7 at low brightness; the user confirms both LEDs are blue. Build for the current USB-to-UART connection so the Pi can communicate on UART0. Back up the previous 4 MB flash before deployment and verify the flashed firmware.
- Verify camera 0 accepts GPIO 6 external triggers: 48 frames over 2.404 seconds at 20 Hz. Camera 1 produced no frames in external mode during that test. GPIO 5 receives strobe edges, but reported counts and widths require investigation before treating them as a clean exposure window. Restore both cameras to free-running mode afterward.

## Strobe Lab prototype 0.5.3 - 2026-10-01

- Prepare the requested chip experiment at 9 us exposure with the existing three 2 us pulses. Use resting-ball geometry measured in the stationary bench and a low-signal core-brightness departure check, rather than the bright-ball arming threshold intended for longer exposures.
- Median eight frames for the microburst reference to suppress rare flash overlaps. This captures diagnostic shot windows; reliable pulse overlap and moving-shot measurement remain unverified.

## Strobe Lab prototype 0.5.2 - 2026-10-01

- Deploy the requested microburst: three 2 us pulses starting at 0/3/6 us, ending at 8 us, repeated every 4 ms at 0.15% duty. Both cameras remain at 9 us exposure and gain 4.
- Preserve the actual burst in metadata and show it in the demo. This is an unsynchronized illumination experiment, not separated ball copies or verified optical pulse timing.

## Strobe Lab prototype 0.5.1 - 2026-10-01

- Make flash width configurable and deploy the requested 2 us controller pulses with 9 us camera exposure, gain 4 and the existing 250 us flash spacing. Commanded duty is 0.8%; optical pulse shape and camera alignment are not verified.
- Retain actual sensor exposure and controller replies. The 0.5.0 iteration added configurable camera exposure and verified both cameras' minimum actual exposure is 9 us at 640x400.

## Strobe Lab prototype 0.4.0 - 2026-10-01

- Add a three-copy mode: 50 fps, 19.5 ms requested exposure, gain 1, and three 100 us flashes with cyclic start gaps 5/8/7 ms. Electrical duty is 1.5%. Analyze separated copies within each image using all possible flash phases; do not use cross-frame tracking in this mode.
- At 10 m/s, copies are 50/80/70 mm apart and each flash contributes 1 mm motion. Unequal gap ratios distinguish the unknown phase without camera synchronization; exposure boundaries can still truncate a copy.
- Preserve a live off/on raw bench at actual 19497 us exposure. Ambient light already clips part of the placement ROI at minimum gain; measured ROI flash contribution is small. This is an experiment awaiting moving shots, not proof of flash-dominated imaging.
- Use a full-range preview for long exposures. Add a timing test covering all three cyclic phases.

## Strobe Lab prototype 0.3.2 - 2026-10-01

- Log heartbeat failures and the reason for process shutdown. Run the temporary Pi demo with automatic restart after three seconds, addressing repeated unexplained exits that made the browser unavailable.
- Retain the 0.3.1 capture profile and ball locator. All thirteen focused tests pass.

## Strobe Lab prototype 0.3.1 - 2026-10-01

- Locate the resting ball in both camera views before arming, and use its actual position and diameter for trajectory fitting. This fixes the fixed-circle placement mismatch observed during live validation.
- Thirteen focused tests pass on the Pi, including displaced-ball placement. The shortened-exposure profile still awaits new wedge shots.

## Strobe Lab prototype 0.3.0 - 2026-10-01

- Halve the requested exposure to 250 us at 242 fps, with gain 4, to reduce the blur observed in the latest wedge shots. Existing ring timing, 8% electrical duty and hardware wiring are unchanged.
- Detect bright, dark and mixed-contrast ball silhouettes so tracks can continue from the mat onto the bright floor. Prefer the earliest valid interval, reject conflicting overlapping positions, and retain detailed fit rejection reasons.
- Replay preserved 0.2.0 raw captures at their original 497 us exposure: preserve the third shot's upper-camera 10.08 m/s image-plane estimate, recover lower-camera tracks on shots two and three, and continue rejecting shots one and four for excessive blur. Later and earlier image-plane interval estimates are not interchangeable launch-speed measurements.
- Add a versioned replay tool and tests for bright-to-dark transitions and stationary dark-object rejection. Twelve focused tests pass on the Pi; live 250 us shot validation remains pending.

## Strobe Lab prototype 0.2.0 - 2026-10-01

- Review and preserve the first three actual wedge shots plus one placing-hand trigger. Both camera windows captured departure, but the 8 ms images did not resolve separate flash copies; no measurement was emitted.
- Switch the next experiment to 242 fps, 500 us exposure and gain 2, with twenty-microsecond flashes every 250 us (8% electrical duty) on the existing ESP32. IR now illuminates short exposures; motion is timed by sensor timestamps rather than flash-copy separation.
- Add conservative round-ball trajectory fitting across at least three consecutive frames, size/blur/origin/residual checks and rejection of competing trajectories. Outputs remain image-plane estimates and the old long-exposure captures are not reclassified.
- Add a hands-clear arming check and normalized shape comparison so illumination changes do not alone fake departure. Enlarge the raw ring to cover the faster capture window and retain post-trigger frames in contact sheets. Ten focused tests pass on the Pi; the revised profile awaits moving-shot validation.

## Strobe Lab prototype 0.1.1 - 2026-10-01

- Add an isolated, deployed Pi/ESP32 demo in `hardware/strobe-demo/`, with a browser page, dual raw capture, independent sensor timestamps, automatic ball-departure retention and contact sheets. Existing hardware wiring, firmware, app and service versions are unchanged.
- Use gain 1, 120 fps and three 100 us IR flashes spaced 1500 / 2200 us apart for the first wedge experiment. Retain the exact commanded pattern and actual camera metadata with every attempt.
- Fit all cyclic pulse phases without using assumed club speed to choose a result. Reject ambiguous copy sequences; any resolved speed/angle remains an image-plane estimate. No synchronized stereo, direction, spin or carry claim.
- Require ball-to-surroundings contrast before arming; retain unsuccessful attempts for iteration. Five focused timing/arming tests pass on the Pi. Live static capture validates frame saving and rejection of a stationary ball, with both streams sustaining approximately 120 fps. Moving-ball validation awaits user shots.

## Pi service 0.61.1 - 2026-10-01

- Auto-set judges the picture by the ball, not the frame average. The ball is under 1 % of the pixels, so on a dark mat the average is tiny even when the ball is bright, and the old search drove the gain to 16 for every club. Measured on the Pi at the driver's 58 μs shutter: gain 4 gives ball 97 on a noise-free black background; gain 16 gives ball 211 on a background at 26 with noise 32 (and at 100 μs gain 16 the ball is 66 % saturated). The sweep now measures the brightest compact region (the 99.5th percentile of the frame) and aims for the target level; for an evenly lit frame this equals the mean, so such scenes are unchanged. When it has to raise the gain it keeps going until the level is near the target (a ball just over the minimum is fragile), later steps over-correct because the picture's brightness grows more slowly than the gain, an overshoot is brought back down, and the result carries `ballLevel` next to `meanBrightness`.

## Pi service 0.61.0 - 2026-10-01

Review of all 99 retained captures (every shot on the Pi), and the changes it justifies.

- What the captures show. 81 shots were taken at 250 μs or less and 31 of them (38 %) were measured; the other 50 failed with "fewer than three usable 3D ball outlines", and the success rate follows the ball's size in the image exactly as the notes say: 28 % with a 15-20 px ball, 42 % at 26-36 px, 69 % at 39-47 px. The other 18 rejections are the hard 250 μs exposure gate, all of them strobe-mode shots (3.9 ms) in a lit room, where the ring's flashes are lost in the room light and every shot is thrown away by design. The camera is now much closer (the ball is 44-54 px wide), which is the good range; the day's shots simply were not taken in a measuring mode.
- Fix: the saved raw frames missed the impact. A plain "last 100 frames" raw ring had already discarded everything before the hit by the time the departure was confirmed (about 100 frames later), so every raw capture started 20 frames after the impact. The raw ring is now pinned the moment the ball first looks gone: it keeps the frames from just before that and the next 60, then stops adding raw frames, so memory stays bounded (at most 160 raw frames per camera, usually about 90) and the saved window really covers 25 frames before to 45 after the impact. A false alarm releases the pin.
- Auto-set now respects the blur limit for the selected club. The measurement rejects a ball that smears more than 4 mm in one exposure, so the longest usable shutter is 4 mm divided by the ball's speed (driver 58 μs, 7-iron 85 μs, pitching wedge 102 μs, putting unrestricted); the sweep used to look only at brightness and could settle on a shutter the measurement would then reject. It now stays under that limit and buys brightness with gain, and says so when that is still too dark ("Still dark at the 58 us shutter this club needs...", with `blurLimitUs` in the result).
- Plain-language rejection reasons (new `rejection_hints.py`). The cryptic messages now lead with the cause and the fix: a strobe-mode shot in a lit room says the flashes are lost in the room light and to switch Light to Auto, Flat or Daylight; a long shutter outside strobe says how much a 10 m/s chip smears in it and to run Auto-set; too few outlines says how wide the ball is and, if it is under 35 px, to move the camera closer. The original text is kept in the message and in `diagnostics.rejection.original`. Nothing changes about which shots are measured.
- Tried and rejected: a fallback that estimates speed and angle from the presence tracker's own positions. Validated against the 31 strictly measured shots it found a path in only 13 and a reliable one in 4, and gave a reliable estimate for only 3 of the 68 unmeasured shots, because the saved track follows the resting ball and at most one to three moving points. Not shipped.

## Pi service 0.60.0 - 2026-10-01

- The ball detector can run on frames built from the raw 10-bit data (new `raw_frames.py`). Corrected first: raw words are the 10-bit count x 64 (they step by 64), not x 16, and libcamera's black level of 4096 is what the image processor subtracts, not where the data starts (the sensor has already removed its pedestal; the data floor is about 1024 words). `PINPOINT_RAW_BLACK_LEVEL` overrides it.
- Raw is not simply better, and this is deliberate. Measured on the Pi with a ball far above the 64-count crush, the 8-bit picture had the higher signal-to-noise (ball 79 against a black, noise-free background at 60 μs, SNR 158, versus SNR 11 for a raw-derived frame at 1 count per level) because the processor's black crush works as a free noise gate; raw only wins when the signal is under about 64 counts. So in the default `auto` setting (`PINPOINT_ANALYSIS_SOURCE`) the detector and rolling buffer get raw-derived frames only while the ring is strobing AND the scene is dark enough not to saturate (99.5th percentile under 120 counts to enter, over 200 to leave, 12 steady frames to enter, only the primary camera decides); otherwise they get the 8-bit picture exactly as before, so normal shooting is unchanged. When the source switches the detector restarts its calibration, because an empty-plane reference learned from one kind of frame is wrong for the other. `raw` forces raw, `isp` never uses it; `PINPOINT_RAW_COUNTS_PER_LEVEL` sets the mapping (default 1).

## Pi service 0.59.0 - 2026-10-01

- Raw 10-bit capture (`PINPOINT_CAMERA_RAW=true`). The sensor reads 10 bits, but the image processor squeezes them into an 8-bit picture: it subtracts 64 counts (a black level of 4096 words that the sensor has in fact already removed) and then applies a gamma curve of about 0.45, so anything under 64 counts comes out as exactly 0. At a 20 to 100 μs exposure 99.8 to 100 % of the 8-bit picture was 0 while the raw data held a clear signal. Each frame now also carries its linear raw data: the 10-bit count x 64 in a 16-bit word (words step by 64, full scale 65472), with the data floor at about 1024 words. It is 0.5 MB a frame, less than the 0.77 MB 3-channel 8-bit image, and sustained 242.0 fps with no dropped frames on the Pi in testing.
- The Pi has 1 GB of RAM, so only the last 100 raw frames per camera are kept (`PINPOINT_RAW_BUFFER_FRAMES`, about 100 MB for both cameras) and only the frames from 25 before to 45 after the impact are written to the capture folder, as 16-bit `raw-NNNN.png` files with a `raw` entry in `capture.json` (scale 64, black level 1024) (`PINPOINT_RAW_SAVE_BEFORE` / `_AFTER`). Off by default; nothing changes without the setting.
- The strobe copy analysis now works in raw counts when raw frames are present: copies 30 counts above the background (invisible in the 8-bit picture, where they come out as 0) are found, with a lower detection threshold. Without raw frames it falls back to the 8-bit frames as before. The result reports which source it used.
- The existing ball tracking and launch measurement still use the 8-bit picture.

## Pi service 0.58.0 - 2026-10-01

- Ball speed and launch angle from the flash copies of the ball in one strobed frame (new `strobe_copies.py`). In strobe mode, after a shot the analysis looks at the frames just after the ball leaves, picks out the round, ball-sized bright discs (after removing the empty scene), works out which flash made each one from the known uneven gaps (every possible start in the repeating flash sequence is tried and the straightest fit wins) and turns the slope of position against flash time into speed, scaled by the ball's known diameter. It runs only while the light controller reports strobe, uses the exact pattern and rate the ESP32 was given, and reports `ballSpeedMps` and `launchAngleDeg` only when the fit is reliable (at least four copies in a straight row, or three that also match the club's expected speed; residual under 3 mm; a launch angle between -10 and 80 degrees; not ambiguous between two starting flashes). On the 11 real lit-room captures from 2026-10-01 it adds nothing, as it should; otherwise nothing is added and the shot looks as before. The values are marked as estimates: image-plane, side-on, scale from the resting ball. A failure in this step is logged and never breaks the analysis.
- Developed and tested against synthetic frames only (17 tests: speed within 3-4 % for every club family, every start flash, noise, background removal, a wrong pattern flagged as unreliable). It still needs real dark-room captures to tune the thresholds. Light status now also carries `rateHz`.

## Pi service 0.57.1 - 2026-10-01

- Strobe flash pattern now follows the selected club, not just its group. Each club's expected ball speed (club speed times smash) sets the gaps between flashes and the pulse width: gaps keep neighbouring ball copies from overlapping even when the ball is 20 % slower than expected (1.1 ball widths apart) and grow 8 % each so every copy can be told apart; the pulse blurs the ball by about 1.2 mm, so fast balls get short pulses (driver 19 μs) and slow balls longer ones with more light (sand wedge 40 μs). Driver: 4 flashes about 0.95 to 1.1 ms apart; 7-iron: 2 flashes 1.4 ms apart; lob wedge: one flash per frame, because two flashes cannot stay clear of each other inside one 4.1 ms frame at that speed. Status `light.pattern` carries `pulseUs`, `gapsUs` and `ballSpeedMps`; `light.preset` still names the club group, so existing apps are unaffected.

## App 3.44.0 / Pi service 0.57.0 / protocol 2.40.0 - 2026-10-01

- Light modes for indoors, outdoors and dark rooms. The Device screen's Strobe switch becomes a Light selector: Auto, Daylight, Flat and Strobe. Daylight turns the IR ring off and lets the sun light the ball with a short shutter (30 μs by default); Flat keeps the ring steady, as before; Strobe flashes the ring for a dark room. Each light remembers its own shutter and brightness boost, so moving between a sunny garden and a room never costs the settings tuned for the other.
- Auto-set for this room now also picks the light. With the ring off it runs the usual exposure sweep; a usable picture at 100 μs or less means daylight and the ring stays off (it also saves the battery), otherwise the ring goes steady and the sweep repeats. The result says which light was chosen.
- New `light_controller.py` talks to the ESP32 on the ring over USB (`PINPOINT_LIGHT_CONTROL=esp32`). Nothing changes unless that is set. It keeps a heartbeat, reconnects after the cable is replugged and re-applies the wanted mode. In strobe the flash pattern follows the selected club: driver and woods, irons, or wedges and chips.
- ESP32 firmware (hardware/strobe-test/strobe_master): modes `off`, `flat` and `strobe`, a `chip` preset, and a watchdog that returns the ring to steady light if the service stops talking to it for 3 s. It boots in flat light.
- Strobe captures are still saved for review only; launch measurement needs an exposure of 250 μs or less.

## App 3.43.0 / Pi service 0.56.0 / protocol 2.39.0 - 2026-10-01

- Add a strobe test mode for the flashing IR ring (hardware/strobe-test). The Device screen has a Strobe mode switch above Shutter speed. Turning it on remembers the normal shutter speed and sets a 3900 μs exposure, just under one 242 fps frame, so the ESP32's flash bursts land inside the exposure and one picture holds several copies of a moving ball. The shutter limit rises from 250 to 4000 μs only while the mode is on, and turning it off restores the remembered shutter speed.
- New BLE command `setStrobeMode`; `exposureControl` gains `strobeMode`, and the app hides the switch when a service does not report it. Automatic exposure is refused in strobe mode.
- Strobe-mode captures are saved for review only: launch measurement still needs an exposure of 250 μs or less, so they carry a warning and no measurements. Shoot or roll a ball in a dark room with the ESP32 strobe running, then look at the saved frames in History.
- The exposure field now takes four digits.

## Pi service 0.55.3 - 2026-09-29

- Find fast hits that pairing cannot. A ball hit at 17 to 28 m/s is in view for two or three frames, and a blurred or dark one is not found as a clean circle in every frame of either camera, so matching a circle in the lower camera to a circle in the upper one frame by frame found nothing. When that fails the Pi now runs a flight search: it takes everything ball-sized that appears after the hit, in either camera at any frame (a circle where there is one, otherwise a patch that differs from the scene just before the hit, whether the ball is bright on the mat or dark against the window), tries about 100,000 launches from the known resting ball (3 to 80 m/s, launch angle, direction, contact time), keeps the best, centres each sighting and refines. It rejects the answer if a different launch still fits about as well after refinement, if one camera supplies all the sightings, or if the residual stays over 3.5 px.
- Results from the search are accepted with looser image and ray limits (3.5 px, 6 mm) and always stay estimates with a warning saying the ball was found by the search. On the 38 newest saved captures it recovered 5 real hits at 17 to 28 m/s that were discarded, lost none, changed no measured shot, and every hand, foot, nudge and dark false trigger stayed rejected. Against shots measured another way it agrees within about 3 percent in speed, 1 degree in launch and 3 degrees in direction.
- Not recovered: a 31 m/s hit whose sightings disagreed by 10 mm in the ray check.

## Pi service 0.55.2 - 2026-09-29

- Recover real hits the ball tracker loses. When the single-camera tracker fails, the two cameras search for the ball on their own, but that search looked for the resting ball only in the first half of the burst. These bursts hold a long address (the hit falls around frame 100 of 182), so the search never reached the hit and reported no candidates at all. It now scans the whole burst. Replayed over the 32 newest saved captures, 29 were unchanged, 2 were recovered and none changed or was lost; one recovered shot is from 09-26 whose live result was 9.46 m/s at 34.8 degrees and now reads 9.5 at 34.7.
- A single-camera track slower than 0.3 m/s no longer vetoes that search. After a fast hit the tracker sometimes follows a static object (a shadow, the shaft, a foot) for dozens of frames at about 0 m/s, and the two-camera search deferred to it. It now starts fresh from the resting ball instead.
- Still lost: balls so large (65 px across) that they leave the view in about a frame and a half, and balls under 40 px.

## Pi service 0.55.1 - 2026-09-29

- Ball size is now a red "Fix before you hit" with the distance to move. Across every saved capture since 2026-09-25 the ball's size in the lower image decides most outcomes: 40 to 56 px across was measured 44 times in 53, under 40 px once in 14 and over 56 px 3 times in 10. Twelve shots this morning lost four real hits to it (balls 31, 61, 60 and 65 px across); a big ball crosses the view in about three frames, then the tracker either finds nothing or follows a static object. The placement check was an orange warning without a distance; it is now a failure that says how far to move from the ball's size and the lens ("about 12 cm further from the cameras"), and the lower limit rose from 32 to 40 px.
- Not fixed: an address with the club touching the ball can still read as the ball leaving, and a ball hit dark against the bright window on the right is lost. Both are lower-camera tracking limits that staggering does not touch.

## App 3.42.0 / Pi service 0.55.0 / protocol 2.38.0 - 2026-09-29 (branch staggered-cameras, experimental)

Staggered cameras: the upper camera runs half a frame behind the lower one, so together they sample the ball every 2.07 ms instead of every 4.13 ms. Off by default; set `PINPOINT_CAMERA_STAGGER=true` in `/etc/default/pinpoint` to try it.

- Capture. With the flag on, the two sensors free-run with no libcamera sync. At start the upper camera is restarted until its phase behind the lower one is within 0.35 to 0.65 of a frame (about 3 to 7 tries), then held; measured on the Pi it stayed within 20 microseconds over a minute and drifted under 1 microsecond per second. Each pair is an A frame with the B frame half a frame later, and every pair's phase is watched. If the lock cannot be made the cameras fall back to the in-step pair and the app says so.
- Drift handling. Phase within 0.3 to 0.7 is locked. Between 0.2 and 0.3 (or 0.7 and 0.8) the Pi re-locks at the next moment the mat is empty. Beyond that, ball detection is paused and the app shows "Cameras out of step" until the mat is clear and the re-lock finishes, a few seconds. A failed re-lock is retried every 30 seconds while the mat is clear. The upper camera is only ever restarted with no ball present.
- Analysis. `stereo_check` recognises a staggered burst from the frame times, finds the ball in each upper frame from the lower camera's track interpolated to that frame's own instant, and fits with every detection at its own timestamp. Two staggered pairs are four sample instants and are now enough for a full fit (in step they give only a speed estimate). On noisy synthetic frames at 54 to 66 m/s the in-step mode found nothing and the staggered mode fitted 6 to 7 of 12 shots with about 1 percent speed, 0.2 degree launch and 0.5 degree direction error; at 48 m/s it went from 6 to 12 of 12. Where the ball stays in view for many frames it is no better than in step. Club stereo and stereo calibration need simultaneous views, so club stereo is skipped on staggered bursts and calibration refuses to run in staggered mode.
- Saved bursts record `dualCamera.mode: "stagger"` with the nominal offset. Nothing changes with the flag off.
- Not yet tested on the device with a real swing; see scripts/test-stagger-phase.py and scripts/simulate-stagger.py.

## Pi service 0.54.1 - 2026-09-29

- Reword the resting-ball error from the top camera. It told you to recalibrate with the AprilTag, which is no longer used. The usual cause is a ball touching a foot or hand: the lower camera outlines the two as one blob and the top camera cannot find the ball where that box puts it. It now says so, and still mentions a moved camera or stand. Seen on 2026-09-29 with a ball beside a bare toe (ball box 39 x 73 px).

## App 3.41.0 / Pi service 0.54.0 / protocol 2.37.0 - 2026-09-28

Works wherever the stand is put down: no AprilTag needed.

- Take the ground from the stand instead of a tag. The stand is assumed level on the surface the ball is hit from: gravity runs down the rig at the lower camera's pitch, the target is to the right of where the bottom camera points, and the camera height is a stand constant. Each shot corrects that height from the resting ball (up to 40 mm; it was 25 mm from the tag), and shots whose height the two cameras cannot confirm are flagged. Nothing looks for the tag any more; `PINPOINT_GROUND_MODE=tag` restores the old behaviour.
- Add `rig.json`: the stand's pitch, sideways lean and height, written once. `install.sh` derives it from the saved tag calibrations of both cameras, fusing the two tag views through the stereo pair so a noisy single-tag tilt is averaged with a second view and held consistent with the checkerboard geometry. `python rig_pose.py --from-tags|--set PITCH HEIGHT|--show` manages it. A lean inside the tag noise floor (1 degree) is taken as level.
- Replayed on the Pi's 28 newest real shots with identical frames and stereo pair, the rig agrees with the tag pose: ball speed within 0.006 m/s, launch angle within 0.26 degrees and start direction within 0.23 degrees, with two-camera tracking accepted in the same 25 shots. Attack angle moves 0.26 degrees because the tag's 0.26 degree sideways lean is now taken as level. Tilted by half a degree, launch moves about 0.4 degrees per half degree of sideways lean and start direction about 0.2 degrees per half degree of pitch, as the geometry predicts.
- The single-camera fallback (used when the two-camera fit fails) is much more sensitive: on two saved shots half a degree of pitch turned a 32 degree launch into a ground roll. Treat those results as estimates.
- Add a Ground readiness item for the rig ("Level rig, no tag needed" with the constants, or a warning when only default constants exist) and status `rig`. The Calibration screen shows the rig constants instead of asking for the tag. Shot coverage uses the rig pose.
- Add `scripts/compare-ground-modes.py`, which replays saved captures with the tag pose and the rig and reports the differences and the height correction the ball asked for.
- Keep in mind: the level assumption cannot be checked per shot. A stand on a sloped mat or with one foot propped is read as level; a lean along the target line shifts launch angle about one for one, and pitch error shifts direction by about its size times the tangent of the launch angle.

## App 3.40.0 - 2026-09-28

Side-by-side testing against another launch monitor (first target: a Foresight GC3), and sessions to keep the tests organised.

- Add sessions. Start one from the Sessions tab (or the banner on the Monitor screen) and every shot is filed under it until you end it; a session can be resumed, renamed, given notes and a reference-monitor name, and deleted (its shots stay in history). Sessions are kept on the device and in the signed-in account. The Sessions screen has a session picker, and every average, club table and chart follows the picked session. A shot can be moved between sessions from its detail screen.
- Add reference data entry. Each shot's detail screen has a Reference launch monitor card: type in what the other monitor showed for the same swing (ball speed, club speed, launch angle and direction, backspin, spin axis, attack angle, club path, carry, total, apex) in your display units, with Left/Right toggles instead of signs. Everything is optional; entries are validated (ranges, ball speed against club speed, total against carry) and stored with the shot in SI units.
- Add comparison. The shot card shows LM1, the reference and the difference per metric. The session view shows bias, scatter (standard deviation of the difference) and mean absolute error per metric, overall and per named club, so a club with a consistent offset stands out. Excluded shots are left out. LM1 values that are model estimates (carry, total, apex, spin) are labelled, and LM1 club speed, smash, attack angle and club path count only when the camera resolved them.
- Add CSV export of the picked session (Share sheet on the phone, clipboard on web): one row per shot with LM1 and reference columns side by side in display units, LM1 spin source and capture id.
- The comparison ignores the spin axis of 0 the app stores when the camera saw none, and flips the Pi's axis (positive = draw) to the reference convention (positive = fade).
- A capture re-sent for a shot already held no longer discards its session, reference data or excluded flag, and keeps its shot number.
- No measurement changed and the Pi is untouched: service 0.53.0 / protocol 2.36.0.

## Pi service 0.53.0 / protocol 2.36.0 - 2026-09-25

- Take the ground under each shot from the resting ball: both cameras triangulate the 42.67 mm ball on still frames before the swing (the cleanest of three), and the world is shifted so the surface under it is the ground for every fit. Offsets up to 25 mm are corrected; larger ones mean the views matched different things. The stereo resting-height gate is now that 25 mm gross check. On nine chips rejected or estimated at +9..12 mm, the ball measured -2.5..+2.2 mm and three more received two-camera ball values; the +9..12 mm came largely from the stereo fit's own rest-point method, not the surface.
- Placement guidance in the setup check, using the ball as the ruler: from its size in pixels (mm per pixel at the ball) and the room behind, ahead and above it, predict club and ball frames at the player's last five measured speeds (or a typical full swing) and say which way to move the ball. Calibrated on 16 real chips: the head's visible path is ~1.4x the room behind the ball, the first two frames after contact are unusable, and 5+ predicted frames gave club data every time. Balls under 32 px or over 56 px across are flagged.
- The setup check no longer fails a ball that sits a few mm off the calibrated ground; only camera disagreement or a gross offset fails it.

## App 3.39.0 / Pi service 0.52.0 / protocol 2.35.0 - 2026-09-25

- Swing loop above ball speed on the Monitor card and in shot details: the captured swing from 10 frames before the ball moves to 9 after, looping in slow motion. Tap to stop on a frame, step with the arrows or tap the bar to jump (impact marked); tap again to resume. Frames come from the new `captureClip` command: a fixed crop around ball, club and early flight at 240 px, display-brightened, about 1.5-2.5 KB per frame, fetched once per capture in batches of 8.
- Ignore persistent changes when finding the club: a white shoe that shifted slightly differed from the background in every frame and both club trackers followed it at 0.0 m/s.
- Count any club seen near the ball as swing evidence: a topped chip with the club in all 10 frames before impact was classified as a roll with no club.
- Stereo resting-ball height limit 8 mm (was 5): six balls on one soft mat read +1.4..+7.1 mm; stand or tag errors (-16..-20 mm) are still caught.

## Pi service 0.51.0 - 2026-09-25

- Stereo start check allows for contact timing. Contact happens anywhere between the last still and first moving frames (4.1 ms), so the fitted start can sit up to speed x 4.1 ms back along the flight (45 mm at 10.9 m/s); the old plain distance to the resting ball failed good shots against its 30 mm limit. The check now measures the distance to the nearest start any contact time in that window could produce, and reports the implied contact time. On ten recent shots offsets of 17-29 mm became 1-3 mm, with contact 1.3-3.1 ms after the last still frame.
- Club tracking tries both points (hosel, head) with and without the frame just before the ball moves, and uses the best-ranked track that passes the attack-angle, smash and speed checks. Club data on the last ten shots: 5 (was 3); the morning's 15 chips unchanged at 13.
- Save 64 frames after impact (was 48) so saved captures can be replayed through the stereo ball check.

## Pi service 0.50.0 - 2026-09-25

- Track the club head as well as the shaft/hosel point. A visible chrome head broke the hosel point: its lowest point lies on the rounded sole, seen at different spots by the two cameras (13-20 mm ray gaps), and over the light floor the head is darker than the background, so the brighter-only mask kept just the shaft. The head is found by change in either direction in a ground-level window behind the ball, and the point giving the longer consistent track is used. Replay: morning dark-wedge chips 13 of 15 with club data (one recovered by the head point); today's chrome-head chips still 1 of 5, limited by the head being in full view for only 2-4 frames with the ball 18% from the image edge.
- Reject club tracks with an attack angle outside -25..+15° or smash outside 0.7-1.55, for both camera paths. A single-camera track had reported a -34° attack angle on a chip.

## Pi service 0.49.1 - 2026-09-25

- Add `PINPOINT_GROUND_TAG_THICKNESS_MM`: the height of the ground tag's printed face above the hitting surface. With the tag on a 4 mm plate every resting ball read about 4 mm low and failed the 5 mm stereo resting-height gate; on five real chips the error moved from -1..-6 mm to -2..+3 mm with 4 mm set. Both cameras' world frames shift together, so triangulation is unchanged. Saved-capture replays apply the same shift.

## App 3.38.0 / Pi service 0.49.0 / protocol 2.34.0 - 2026-09-25

- Add named clubs ("My clubs" in the club picker): a name, the club type the models use, optional loft and the measured face size, with a how-to-measure guide. Clubs are stored on the device and in the signed-in account.
- Send the selected named club with `setClub`/`arm`; the Pi echoes `bagClubId`/`bagClubName` on each capture so a shot is credited to the club that was selected on the Pi, and writes its face size as the club profile the strike analysis reads (never replacing a hand-made profile).
- Group session statistics, dispersion and gapping by named club, so two sand wedges keep separate numbers. Shot lists, details and the Monitor card show the club's name.
- Strike location still needs the clubhead to stand out from the mat: replaying 15 real chips with a 78 x 50 mm profile found only the 50-54 mm shaft/hosel highlight, which the face-span check rejects.

## App 3.37.0 / Pi service 0.48.0 - 2026-09-25

- Replace the flight model in both the app and the Pi. Checked against Trackman PGA Tour averages, the old model carried a driver 190 yd instead of 275 with a 13 yd apex; the new spin- and speed-dependent aerodynamics carry driver to wedge within 1-7%, with height and landing angle close. App and Pi produce identical carry.
- Add model estimates from the measured launch: total distance, roll (on an assumed green for short steep landings, fairway otherwise), offline distance on the start line, apex, landing angle and hang time. Shown in shot details and, for total and apex, on the Monitor screen. All are labelled as calculated, never observed.
- Estimate dynamic loft and spin loft from launch and attack angle with a rolling-contact impact model; it reproduces a tour 7-iron's ~21° dynamic loft. When launch sits more than 40° above the attack angle the model has no stable answer (one replayed chip gave 65°), so lofts are shown as unavailable.
- Estimate backspin from club speed, launch and attack angle (fitted to tour spin within 10%) instead of the club average whenever the camera resolved the club; the club average remains the fallback. Carry, the simulator and session stats all use the same spin.
- Add session tools: per-club averages with ± spread, carry/offline dispersion plot, gapping between clubs, and a per-shot "Exclude from session stats" toggle that syncs with the shot.

## App 3.36.0 / Pi service 0.47.0 / protocol 2.33.0 - 2026-09-25

- Measure the club with both cameras. The dark head barely shows on the mat, but the lit shaft and hosel highlight do; their vertex is triangulated in both views like the ball, with no swing-plane assumption. Club speed, attack angle and club path come from its 3D track. Replaying 15 real sand-wedge chips resolved 12, with smash mostly 1.16-1.38 (the single-camera path read 1.35-1.61, about 20% low on club speed).
- Three frames are the minimum for every fitted motion: club (stereo and single camera) and ball trajectory, ball-size check and putt roll. More consistent frames join the least-squares fit; from five frames a constant-acceleration term follows the swing arc so attack angle is the value at impact, not the window average.
- Keep the five-parameter free-start roll at six frames: on three frames it fits any track exactly and returned 0.1 m/s at 84° launch in a regression test.
- Reject a club speed whose smash exceeds 1.55, above any real club.
- Show attack angle and club path on the Monitor screen and in shot details, with the reason when unavailable. `clubPathDeg` is reported only from the two-camera track.

## App 3.35.0 / Pi service 0.46.0 / protocol 2.32.0 - 2026-09-25

Workflow fixes from an audit of 40 real captures, where measured shots were lost or polluted by setup faults that were only reported after the swing.

- Check setup when the ball is placed: camera alignment (top camera offset, ray gap and resting-ball height, using the same limits as the stereo fit), ground calibration, exposure against the selected club's typical ball speed, and the clubface profile needed for strike. The Pi sends a `readiness` event and `status.readiness`; the Monitor and Putting screens show what to fix before hitting. Advisory only; it never blocks a capture.
- Keep shots whose ball was measured when the club was not tracked. Club speed, smash and strike are shown as unavailable with the Pi's reason instead of the shot being discarded.
- Classify full-shot movement that cannot be a strike as `not-a-strike`: under 2 m/s, more than 60° off the target line, or a ground roll with no club. These no longer enter shot history or reach the simulator.
- Stop filling club speed, smash and strike from the club profile in the app. Missing values are null with a reason; older saved shots marked as club estimates display the same way.
- Accept a tag-free club track of three clean frames (was four). On the stand the head is in view for 4-5 frames, of which the first is clipped by the image edge and the last merges with the ball; replaying 15 real chips recovered club speed on 13 instead of 7.
- Reject a tag-free club speed whose smash exceeds 1.7, which no real club produces.

## App 3.34.0 - 2026-09-25

- Save the connected Raspberry Pi camera, capture, calibration, placement, and target-line settings to the signed-in user's Supabase preferences.
- Refresh preference timestamps when an existing preference is updated.

## App 3.33.0 / Pi service 0.45.0 / protocol 2.31.0 - 2026-09-25

- Allow three clean paired stereo frames to receive measured-grade status when every existing timing, geometry, calibration, uncertainty, and fit-quality check passes.
- Keep the two-frame path as an estimated ball-speed-only fallback.

## App 3.32.0 / Pi service 0.44.0 / protocol 2.30.0 - 2026-09-25

- Register putting captures even when face strike cannot be measured, and sync the putt to the signed-in Supabase account from the capture event if the Pi's putt event is absent.
- Let the user explicitly recover a saved putt from the Pi into their account. Mark airborne captures and avoid showing fabricated roll or pace values.
- Show putt cloud sync errors instead of silently discarding them.
- Keep airborne putting captures out of automatic simulator sends and avoid duplicate sends when both capture and putt events arrive.

## App 3.31.0 / Pi service 0.43.0 / protocol 2.29.0 - 2026-09-25

- Show the Pi's current capture mode in the shot screen and provide a one-tap switch from Putting to Normal shot, including when putting is already armed.
- Add a direct Normal shot switch on the Putting screen and keep the mode label in sync after reconnecting.
- Block mode changes while a ball is detected so a live capture cannot change type midway.

## App 3.30.0 - 2026-09-25

- Show a camera-pair calibration fit score after validation, with explicit 100-point targets and the original error values.

## Pi service 0.42.0 - 2026-09-24

- Save a shorter full-shot burst after measured departure, while retaining the longer putting capture and keeping both cameras aligned.

## App 3.29.0 - 2026-09-24

- Upload every retained original-resolution camera frame for a shot to private Bunny Storage, with per-user Supabase frame records and resumable Pi uploads.
- Show full-resolution frames in shot review after upload, even when the Pi is disconnected, and show upload progress in shot details.
- Update the Pi service to 0.41.0 / BLE protocol 2.28.0 for direct ticketed frame uploads.

## App 3.28.2 - 2026-09-24

- Preserve Bunny image paths when shot data syncs again, including from older app builds.
- Recover a missing image path from Bunny when restoring account history, or re-upload the capture from a connected Pi when the Bunny image is absent.
- Show shot image upload errors on the Home screen so a failed camera image cannot look like a successful cloud upload.

## App 3.28.1 - 2026-09-24

- Link the LM1 Supabase project, reconcile the existing cloud schema migration, apply shot image columns, and deploy the authenticated `shot-images` Edge Function.
- Configure the Bunny Storage endpoint as a function secret. The storage password still needs to be added in Supabase before image uploads can run.

## App 3.28.0 - 2026-09-24

- Install the Supabase server skill and migrate the shot image Edge Function to `@supabase/server` user authentication with row-level-secured database access.

## App 3.27.0 - 2026-09-24

- Save each signed-in user's live shots and putts to Supabase, upload primary and upper-camera shot images to private Bunny Storage through an authenticated Edge Function, and restore images in shot review.
- Keep pending uploads scoped to the signed-in account and stop importing the shared Pi history into a user's cloud account.

## App 3.26.0 - 2026-09-24

- Refresh Supabase Auth tokens with React Native foreground/background state and retry cloud restores once after a JWT-related failure.

## App 3.25.0 - 2026-09-24

- Update Bunny Storage setup template with the LM1 Frankfurt storage endpoint and clarify that uploads require the write-capable storage password; CDN configuration is optional.

## App 3.24.0 - 2026-09-24

- Document Bunny Storage upload secrets as server-side Supabase Edge Function configuration; keep them out of the Expo client environment.

## App 3.23.0 - 2026-09-24

- Require a restored Supabase session before mounting the LM1 app, device providers, and feature tabs.

## App 3.22.0 - 2026-09-24

- Complete the initial Supabase account lifecycle with signup confirmation messaging, password reset email requests, and visible auth status feedback.

## App 3.21.0 - 2026-09-24

- Add optional Supabase account support, offline upload queues for shots and putts, a cloud account screen, and an initial row-level-secured cloud schema.

## App 3.20.0 / Pi service 0.40.0 / protocol 2.27.0 - 2026-09-24

- Estimate interval-average ball speed from exactly two clean stereo ball matches when their timing, ray geometry, resting-ball path, and one-pixel speed sensitivity pass strict checks.
- Keep two-frame speed explicitly estimated; do not infer launch angle, direction, carry, or a measured-grade trajectory from two positions. Reject weak geometry rather than filling numbers.
- Show two-frame speed provenance and uncertainty in iPhone capture review.

## App 3.19.1 / Pi service 0.39.1 / protocol 2.26.1 - 2026-09-24

- Show when a valid single-camera trajectory was used after stereo matching failed, and report stereo and mono failures separately when neither yields a trustworthy launch measurement.
- Do not label a failed capture as having a single-camera measurement or mark a rejected stereo track as matched.

## App 3.19.0 / Pi service 0.39.0 / protocol 2.26.0 - 2026-09-24

- Restrict automatic ball placement and arming to the lower camera's left half (`x = 0%–50%`, `y = 30%–98%`), leaving the right half for left-to-right launch tracking. A ball crossing the zone boundary is rejected unless its full contour fits inside.
- Move the live-preview target ring to the centre of that zone and explain the upper camera must also keep the ball visible.
- Migrate only the previous stock ROI during offline Pi updates; preserve user-customized zones.

## App 3.18.2 - 2026-09-24

- Show start direction consistently as a magnitude with L/R in shot review, capture review and history.
- Explain the left-to-right rig convention: R/positive means toward the cameras, L/negative means away. Keep the numeric sign unchanged in stored data and simulator messages.

## App 3.18.1 / Pi service 0.38.1 / protocol 2.25.1 - 2026-09-24

- Preserve tag-free silhouette club speed, smash factor and attack angle when no club marker profile is installed; an explicitly mismatched marker profile is still rejected.
- Stack ball speed and carry on phone-sized shot reviews so the carry and measurement summary remain visible.
- Label the assumed backspin used for carry without presenting it as camera-measured spin.

## App 3.18.0 / Pi service 0.38.0 / protocol 2.25.0 - 2026-09-23

- Carry is always a still-air flight-model estimate from launch speed, angle, target-line direction and backspin, never a landing measurement.
- When spin is unavailable, use the selected club's typical spin scaled for shot speed and, when measured, adjusted for attack angle. Surface-spin failure remains visible in the capture review.
- Retire the vacuum carry and club carry-factor calculations. Recalculate legacy app shots with the new model and label the model limits and assumed inputs.
- Expose carry-model spin provenance on the Pi capture, and apply the same fallback to OpenGolfSim.

## App 3.17.0 / Pi service 0.37.0 / protocol 2.24.0 - 2026-09-23

- Added a separate fixed-pair calibration window with both live views, board settings, synchronized capture, held-out validation and explicit activation.
- New `stereo_calibration.py` supports app-driven calibration and offline session solving, fixed lens inputs, symmetric checkerboard ordering, timing/diversity checks, versioned sessions and activation backups.
- Activated pair geometry now supplies the top camera's world pose from the bottom camera's ground pose. Lens/resolution/camera-order mismatches reject stereo instead of reusing stale geometry.
- Shot capture pauses during the calibration window; the lease expires after disconnection. Existing calibration and history are preserved until explicit activation; active pair snapshots accompany new captures.

## App 3.16.1 / Pi service 0.36.1 / protocol 2.23.0 - 2026-09-23

- Zero shot direction always follows the bottom camera's left-to-right axis projected onto the ground. Legacy manual target lines are ignored, not deleted.
- Calibration screen explains automatic direction and removes manual roll controls. AprilTag rotation does not define the target heading.
- Direction grading accepts the explicit camera-relative reference; physical alignment with the intended target remains the user's responsibility.
- Regression tests cover saved-line override prevention and invariance under ground-tag coordinate rotation.

## App 3.16.0 / Pi service 0.36.0 / protocol 2.23.0 - 2026-09-23

- Reject stale target headings after ground recalibration and prevent setting the
  target from a capture made in the previous ground coordinate system.
- Separate club-motion evidence from ball movement. Captures without a resolved
  pre-impact club track stay available for review but do not become full shots
  or reach the simulator. No minimum shot speed is imposed on gentle chips.
- Prefer the joint stereo launch when its geometry checks pass, even if the
  single-camera fit succeeded. Preserve failed stereo checks and clearly name
  the actual measurement source when using the single-camera estimate.
- Recover a resting ball displaced within one diameter of the armed box, using
  a persistent stationary cluster; constrain ground stereo fits to zero vertical
  velocity. Hide club-profile placeholders for unresolved club, spin and strike
  values in the main shot views.
- Add an audit/replay script that uses each saved capture's original calibration
  and shared sensor timestamps, writing separate comparison reports.

## App 3.15.0 / Pi service 0.35.0 / protocol 2.22.0 - 2026-09-23

- Do not create or send a camera shot when speed, launch angle, or direction is
  unavailable. Keep the raw capture visible as failed tracking instead of
  replacing missing ball speed with a club-profile default.
- Preserve paired stereo frame indices and rejection counts on tracking failure.
  Show matched frames and failed speed-quality checks in capture review.
- Stop displaying an uncalibrated quality score as a percentage of accuracy for
  camera shots. Retain measured/estimated labels and individual quality checks.

## Pi service 0.34.0 / protocol 2.21.0 - 2026-09-23

- Retry independent stereo ball-circle detection with a slightly more sensitive
  edge threshold only when the normal pass cannot form a geometric camera pair.
  The recovered pair must still pass size, ray-agreement, and trajectory checks.
- Allow three paired frames spanning at least 8 ms to produce an estimated
  stereo launch. Six paired frames remain required for measured-grade metrics.

## Pi service 0.33.0 / protocol 2.21.0 - 2026-09-23

- Detect ball-sized circles independently in both calibrated camera bursts when
  the single-camera trajectory is missing or unreliable. Pair candidates by
  ray agreement and apparent size, follow a coherent 3D path, and fit speed,
  launch and direction from the paired sensor timestamps.
- Recover the last stationary ball directly from the lower burst when its old
  tracker supplies no track. Refine the upper resting-ball centre with a circle
  fit so a nearby club does not shift the stereo start position.
- Record the frame number and reason for each rejected independent candidate;
  stop searching after the ball has been absent for eight frames.
- On the saved 2026-09-23 shot, this recovers 10 paired frames that the old
  lower-camera tracker skipped. The result remains an estimate pending
  reference-launch-monitor validation.

## Pi service 0.32.0 / protocol 2.21.0 - 2026-09-23

- Use calibrated paired-camera observations for an independent stereo launch
  fit when the single-camera trajectory fit fails, including failures caused by
  unusable ball-outline size estimates.
- Require both cameras' saved lens and ground-tag calibrations, matching frame
  pairs, at least six upper-camera ball matches, close ray agreement, a plausible
  start at the resting ball, and bounded reprojection residual before accepting
  stereo recovery. Missing or poor stereo evidence leaves metrics unavailable.
- Keep stereo as a cross-check when the single-camera fit succeeds. Record both
  pose errors, pair timing, start-anchor error, stereo residual, and the
  two-camera 3D track in capture analysis; BLE metric fields remain compatible.
- This adds a calibrated stereo measurement path; accuracy still requires
  validation against a reference launch monitor.

## App 3.14.0 / Pi service 0.31.0 / protocol 2.21.0 - 2026-09-22

- Lens calibration is now per camera. The Calibration screen has a Lower CAM0 /
  Upper CAM1 selector that switches the checkerboard preview to that camera's
  live view, shows only that camera's saved/corners-found counts, and reports
  whether intrinsics are installed for it.
- `captureCalibrationImage`, `clearCalibrationImages` and `runLensCalibration`
  take `camera` (`primary` or `secondary`, default `primary`). Each camera keeps
  its own folder of views and its own intrinsics file; the second camera writes
  to `PINPOINT_SECONDARY_INTRINSICS_PATH`
  (`/var/lib/pinpoint/intrinsics-secondary.json`). Views saved before this
  release are moved into the primary camera's folder, so its counts carry over.
- Capturing for the upper camera is refused when the second stream is not
  running, instead of silently saving the lower camera's view.
- Only a primary solve clears the saved ground calibration and target line,
  because the measurement geometry is built on that lens. A secondary solve
  leaves them alone.
- Status adds `lensCalibration` (installed intrinsics per camera) and
  `calibrationCapture.cameras` (counts per camera); the existing top-level
  counts still describe the primary camera.
- The second camera's intrinsics are stored only. Stereo calibration, extrinsics
  and 3D measurement from both views remain unavailable; measurements still use
  the lower camera alone.
- Shot coverage at ~240 fps: new `shotCoverage` command and a Shot coverage
  card on the Calibration screen. It projects a putt, wedge, 7-iron and driver
  launch from the detected ball through the saved lens + ground pose, and
  reports travel per frame, visible path and the 2 possible frame counts, rated
  good (>=4), just enough (3) or too few. It also suggests moving the ball
  upstream or the camera back. Geometry only.
- 23 new Pi tests (220 total) pass. TypeScript and lint pass. Not yet run
  against the physical dual-camera Pi.

## App 3.13.0 / Pi service 0.30.0 / protocol 2.20.0 - 2026-09-22

- Dual OV9281 acquisition for vertical enclosure v0.7.2: lower CAM0 triggers
  one burst containing both views. Shared exposure/gain controls, dual live
  previews, and matching upper frames in capture review and replay.
- Software synchronization with independently buffered sensors, timestamp
  pairing within 250 microseconds, and explicit failure when either camera
  or timing lock is unavailable. Intermittent SyncReady metadata is retained.
- Saves upper frames in camera-secondary, with separate timestamps and a contact
  sheet. The main manifest records pair offsets; diagnostics include paired fps.
- Verified profile: 640x400, requested 242 fps, 10-bit mode. Full detector/preview
  run measured 241.56 paired fps and maximum 54 microseconds offset. Faster
  243-245 fps stalled; 280/300 fps in 8-bit mode failed the pairing tolerance.
- Measurement calculations still use the lower camera; stereo geometry and
  physical accuracy need calibration and validation. Existing history works.
- Versioned setup/backup/verification scripts and DUAL_CAMERA_SETUP.md describe
  placement, lighting, measured results and rollback.

## App 3.12.0 / Pi service 0.29.0 / protocol 2.19.0 - 2026-09-18

Values are now labelled measured or estimated from real quality checks, instead of every camera value showing a flat 70%.

- Pi: every reported metric is graded after analysis. It is labelled `measured` only when every quality gate passes: ground-tag pose error, trajectory-fit residual, speed and angle fit uncertainty, spin sample count, club-tag pose count, and a rolled-ball target line for start direction. Otherwise it is `estimated`, with a `confidence` that falls with each failed gate, scaled by how far the value missed. Each metric also lists its `checks`.
- Previously no value was ever labelled measured, so the app gave every camera value 70%, and the overall score was capped at 65% by the fixed strike value.
- Carry, face contact, roll/skid and all tag-free club values are always estimates, because each rests on a model or an assumption. Smash is measured only when both speeds are.
- App: every value on the shot screen shows a Measured or Estimated badge. The percentage appears only on estimates. Tapping a value opens a small window with the quality checks (passed/failed) and the device's explanation of how the value was produced. Club-profile fallbacks explain why the camera could not provide the value.
- Older Pi firmware without grades still works: its values show as estimates at the previous default.
- Measured means "passed this device's own checks". It has not been validated against a reference launch monitor.
- 6 new Pi tests for the grading; all Pi tests pass. TypeScript and lint pass.

Sharper edges for the ball and the ground tag.

- Ground AprilTag corners are now refined to sub-pixel accuracy (`CORNER_REFINE_SUBPIX`). OpenCV's default left them at the whole-pixel quad fit. On replays of the saved captures, the three worst tag poses dropped from 1.45 / 1.25 / 1.55 px to 1.04 / 1.17 / 0.96 px. The other methods were worse or lost the tag on one capture. Override with `PINPOINT_APRILTAG_CORNER_REFINE` (`none`, `subpix`, `contour`, `apriltag`).
- The ball's apparent size now comes from a sub-pixel edge fit instead of the enclosing circle of a thresholded mask:
  - 72 rays run outward from the tracked centre;
  - each edge sits at the half-contrast crossing in the flicker-corrected difference image;
  - RANSAC keeps the largest outline arc that is truly circular, and it must span at least 150°.
  Real balls are side-lit, with a dim limb that fades into the background, and on these captures the top is cut off flat by a shadow line. A plain fit averaged both in. On synthetic balls the fit is within 0.6% of the true radius when evenly lit, and within about 1.2% when side-lit or cut off flat. On real frames each fit's outline residual is about 0.3 px, and the slow putt now has an edge-fitted size in 33 of 42 frames.
- Size is weighted by its measured frame-to-frame jitter (0.65–0.9 px on real captures). The edge fit's centre is *not* used: which lit arc it locks onto shifts between frames, and it raised the track residual from about 1.5 to about 2.1 px against the template-matched centre.
- New scale self-check using the standard 42.67 mm ball: `trajectoryFit.ballSizeRatio` is the measured over the predicted apparent size. Away from 1, the tag size, lens model or ground pose is scaling every distance, and so every speed. It is a grading check (within 5% for "measured"). On replays, the two clean ground-roll shots read 0.96–0.97. The flight shot reporting a 58° launch reads 0.83, so its implausible launch is now flagged.
- Ball compression: a struck ball is flattened and ringing at contact, so the first moving frame's size, and any frame within 3 ms of it, is never used; only its position is.
- Net effect on the saved captures is modest. Speeds moved by 0–4%. Track residual is unchanged at about 1.5 px, because it is dominated by the template centre, not size. Most values stay estimates, mainly because of that residual. `scripts/replay-edge-precision.py` reproduces the comparison; results are in `output/edge-precision/`.
- JPEG replays with no reference launch monitor: tighter and more self-consistent, not proven more accurate.
- 8 new Pi tests (synthetic edge-fit accuracy and the compression window).
- Installer: `install.sh` now also installs `club_vision.py` (needed since 0.27.0, previously copied by hand) and `exposure_calibration.py` (needed since 0.28.0). Without it, an installer-only update to 0.28.0 would have left automatic exposure unable to import.

## App 3.11.0 / Pi service 0.28.0 - 2026-09-18

Usability pass over the app, plus automatic exposure.

- Automatic exposure: `autoCalibrateExposure` measures the room and picks both shutter and gain. The sweep probes a spread of shutter speeds at 1× gain, scores each frame on mean brightness and clipping, and keeps the **shortest** exposure that is still bright enough — motion blur costs more accuracy than grain does. Only when every allowed exposure is still dark does it raise analogue gain. The result is applied and persisted exactly as a manual change would be.
- The sweep runs inside the detection loop and borrows that loop's own frames, so it never opens a second handle on the camera or races the detector. Afterwards the empty-plane calibration is reset, because the new exposure changes what "empty" looks like.
- Manual shutter and gain controls are unchanged. Automatic exposure is a starting point, not a replacement, and a manual change overrides it at any time.
- Accuracy note: the target brightness (mid-grey, under 2% clipped pixels) is a reasonable default, not a validated optimum for ball tracking. It has not been checked against measurement accuracy on real shots.
- App: speeds and distances now follow a saved units preference (km/h or mph, metres or yards) applied across every screen. The calculator's own unit switch now sets that same preference instead of a second, screen-local one.
- App: the Device screen no longer shows every setting at once. Wi-Fi, simulator, automation, units and camera tuning fold away behind labelled sections with a status badge, leaving connection, health and the arm/trigger controls in the open.
- App: plainer wording throughout — "Start tracking" instead of "Arm launch monitor", "Shutter" and "Brightness boost" instead of "Exposure" and "Analogue gain", frames per second instead of raw FPS and microsecond readouts in the hero.
- App: the empty home screen is now a three-step checklist that ticks itself off, the error banner offers a route to the Device tab instead of only a dismiss, and disconnecting asks first.
- App: raised every sub-11px label to a readable size and enlarged the bottom tab targets.
- 32 new Pi tests (20 for the exposure search, 4 for the new command, plus frame measurement and planning); all 12 Pi test modules pass. TypeScript and lint pass.

## App 3.10.3 / Pi service 0.27.0 - 2026-09-18

- Clubhead speed, attack angle and club path no longer require an AprilTag on the club. The head silhouette is segmented from the existing motion background and back-projected onto a swing plane pinned to the ball at contact, which supplies the scale a monocular view cannot. Values are estimates and name the assumption carrying them.
- The tag path is unchanged and still preferred: `club-marker.json` takes precedence, and the silhouette path runs only when no club tag is calibrated.
- A camera looking along the swing instead of across it is refused rather than answered. Clubhead depth is not observable in that geometry, and the previous parallel-ray check let near-degenerate poses through.
- Head tracking selects the longest consecutive run of frames with a consistent silhouette, preferring the run nearest impact. A real head crosses lighting boundaries mid-swing and its segmented area can halve between frames; fitting across that step mixes two different features.
- Face contact (`strikeXmm`/`strikeYmm`) uses the ball's own 42.67 mm diameter as the scale reference in the contact frame, and additionally needs a one-off measured face size in `club-profile.json`. Without it both stay unavailable with a reason, never a club-profile substitute. A profile that disagrees with the measured face span is rejected.
- Start direction no longer needs the rolled-ball calibration. The target line now defaults to the camera's own across-image axis projected onto the ground, which is correct whenever the monitor is squared to the target, and is taken from the camera pose rather than the tag so tag rotation is irrelevant. A saved rolled-ball line still takes precedence, and clearing one returns to the camera axis instead of making start direction unavailable. `targetHeadingSource` records which was used.
- Added `clubPathDeg` and `attackAngleDeg` to the metric set; both flow through the existing capture record with no protocol change. Club path is produced only from a calibrated club tag: the silhouette path's swing plane is built from the ball's own direction, so a path read off it equals start direction by construction and would restate an existing measurement as an independent one. Attack angle is unaffected, because a vertical plane does not constrain vertical motion.
- Shaft lean is reported as a diagnostic only when enough shaft is resolved, instead of fitting a direction to a dozen stray points.
- App: smash factor no longer inherits the ball measurement's confidence when club speed is the club-profile fallback. In that case the ratio collapses to the profile's smash constant exactly, so it is labelled a club estimate at the weaker input's confidence.
- Replayed `capture-1789685046360385423` on the Pi: club speed 2.51 m/s over 5 accepted frames, 0.6 mm fit residual, smash 1.13 against the 2.83 m/s ball speed, start direction 1.03° against a camera-axis target line 0.29° off the tag. Attack angle reads -19.8°, steeper than expected for this chip and the least trustworthy value on the path. No value here has been checked against an independent reference.
- 149 Pi tests pass locally; TypeScript and lint pass.

## App 3.10.2 / Pi service 0.26.1 - 2026-09-17

- Extended manual OV9281 exposure control to 20–250 μs and added 20, 50 and 75 μs quick presets for stronger motion freezing. The camera may report a nearby value when sensor timing rounds the request.

## App 3.10.1 - 2026-09-17

- OpenGolfSim auto-send now forwards the same completed full-shot values displayed by the app. When camera metrics are unavailable, clearly-labelled club estimates fill the simulator payload instead of silently dropping the shot.
- Manual sending from Camera hit review uses the same completed estimated shot, and complete device shot events are deduplicated after their capture was already forwarded.

## App 3.10.0 - 2026-09-17

- Motion-tracked full-shot captures now open the shot review automatically, even when the camera could not resolve every metric.
- Missing values are estimated from the selected club and available ball/launch measurements. Smash factor derives from the best available ball and club speeds; spin uses the club baseline adjusted by launch angle.
- Shot review now labels individual values as measured, camera-estimated or club-estimated and shows a compact confidence percentage for each.

## App 3.9.1 - 2026-09-17

- Added n8n send controls to every Camera hit, including incomplete and departure-unconfirmed captures. Camera hits send the complete `CaptureAnalysis` record as a versioned `lm1.capture` event, while complete Shot log entries continue to use `lm1.shot`.

## App 3.9.0 - 2026-09-16

- Added a persisted n8n production-webhook setting in the Device tab. Each complete shot in Sessions now has an adjacent send button that posts the entire stored shot object in a versioned `lm1.shot` JSON envelope, with per-shot sending, success and error feedback.

## App 3.8.2 / Pi service 0.26.0 - 2026-09-16

- Explicit AprilTag calibration now saves a validated 3D ground pose and exact lens inputs. Shot analysis preferentially uses this stored geometry, allowing removal of the ground tag while the camera, focus, capture mode and hitting surface stay fixed. Diagnostics and metric reasons identify saved versus burst-derived pose. Old planar-only calibration requires a fresh capture before tag removal.
- Reset empty plane invalidates saved AprilTag geometry and target line. Successful lens recalibration also clears both; changed intrinsics, image size or tag dimensions reject reuse. Invalid calibration capture cannot overwrite an existing valid calibration. Visible tags retain the previous burst-derived fallback when no stored pose exists.
- App shows saved ground calibration after reconnect and explains tag removal and reset. Added stored-pose, tag-absent analysis, lens mismatch, invalidation and invalid-save tests. 120 Pi tests pass locally and on the Pi; TypeScript and lint pass locally.

## Pi service 0.25.0 - 2026-09-16

- Added single-frame bilateral denoising before departure tracking and measurement, including the armed reference. Original burst frames and displayed evidence remain unchanged. `PINPOINT_ANALYSIS_DENOISE=none` disables it; default is `bilateral` (diameter 5, sigma colour 12, sigma space 3). Capture diagnostics record filter parameters and processing time. No temporal averaging.
- Replayed capture-1789515451301879262 at 8x gain, 95 us actual exposure: raw 3.537 m/s versus filtered 3.5622 m/s, both 13 fitted frames and no spin. Tag pose error improves from 1.5514 to 1.3611 px; image fit barely changes (1.512 to 1.507 px), radius fit worsens (1.333 to 1.659 px). No claim of improved physical accuracy. JPEG replay differs from live pixels. Added noise/edge/raw-preservation regressions.

## Pi service 0.24.0 - 2026-09-15

- Added an anchored trajectory fit as the primary speed, launch-angle and direction estimator whenever at least six outgoing frames are tracked. It fits up to 48 frames in one model: the start point is the resting ball's ground position, sub-pixel image centres are weighted heavily, and apparent radius weakly. Earlier estimates came from 3–8 per-frame silhouette depths. Single-view depth error runs along the camera's line of sight, which rises about 24 degrees from the ball on the bench rig; this is the direction of the false 24-degree launch. A ground roll (with deceleration) and a gravity flight are both fitted. Flight is reported only when it explains the track clearly better and its launch exceeds three standard deviations.
- Balls moved before release (finger or clubhead nudges) fall back to a roll with a re-estimated ground start, provided its deceleration is physically plausible. One round of outlier rejection removes occluded frames. Per-shot `trajectoryFit` diagnostics record the model, start point, rejected frames, image and radius residuals, and fit uncertainties; metric reasons show fit ± values, which exclude lens and ground-tag calibration error. The fitted positions feed `ballTrack3d`, so Set target line uses the fitted roll direction. Tracks too short to fit keep the previous silhouette path.
- Template tracking now reports sub-pixel ball centres with parabolic peak interpolation, using a pixel-centre convention (previously whole pixels offset by half a pixel). Saved burst frames use JPEG quality 95 instead of 88, so offline replays stay closer to live analysis.
- Replays: `capture-1789479880648283083` 0.53 m/s, 0°, heading 91.7°, 1.6 px over 48 frames; `capture-1789480689809610280` 0.96 m/s, 0°, heading 68.8°, start re-estimated 37 mm from the nudged resting spot, 1.0 px; `capture-1789481235085592832` 0.86 m/s, 0°, heading 82.3°, start re-estimated 20 mm, two occluded frames rejected, 0.8 px. Analysis takes about one second locally. Values are unvalidated against an independent reference.
- Added tests for sub-pixel tracking, a rolling ball with a growing silhouette, an airborne launch with direction, a nudged start, occluded frames and the full measurement path. All 114 Pi tests pass locally.

## Pi service 0.23.6 - 2026-09-15

- Fixed contact analysis locking onto a hand that stays in view. A moving sequence now counts as the ball's departure only if it starts near the resting ball and the resting ball is not matched again afterwards. When several sequences qualify, the one nearest the debounced trigger wins, so an earlier finger nudge is not reported as the shot.
- Fixed a ball that armed while the placing hand still touched it. Analysis compares the armed image against the earliest burst frame and uses whichever finds the resting ball more cleanly. The monitor also refreshes the armed image while the ball stays within its arming bounds; a slow roll that shifts its bounds still keeps the original image.
- Replayed `capture-1789479880648283083`: first moving frame 157 (previously frame 17, hand matches, no measurement); ground-plane speed 0.54 m/s, consistent across 12- to 40-frame windows (the 3D-depth fit alone gave 0.71 m/s). Replayed `capture-1789480689809610280` with its saved hand-contaminated reference: first moving frame 191 (previously frame 138, a static lookalike, no measurement); 0.93 m/s along the ground. Speeds remain unvalidated against an independent reference.
- Fixed rolling balls reporting a launch angle. Single-view sphere depth follows apparent size, so a few percent of silhouette error moves a rolling ball's estimated centre up and down; `capture-1789481235085592832` read a 4% radius growth over frames 179–181 as a 24-degree launch at 2.23 m/s. When the fitted track stays within 20 mm of resting-ball height and rises less than 15 mm, the shot is reported as a ground roll: launch and carry are 0, and speed and start direction come from template-tracked ball-centre rays projected onto the ground plane. Captures record `groundRoll` evidence. Replays of all three rolls report 0 degrees; that capture measures 0.85 m/s along the ground.
- Added regressions for a moving lookalike while the ball rests, a contaminated armed reference, an early nudge before the roll, reference refresh while resting, a rolling ball with a growing silhouette and a rising ball that keeps its launch angle. All 108 Pi tests pass locally.

## Pi service 0.23.5 - 2026-09-15

- Fixed the rolling-ball reference becoming corrupted: the presence detector could continue accepting a slowly moving ball while its reference image was replaced and its original bounding box stayed fixed. The reference now remains paired with the arming bounds until disarm/reset. Each new capture preserves `armed-ball-reference.png` losslessly for replay.
- Replayed roll `capture-1789479880648283083` using its early stationary frame: the image track improves from three hand matches at frames 17–19 to 133 moving-ball matches at frames 157–289, with 11 strict 3D outlines and a provisional 0.71 m/s speed. The approximately 14-degree launch estimate is inconsistent with the intended ground roll and remains unvalidated.
- Added monitor-loop and lossless-reference regressions. All 102 tests pass locally and on the Pi.

## Pi service 0.23.4 / capture audit tool 1.0.0 - 2026-09-15

- Saved calibration inputs, inferred camera height/pitch, strict-outline counts and partial-outline rejection details with each capture. Failure messages distinguish captured frames, motion matches, accepted 3D outlines and consecutive sequences. Detailed diagnostics are excluded from Bluetooth summaries.
- Added a read-only capture audit script and a setup validation report under `output/capture-audit-v1.0.0`. Latest-shot replay confirms 325 frames at 241.57 fps, eight outgoing image matches, no accepted 3D sequence, brightness variation and about 22 cm of remaining ground-level travel in view.
- All 100 Pi tests pass locally and on the Pi. Experimental edge fitting remains an offline investigation; metric acceptance rules are unchanged.

## Camera target-line calibration tool 1.0.0 - 2026-09-15

- Added `scripts/set-camera-target-line.py` to project a left-to-right image line through the hitting position onto the calibrated ground plane and save its heading. Uses lens distortion correction and the newest capture's ground-tag pose; preserves the previous target line as a backup.

## Hardware bench prototype 0.5.1 - 2026-09-15

- Added a 28-degree downward camera bracket compatible with the v0.5.0 tray and mast. Only the bracket needs reprinting. Exported all three printable parts, assembly reference, preview and mesh validation report under `hardware/enclosure/stl/v0.5.1-test`.

## Pi service 0.23.3 / BLE protocol 2.17.0 - 2026-09-15

- Fixed contact analysis selecting frame 0 when a resting ball had shifted slightly from its placement bounds. Tracking now re-anchors to three strong nearby stationary observations and requires outward progress before accepting a moving sequence.
- Replayed capture `capture-1789475289749304965` (325 frames, 241.57 fps): the retained contact window resolves to stationary frame 164 and moving frame 166, rather than frame 0. The capture contains the contact window; the previous contact sheet selected the wrong frames.
- Added regressions for shifted resting balls and static template lookalikes. All 98 Pi tests pass. Camera frame rate and trigger debounce settings remain unchanged.

## 3.8.1 / Pi service 0.23.2 / BLE protocol 2.17.0 - 2026-09-14

- Fixed reconnects failing with “oversized Bluetooth message”: `listCaptures` now applies the existing ten-record history limit instead of serializing all 100 retained captures and their preview images. All captures remain stored on the Pi.

## 3.8.1 / Pi service 0.23.1 / BLE protocol 2.17.0 - 2026-09-14

- Expanded the default ball-detection region from 35% to 61.2% of the camera frame (`0.05,0.30,0.95,0.98`) for more flexible ball placement. Existing Pi installations retain their explicit `PINPOINT_BALL_ROI` setting; update it in `/etc/default/pinpoint`, then restart with the enlarged area empty.
- Added regression coverage for the expanded default region. App 3.8.1/build 40.

## 3.8.0 / Pi service 0.23.0 / BLE protocol 2.17.0 - 2026-09-14

- Added a guarded fallback for shots whose ball is tracked reliably but whose bright silhouette is partly clipped by the club, seams or background edges. The strict 0.82 fill path remains first; the fallback requires an independent template-track match, at least three consecutive frames, a stable apparent radius and the existing 8 mm 3D trajectory-fit limit.
- Replayed device capture `capture-1789392914021558544`: the original analyzer found 21 image-plane track points but zero accepted 3D silhouettes. The guarded fallback uses frames 162–164 and recovers a lower-confidence 6.33 m/s ball-speed estimate, 19.37° launch estimate and 2.56 m vacuum carry estimate with a 7.1 mm fit residual. Start direction remains unavailable until the target line is calibrated.
- New capture manifests retain `ballBounds`, so future saved bursts can be replayed with the exact armed-ball geometry instead of reconstructing it from logs.
- Added regression coverage for partial silhouettes and the three-consecutive-frame fallback guard. App 3.8.0/build 39.

## 3.7.3 / Pi service 0.22.0 / BLE protocol 2.17.0 - 2026-09-14

- Fixed captures that lost all launch data because the first visible ground AprilTag frame had a poor pose: compare up to 12 detections across the static burst and use the lowest reprojection-error pose.
- Keep the normal path at or below 1 px; allow 1–3 px only as an explicitly lower-confidence estimate with the exact error and source frame in capture metadata and metric provenance. Poses above 3 px remain rejected.
- Replayed `capture-1789337222749633794`: the original first pose failed at 2.31 px, while the new selector chose frame 445 at 0.0398 px and recovered a nine-point ball track plus ball speed, launch angle, start direction and carry estimates.
- App 3.7.3/build 38.

## 3.7.2 / Pi service 0.21.0 / BLE protocol 2.17.0 - 2026-09-14

- Fixed another "motion tracked, no data" case (capture-1789341264765340216): the ball was template-tracked across 40 frames, but no silhouette reached the depth fit. The dark seam line crossing the ball split the thresholded disc into two half-discs or cut a slit, so every blob failed the 0.82 fill test (fills 0.38–0.81). `ball_contours` now applies a 5 px elliptical close before contouring.
- Replayed with the real `measure_launch` on four Pi captures: the missed shot now gives 1.19 m/s from 16 silhouettes (2.0 mm residual); the previous seam shot improves from 7 to 15 silhouettes (1.23 m/s); an earlier good shot is unchanged (18 silhouettes, 1.27 vs 1.29 m/s); a hand-placement capture still yields no speed. Hull-area fill variants were rejected because they admitted lamp-flicker blobs at the resting position.
- Known limit: where the ball's top crosses the bright strip behind the mat, its silhouette is clipped and launch angle can be badly wrong (−21.8° on the missed shot) even though speed agrees across methods.
- App 3.7.2/build 37 (no app code changes).

## 3.7.1 / Pi service 0.20.0 / BLE protocol 2.17.0 - 2026-09-14

- Fixed ball-speed failures on shots whose motion was clearly tracked. On capture-1789340704201918915 the silhouette detector found clean ~35 px ball outlines in 13 outgoing frames, but the depth fit rejected all but one as "too small or distorted": the ball's dark seam line and shaded edge dent the thresholded outline, exceeding the cone-fit tolerance (1.05–1.77× the limit). `sphere_center` now fits the silhouette's convex hull points, which ignores those dents (0.18–0.61× the limit) while still rejecting stretched, merged or non-circular blobs.
- Replaying that capture on the Pi now yields a ball estimate from 7 frames: 1.19 m/s, launch −2.9°, 3.3 mm fit residual. A hull-area fill gate was evaluated and rejected because it admitted lamp-flicker blobs.
- App 3.7.1/build 36 (no app code changes).

## 3.7.0 / Pi service 0.19.0 / BLE protocol 2.17.0 - 2026-09-14

- Pi analysis was 5.9 s per shot on the Pi (profiled on capture-1789339832405469525); 4.6 s was full-resolution `matchTemplate` over all 270 frames. Ball tracking now searches at half resolution and re-scores a small full-resolution window, keeping the same score thresholds.
- BLE notifications were fixed 20-byte chunks every 15 ms (~1.3 KB/s): a capture event took ~3.7 s and a contact sheet ~24 s. The app now sends its negotiated MTU in the initial `status` request and the Pi sends `min(244, MTU - 3)`-byte chunks (~16 KB/s). App command writes also use MTU-sized chunks. Older apps that omit `mtu` keep 20-byte chunks.
- Camera preview notifications are skipped while a capture result is being delivered.
- App 3.7.0/build 35.

## 3.6.1 / Pi service 0.18.0 / BLE protocol 2.16.0 - 2026-09-14

- Shortened the rolling burst from 580 frames (~2.9 s with the Pi's `PINPOINT_PRE_IMPACT_FRAMES=400`) to 270 frames (~1.35 s): 120 pre-trigger, 120 removal-debounce and 30 post-removal frames. A struck ball crosses the view in ~40 ms and removal is confirmed ~0.5 s later, so the earlier ~2 s of pre-roll only fed the background median.
- Lowered the default `PINPOINT_DEPARTURE_TIMEOUT_SECONDS` from 1.0 to 0.5 so a forced removal still keeps the departure and resting-ball frames inside the shorter burst.
- Moved AprilTag detection, the focus metric, the camera snapshot write and BLE preview encoding to a background worker. Run inline every 3 s they stalled the camera loop 10–30 ms and dropped 200 fps frames in every retained burst, including one right at impact (capture-1789339311233490650, frame 420).
- Raised the Picamera2 request queue from 4 to 8 (`PINPOINT_CAMERA_BUFFER_COUNT`) to absorb remaining short stalls.
- About half the JPEG writes per capture, so results reach the app sooner and storage per burst drops by about half.
- App 3.6.1/build 34 (no app code changes).

## 3.6.0 / Pi service 0.17.0 / BLE protocol 2.16.0 - 2026-09-14

- Every camera capture card (Home, Putting, History) and every shot detail with a `captureId` now loads and shows that burst's 12-frame contact sheet automatically, with a retry on failure.
- Added BLE `captureContactSheet` (`captureId`) returning the saved `contact-sheet.jpg` of a specific retained burst; invalid or pruned captures return an error.
- Contact sheets are cached in the app for the session so reopening a shot does not re-transfer them.
- App 3.6.0/build 33.

## 3.5.4 / Pi service 0.16.4 / BLE protocol 2.15.4 - 2026-09-14

- Added live OV9281 analogue-gain control to the Device screen with decimal entry and 1×/2×/4×/8×/16× presets.
- Added BLE `setGain` plus sensor-derived `gainControl` capability metadata for the supported 1×–16× range.
- Persist exposure and gain together atomically; later exposure changes preserve the selected gain and both settings survive service restarts.
- Reject gain changes during automatic exposure, armed capture, or processing, and warn that higher gain adds image noise.
- App 3.5.4/build 32.

## 3.5.3 / Pi service 0.16.3 / BLE protocol 2.15.3 - 2026-09-13

- Added live manual OV9281 exposure control to the Device screen with numeric entry and 100/150/200/250 μs presets.
- Exposure updates apply without restarting the Pi service, persist atomically in `/var/lib/pinpoint/camera-settings.json`, and are restored after reboot.
- Limited app-controlled exposure to the measurement-safe 50–250 μs range and reject changes while armed or processing.
- Added BLE `setExposure` plus `exposureControl` capability metadata and focused Pi camera/protocol tests.
- App 3.5.3/build 31.

## 3.5.2 / Pi service 0.16.2 / BLE protocol 2.15.2 - 2026-09-13

- Separate the sampled/debounced `coarseDepartureFrameIndex` from `lastStationaryFrameIndex` and `firstMovingFrameIndex`; the backward-compatible `impactFrameIndex` now resolves to first observed motion when a coherent ball track exists.
- Track from the retained stable-ball image instead of the frame before the coarse trigger, which may already be empty, and require a coherent outward sequence to reject unrelated template matches.
- Capture manifests, frame replay responses, capture/shot events and app types now preserve all three markers. Replay shows the contact interval in orange and the later coarse trigger in gray.
- Added a regression for a ball that is already out of frame when the sampled departure trigger fires.
- App 3.5.2/build 30.

## 3.5.1 / Pi service 0.16.1 / BLE protocol 2.15.1 - 2026-09-13

- Increased rolling-capture retention from 10 to 100 complete bursts on the Pi, with one shared `PINPOINT_CAPTURE_RETENTION` setting used for disk pruning and restored/in-memory capture history.
- Added `captureId` to every `capture.json` manifest so copied capture folders remain self-identifying.
- App 3.5.1/build 29.
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

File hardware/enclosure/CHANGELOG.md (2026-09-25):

# LM1 enclosure changelog

## 0.6.1 modular stereo prototype - 2026-09-21

- Split the mast into two printable frames with double-sided bolted splice plates.
- Reduced the rigid one-piece stereo baseline to 90 mm so every part fits a 180 mm bed.
- Reduced the tray to 180 x 150 mm while retaining the 200 mm camera height and 20-degree pitch.
- Added per-part print-bed validation and modular assembly instructions.

## 0.6.0 stereo prototype - 2026-09-21

- Added a performance-oriented dual-camera tray, widened mast and rigid carrier.
- Increased the horizontal optical baseline from 58 mm to 120 mm for stronger triangulation.
- Raised lens centres to 200 mm and set 20-degree pitch for a nominal 550 mm ground intersection.
- Added cross ties, a 220 x 150 mm base and ballast slots to protect stereo calibration.
- Documented synchronization, cable strain relief, framing and calibration requirements.

## 0.5.3 test prototype - 2026-09-21

- Replaced the single-camera test bracket with a rigid two-camera carrier.
- Set a 58 mm horizontal optical baseline and retained the 15-degree downward pitch.
- Preserved the v0.5.2 four-hole mast interface so only the bracket needs reprinting.
- Kept independent lens apertures and 24–34 mm adjustable mounting patterns per camera.
- Added versioned STL output, assembly preview, usage notes and mesh validation.

## 0.5.2 test prototype - 2026-09-17

- Replaced the 28-degree test camera bracket with a 15-degree downward bracket.
- Preserved the v0.5.1 mast interface, camera slots and print orientation for a direct swap.
- Added versioned STL output and mesh validation for the new bracket.

## 0.5.0 test prototype - 2026-09-06

- Added a separate three-piece open Pi tray, camera mast and 13-degree bracket.
- Reduced the test footprint to 140 x 130 mm, with accessible ports and cooling.
- Validated exported STL closure, positive volume and single-solid connectivity.
- Kept the full enclosure revisions available alongside the bench prototype.

## 0.4.0 - 2026-09-04

- Replaced the flat top display with a separate angled OLED pod.
- Tilted the OLED 35 degrees above horizontal for visibility at address.
- Added a rotating cable collar and dual locking arcs for 35 degrees of yaw
  adjustment toward either a left- or right-handed player.
- Split the display assembly into a top lid, swivel base, tilted cradle and
  replaceable OLED retainer.

## 0.3.0 - 2026-09-04

- Reduced the enclosure body from 210 mm to 170 mm wide.
- Moved the two LED modules below the camera and its wide-angle hood.
- Replaced the large one-piece chassis with a base, front panel, rear panel,
  two reversible side panels and four universal corner rails.
- Added recessed base holes for an optional steel ballast plate.
- Kept the camera, hood, window, OLED and LED adapters independently replaceable.
- Kept every individual printable part within 180 x 174 mm.

## 0.2.0 - 2026-09-04

- Added a printable Raspberry Pi 5 chassis with standard mounting bosses.
- Fixed the camera optical centre at 150 mm and the camera plate at 13 degrees downward.
- Added a removable wide-angle sun hood and replaceable window retainer.
- Added a removable top with a provisional 2.79-inch OLED opening and clamp.
- Added dual LED apertures, a 40 mm rear fan pattern and cross-flow vents.
- Exported separate watertight STL parts and an assembly reference.
# 0.7.2

- Rotated the 150 mm power pack crosswise across the rear of the base so its
  enclosure no longer overlaps either mast foot or mast mounting bolt.
- Located the provisional LiPo enclosure front-centre between the uprights.
- Removed the long thin battery rails from the base.
- Added separate support-free enclosures for the power pack, LiPo, two camera
  boards, Pi 5, IR ring and two 20 mm side lights.
- Added an assembled component render showing the packaging arrangement.

# 0.7.1

- Split the camera module into a flat support-free sensor plate and two small
  side-printable 18-degree tilt rails.
- Added large plate relief openings while preserving structural webs around
  both cameras, the ring mount and the two side lights.

# 0.7.0

- Reworked the development rig around an 85 mm vertical stereo baseline.
- Moved the Raspberry Pi into the optical head to keep both 150 mm CSI ribbons short.
- Added a measured 150 x 65 x 30 mm power-pack cradle and adjustable LiPo strap area.
- Added a provisional 80 mm IR-ring retainer and two 20 mm side-light positions.
- Split the mast for a 180 x 180 mm printer and kept the camera/light carrier rigid.

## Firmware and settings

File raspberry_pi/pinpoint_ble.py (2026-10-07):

#!/usr/bin/env python3
"""Pinpoint BLE-only GATT peripheral for Raspberry Pi OS."""

from __future__ import annotations

import asyncio
import logging
import os
import signal
import threading
from concurrent.futures import CancelledError as FutureCancelledError
from typing import Any

from camera_source import camera_diagnostics, uses_csi

from bless import (
    BlessGATTCharacteristic,
    BlessServer,
    GATTAttributePermissions,
    GATTCharacteristicProperties,
)

from pinpoint_protocol import (
    PinpointProtocol,
    PROTOCOL_VERSION,
    SERVICE_VERSION,
    build_preview_event,
    configured_camera_device,
    encode_message_chunks,
)

try:
    from ball_detector import BallEvent, BallMonitor
except ModuleNotFoundError:
    BallEvent = Any  # type: ignore[misc,assignment]
    BallMonitor = None  # type: ignore[assignment]


SERVICE_UUID = "7f510000-1b15-4d8d-8d9c-5f7b6a210001"
COMMAND_UUID = "7f510001-1b15-4d8d-8d9c-5f7b6a210001"
EVENT_UUID = "7f510002-1b15-4d8d-8d9c-5f7b6a210001"
NOTIFICATION_GAP_SECONDS = 0.015
COMMAND_PERMISSIONS = GATTAttributePermissions.writeable
EVENT_PERMISSIONS = GATTAttributePermissions.readable

logging.basicConfig(
    level=os.getenv("PINPOINT_LOG_LEVEL", "INFO").upper(),
    format="%(asctime)s %(levelname)s %(name)s: %(message)s",
)
LOGGER = logging.getLogger("pinpoint.ble")


class PinpointBlePeripheral:
    def __init__(self, loop: asyncio.AbstractEventLoop) -> None:
        self.loop = loop
        self.server = BlessServer(
            name=os.getenv("PINPOINT_BLE_NAME", "LM1 PRO"),
            loop=loop,
        )
        self.server.read_request_func = self._on_read
        self.server.write_request_func = self._on_write
        self.protocol = PinpointProtocol(
            self.send_message,
            reset_ball_calibration=self._reset_ball_calibration,
            request_calibration_capture=self._request_calibration_capture,
            request_exposure_calibration=self._request_exposure_calibration,
        )
        self._notification_lock = asyncio.Lock()
        self._ball_stop = threading.Event()
        self._ball_calibration_reset = threading.Event()
        self._calibration_capture_request = threading.Event()
        self._calibration_capture_camera = "primary"
        self._exposure_calibration_request = threading.Event()
        self._ball_task: asyncio.Task[None] | None = None
        self._preview_future: Any | None = None
        self._preview_logged = False

    def _reset_ball_calibration(self) -> bool:
        if self._ball_task is None or self._ball_task.done():
            return False
        self._ball_calibration_reset.set()
        return True

    def _request_calibration_capture(self, camera: str = "primary") -> bool:
        if self._ball_task is None or self._ball_task.done():
            return False
        self._calibration_capture_camera = camera
        self._calibration_capture_request.set()
        return True

    def _request_exposure_calibration(self) -> bool:
        if self._ball_task is None or self._ball_task.done():
            return False
        self._exposure_calibration_request.set()
        return True

    def _on_read(
        self,
        characteristic: BlessGATTCharacteristic,
        *_: Any,
        **__: Any,
    ) -> bytearray:
        return characteristic.value or bytearray(f"pinpoint/{PROTOCOL_VERSION}\n", "ascii")

    def _on_write(
        self,
        characteristic: BlessGATTCharacteristic,
        value: Any,
        *_: Any,
        **__: Any,
    ) -> None:
        characteristic.value = bytearray(value)
        if str(characteristic.uuid).lower() != COMMAND_UUID:
            return
        future = asyncio.run_coroutine_threadsafe(
            self.protocol.receive_chunk(bytes(value)),
            self.loop,
        )
        future.add_done_callback(self._log_command_error)

    @staticmethod
    def _log_command_error(future: Any) -> None:
        try:
            future.result()
        except Exception:
            LOGGER.exception("BLE command processing failed")

    async def send_message(self, message: dict[str, Any]) -> None:
        characteristic = self.server.get_characteristic(EVENT_UUID)
        if characteristic is None:
            LOGGER.error("Event characteristic is unavailable")
            return

        async with self._notification_lock:
            for chunk in encode_message_chunks(message, self.protocol.notification_chunk_bytes):
                characteristic.value = bytearray(chunk)
                self.server.update_value(SERVICE_UUID, EVENT_UUID)
                await asyncio.sleep(NOTIFICATION_GAP_SECONDS)

    async def start(self) -> None:
        await self.server.add_new_service(SERVICE_UUID)
        await self.server.add_new_characteristic(
            SERVICE_UUID,
            COMMAND_UUID,
            GATTCharacteristicProperties.write,
            bytearray(),
            COMMAND_PERMISSIONS,
        )
        await self.server.add_new_characteristic(
            SERVICE_UUID,
            EVENT_UUID,
            GATTCharacteristicProperties.read | GATTCharacteristicProperties.notify,
            bytearray(f"pinpoint/{PROTOCOL_VERSION}\n", "ascii"),
            EVENT_PERMISSIONS,
        )
        await self.server.start()
        LOGGER.info(
            "Pinpoint BLE service %s is advertising (protocol %s)",
            SERVICE_VERSION,
            PROTOCOL_VERSION,
        )
        self._start_ball_monitor()

    def _start_ball_monitor(self) -> None:
        enabled = os.getenv("PINPOINT_AUTO_BALL_DETECTION", "false").lower() in {
            "1",
            "true",
            "yes",
        }
        camera_device = configured_camera_device()
        preview_enabled = os.getenv("PINPOINT_BLE_PREVIEW", "false").lower() in {"1", "true", "yes"}
        if not enabled and not preview_enabled:
            LOGGER.info("Camera monitoring is disabled")
            return
        if BallMonitor is None:
            LOGGER.error("Automatic ball detection needs the python3-opencv package")
            return
        if not uses_csi() and (camera_device is None or not camera_device.exists()):
            LOGGER.warning("Automatic ball detection is waiting for a configured camera")
            return

        monitor = BallMonitor(camera_device)
        self._ball_stop.clear()
        self._calibration_capture_request.clear()
        self._exposure_calibration_request.clear()
        self._ball_task = asyncio.create_task(
            asyncio.to_thread(
                monitor.run,
                self._ball_stop,
                self._on_ball_event,
                self._on_preview_frame,
                self._ball_calibration_reset,
                self._calibration_capture_request,
                self._on_calibration_result,
                self._exposure_calibration_request,
                self._on_exposure_calibration,
                calibration_capture_camera=lambda: self._calibration_capture_camera,
                capture_mode=lambda: self.protocol.capture_mode,
                current_club=lambda: self.protocol.club_id,
                emit_readiness=self._on_readiness,
            )
        )
        self._ball_task.add_done_callback(self._log_ball_monitor_error)

    def _on_ball_event(self, event: BallEvent) -> None:
        future = asyncio.run_coroutine_threadsafe(
            self.protocol.ball_presence_changed(
                event.present,
                event.rolling_capture_frames or event.frame_count,
                event.duration_ms,
                event.capture_id,
                event.impact_frame_index,
                event.analysis,
            ),
            self.loop,
        )
        future.add_done_callback(self._log_command_error)

    def _on_readiness(self, items: list[dict[str, Any]]) -> None:
        future = asyncio.run_coroutine_threadsafe(self.protocol.readiness_checked(items), self.loop)
        future.add_done_callback(self._log_command_error)

    def _on_calibration_result(self, result: dict[str, Any]) -> None:
        future = asyncio.run_coroutine_threadsafe(
            self.protocol.calibration_image_captured(result),
            self.loop,
        )
        future.add_done_callback(self._log_command_error)

    def _on_exposure_calibration(self, result: dict[str, Any]) -> None:
        future = asyncio.run_coroutine_threadsafe(
            self.protocol.exposure_calibrated(result),
            self.loop,
        )
        future.add_done_callback(self._log_command_error)

    def _on_preview_frame(self, jpeg_bytes: bytes, secondary_jpeg: bytes | None = None) -> None:
        if os.getenv("PINPOINT_BLE_PREVIEW", "false").lower() not in {
            "1",
            "true",
            "yes",
        }:
            return
        if self._preview_future is not None and not self._preview_future.done():
            return
        if self.protocol.state == "processing":
            return  # The capture result owns the notification channel until it is delivered.
        if not self._preview_logged:
            LOGGER.info("Camera preview ready: %d JPEG bytes; diagnostics=%s", len(jpeg_bytes), camera_diagnostics())
            self._preview_logged = True
        self._preview_future = asyncio.run_coroutine_threadsafe(
            self.send_message(build_preview_event(jpeg_bytes, secondary_jpeg)),
            self.loop,
        )
        self._preview_future.add_done_callback(self._log_preview_error)

    @staticmethod
    def _log_preview_error(future: Any) -> None:
        try:
            future.result()
        except FutureCancelledError:
            return
        except Exception:
            LOGGER.exception("BLE preview transfer failed")

    @staticmethod
    def _log_ball_monitor_error(task: asyncio.Task[None]) -> None:
        if task.cancelled():
            return
        try:
            task.result()
        except Exception:
            LOGGER.exception("Automatic ball detector stopped unexpectedly")

    async def stop(self) -> None:
        self._ball_stop.set()
        if self._ball_task:
            try:
                await asyncio.wait_for(self._ball_task, timeout=3)
            except TimeoutError:
                self._ball_task.cancel()
                await asyncio.gather(self._ball_task, return_exceptions=True)
            self._ball_task = None
        await self.protocol.close()
        await self.server.stop()


async def main() -> None:
    loop = asyncio.get_running_loop()
    stopped = asyncio.Event()
    peripheral = PinpointBlePeripheral(loop)

    for signal_name in (signal.SIGINT, signal.SIGTERM):
        loop.add_signal_handler(signal_name, stopped.set)

    await peripheral.start()
    try:
        await stopped.wait()
    finally:
        await peripheral.stop()


if __name__ == "__main__":
    asyncio.run(main())

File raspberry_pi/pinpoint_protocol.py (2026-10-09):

"""Transport-independent Pinpoint BLE protocol and camera-free test runtime."""

from __future__ import annotations

import asyncio
import base64
import json
import logging
import math
import os
import re
import shutil
import subprocess
import time
from collections.abc import Awaitable, Callable
from datetime import datetime, timezone
from pathlib import Path
from typing import Any
from uuid import uuid4

from rig_pose import ground_mode, level_rig_pose, load_rig, rig_summary
from apriltag_calibration import calibration_version, capture_latest_apriltag_calibration, clear_apriltag_calibration, load_apriltag_calibration
from camera_source import (
    camera_diagnostics,
    configured_exposure_us,
    exposure_configuration,
    gain_configuration,
    set_camera_gain,
    active_light,
    light_mode,
    set_camera_exposure,
    blur_safe_exposure_us,
    set_exposure_cap_hint,
    set_light_mode,
    set_strobe_mode,
    strobe_mode_enabled,
    uses_csi,
)
from light_controller import get_light_controller, preset_for_club, strobe_pattern, indicator_state
from ball_detector import (
    DEFAULT_BALL_ROI,
    DEFAULT_ROLLING_CAPTURE_PATH,
    CALIBRATION_CAMERAS,
    calibration_capture_status,
    capture_retention,
    capture_contact_sheet,
    capture_clip,
    capture_frame_preview,
    clear_calibration_images,
    lens_calibration_status,
    latest_rolling_capture_preview,
    run_lens_calibration,
)

from target_line import clear_target_line, heading_from_track, load_target_line, save_target_line
from capture_quality import shot_evidence
from flight_model import carry_meters, select_spin
from frame_uploader import FrameUploadSource
from wifi_manager import (
    WifiProvisioningError,
    connect_wifi,
    get_wifi_status,
    scan_wifi_networks,
    wifi_provisioning_available,
)


SERVICE_VERSION = "0.63.0"
PROTOCOL_VERSION = "2.40.0"
MAX_HISTORY = 10
MAX_COMMAND_BYTES = 4096
BLE_CHUNK_BYTES = 20
# ATT notification payload is MTU - 3. 514 matches the 517-byte MTU Android can
# request; 244 was the old 247-byte MTU. Larger chunks mean fewer notifications and
# a faster transfer at the same pacing (same drop risk, ~2x throughput).
MAX_NOTIFICATION_CHUNK_BYTES = 514
DEFAULT_USB_CAPTURE_PATH = Path("/var/lib/pinpoint/usb-test-latest.jpg")

SendMessage = Callable[[dict[str, Any]], Awaitable[None]]
LOGGER = logging.getLogger("pinpoint.protocol")

VALID_CLUBS = {
    "driver",
    "3-wood",
    "5-wood",
    "3-hybrid",
    "4-hybrid",
    "4-iron",
    "5-iron",
    "6-iron",
    "7-iron",
    "8-iron",
    "9-iron",
    "pitching-wedge",
    "gap-wedge",
    "sand-wedge",
    "lob-wedge",
}

CLUB_PROFILES: dict[str, tuple[float, float, float]] = {
    "driver": (42.5, 1.46, 14.0),
    "3-wood": (40.2, 1.44, 15.0),
    "5-wood": (38.4, 1.42, 16.5),
    "3-hybrid": (37.0, 1.40, 17.0),
    "4-hybrid": (35.8, 1.39, 18.0),
    "4-iron": (34.5, 1.37, 17.0),
    "5-iron": (33.5, 1.36, 18.0),
    "6-iron": (32.4, 1.35, 19.0),
    "7-iron": (31.3, 1.34, 20.0),
    "8-iron": (30.0, 1.33, 22.0),
    "9-iron": (28.7, 1.32, 25.0),
    "pitching-wedge": (27.0, 1.30, 28.0),
    "gap-wedge": (25.5, 1.28, 31.0),
    "sand-wedge": (23.8, 1.25, 34.0),
    "lob-wedge": (22.0, 1.22, 38.0),
}


class CommandError(Exception):
    """An error safe to return to the connected app."""


def utc_now() -> str:
    return datetime.now(timezone.utc).isoformat(timespec="milliseconds").replace("+00:00", "Z")


def read_temperature_c() -> float:
    try:
        raw = Path("/sys/class/thermal/thermal_zone0/temp").read_text(encoding="utf-8").strip()
        return round(float(raw) / 1000, 1)
    except (OSError, ValueError):
        return 0.0


def storage_free_gb() -> float:
    return round(shutil.disk_usage("/").free / 1_000_000_000, 1)


def configured_camera_device() -> Path | None:
    configured = os.getenv("PINPOINT_CAMERA_DEVICE", "").strip()
    if configured:
        return Path(configured)

    camera_links = sorted(Path("/dev/v4l/by-id").glob("*-video-index0"))
    return camera_links[0] if camera_links else None


def camera_is_available(capture_backend: str) -> bool:
    if uses_csi():
        return bool(camera_diagnostics())
    override = os.getenv("PINPOINT_CAMERA_CONNECTED")
    if override is not None:
        return override.lower() in {"1", "true", "yes"}
    device = configured_camera_device()
    return device is not None and device.exists()
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

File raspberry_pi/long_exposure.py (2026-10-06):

"""Ball speed and launch angle from long-exposure (strobe-mode) frames.

Strobe mode exposes for about 3.9 ms, so a moving ball is a smear, not a disc, and the
usual silhouette fit cannot run (launch measurement requires an exposure of 250 us or
less). The middle of the smear is still where the ball was half way through the
exposure, so following that middle frame to frame gives a usable image-plane speed and
launch angle. Where the room is dark enough that the ring's flashes dominate, a frame
holds several separate ball copies; this tracker follows the one nearest the predicted
position, so those frames work too, only less completely than a purpose-built copy fit.

Everything here is an estimate:

* distances use the resting ball's width as the scale (42.67 mm), so motion toward or
  away from the camera is not seen and the scale drifts as the ball changes distance;
* the image is assumed to look side-on at the flight, with the target to the right.

The numbers are labelled "estimated" with that reason wherever they are shown.
"""

from __future__ import annotations

import json
import math
import sys
from pathlib import Path
from typing import Any, Sequence

import cv2
import numpy as np

BALL_DIAMETER_MM = 42.67
THRESHOLD = 35          # grey levels brighter than the empty scene (the ball against a dark mat)
MIN_AREA_RATIO = 0.5    # blob area as a fraction of the resting ball's disc
MAX_AREA_RATIO = 2.0    # a smeared ball is at most about 1.7x; the club head is 2.5x or more
MIN_CIRCULARITY = 0.5   # a smeared ball is a rounded capsule, not a perfect disc
MAX_ASPECT = 2.0
MAX_MISSES = 2          # lost frames before the track ends
MAX_TRACK_FRAMES = 40
FIT_POINTS = 4          # moving points used for the speed fit
MIN_MOVE_BALL_WIDTHS = 0.6  # first moving point is this far from the resting ball


def _gray(image: Any) -> np.ndarray:
    array = np.asarray(image)
    return array if array.ndim == 2 else cv2.cvtColor(array, cv2.COLOR_BGR2GRAY)


def _blobs(frame: np.ndarray, background: np.ndarray, ball_px: float) -> list[dict[str, float]]:
    """Round, ball-sized regions that are brighter than the empty scene.

    The club head and shaft are brighter than the empty scene too, but they are large and
    elongated; the ball is a compact round smear. Shape, not size alone, tells them apart.
    """
    difference = cv2.GaussianBlur(frame, (5, 5), 0).astype(np.int16) - background.astype(np.int16)
    mask = (difference > THRESHOLD).astype(np.uint8)
    mask = cv2.morphologyEx(mask, cv2.MORPH_OPEN, np.ones((3, 3), np.uint8))
    mask = cv2.morphologyEx(mask, cv2.MORPH_CLOSE, np.ones((5, 5), np.uint8))
    contours, _ = cv2.findContours(mask, cv2.RETR_EXTERNAL, cv2.CHAIN_APPROX_SIMPLE)
    ball_area = math.pi * (ball_px / 2.0) ** 2
    found = []
    for contour in contours:
        area = float(cv2.contourArea(contour))
        if not MIN_AREA_RATIO * ball_area <= area <= MAX_AREA_RATIO * ball_area:
            continue
        perimeter = cv2.arcLength(contour, True)
        circularity = 4.0 * math.pi * area / (perimeter * perimeter + 1e-6)
        x, y, w, h = cv2.boundingRect(contour)
        aspect = max(w, h) / max(1.0, min(w, h))
        fill = area / float(w * h)
        if circularity < MIN_CIRCULARITY or aspect > MAX_ASPECT or fill < 0.5:
            continue
        moments = cv2.moments(contour)
        if moments["m00"] <= 0:
            continue
        found.append({
            "x": moments["m10"] / moments["m00"], "y": moments["m01"] / moments["m00"], "area": area,
            "width": float(w), "height": float(h), "circularity": circularity,
        })
    return found


def _background(frames: Sequence[tuple[float, Any]]) -> np.ndarray:
    return np.median(
        np.stack([cv2.GaussianBlur(_gray(image), (5, 5), 0) for _, image in frames[-3:]]), axis=0,
    ).astype(np.uint8)


def _follow(blob_lists: Sequence[list[dict[str, float]]], times: Sequence[float], first_index: int,
            last: tuple[float, float], velocity: tuple[float, float], ball_px: float,
            points: list[dict[str, float]]) -> list[dict[str, float]]:
    """Greedy nearest-to-prediction tracking, one ball-sized blob per frame."""
    misses = 0
    for index in range(first_index, min(len(blob_lists), first_index + MAX_TRACK_FRAMES)):
        predicted = (last[0] + velocity[0], last[1] + velocity[1])
        reach = max(1.2 * ball_px, 1.6 * math.hypot(*velocity) + 0.8 * ball_px)
        best = None
        for blob in blob_lists[index]:
            distance = math.hypot(blob["x"] - predicted[0], blob["y"] - predicted[1])
            if distance > reach:
                continue
            # A ball-sized smear beats a club, a leg or a shadow that happens to be close.
            size = blob["area"] / (math.pi * (ball_px / 2.0) ** 2)
            score = distance / reach + 0.15 * abs(math.log(size)) + 0.3 * (1.0 - blob["circularity"])
            if best is None or score < best[0]:
                best = (score, blob)
        if best is None:
            misses += 1
            if misses > MAX_MISSES:
                break
            continue
        misses = 0
        blob = best[1]
        velocity = (blob["x"] - last[0], blob["y"] - last[1])
        last = (blob["x"], blob["y"])
        points.append({"frameIndex": index, "t": float(times[index]), "x": blob["x"], "y": blob["y"],
                       "area": blob["area"], "extentPx": max(blob["width"], blob["height"])})
    return points
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

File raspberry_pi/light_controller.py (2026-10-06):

"""USB link to the ESP32 that drives the IR ring: off, steady (flat) or strobing.

The ESP32 boots in flat (steady) light and, while strobing, drops back to flat by
itself when it stops hearing from the host, so a crashed service can never leave
the ring flickering. This side keeps a heartbeat going, reconnects when the cable
is unplugged and re-applies the wanted mode after every reconnect.

Nothing here is required: without PINPOINT_LIGHT_CONTROL=esp32 the service runs
exactly as it did before and `get_light_controller()` returns None.
"""

from __future__ import annotations

import glob
import logging
import os
import threading
import time
from typing import Any, Callable

LOGGER = logging.getLogger("pinpoint.light")

RING_MODES = ("off", "flat", "strobe")
STROBE_PRESETS = ("driver", "iron", "chip")
HEARTBEAT_SECONDS = 1.0
RECONNECT_SECONDS = 2.0
BAUD = 115200

def indicator_state(device_state: str, ball_present: bool) -> str:
    if device_state == "processing":
        return "processing"
    return "ready" if ball_present else "searching"


def preset_for_club(club_id: str | None) -> str:
    """Pick the flash pattern for a club type: wide gaps for slow balls, tight for fast."""
    club = (club_id or "").lower()
    if club == "driver" or "wood" in club or "hybrid" in club:
        return "driver"
    if "wedge" in club or "putter" in club:
        return "chip"
    return "iron"


BALL_DIAMETER_MM = 42.67
MAX_PATTERN_GAPS = 15


def strobe_pattern(ball_speed_mps: float, period_us: int) -> dict[str, Any]:
    """Flash pulse and gaps for one burst, sized for a club's expected ball speed.

    The gaps keep neighbouring ball copies from overlapping even when the ball is 20 %
    slower than expected (1.1 ball widths apart), and grow 8 % each so every copy can be
    told from its neighbours. The pulse blurs the ball by about 1.2 mm: short for fast
    balls, longer (more light) for slow ones. A burst may fill 82 % of the frame, and
    the quiet stretch before the next frame's burst must also be a usable gap, so slow
    shots get fewer flashes - down to one per frame.
    """
    speed = min(95.0, max(8.0, float(ball_speed_mps)))
    pulse = int(min(60, max(15, round(1200.0 / speed))))
    first_gap = 1.375 * BALL_DIAMETER_MM / speed * 1000.0
    budget = 0.82 * period_us
    gaps: list[int] = []
    while len(gaps) < MAX_PATTERN_GAPS:
        gap = int(round(first_gap * 1.08 ** len(gaps) / 10.0) * 10)
        burst = pulse + sum(gaps) + gap
        if burst > budget or period_us - burst < 0.95 * first_gap:
            break
        gaps.append(gap)
    return {"pulseUs": pulse, "gapsUs": gaps, "ballSpeedMps": round(speed, 1)}


def _find_port() -> str | None:
    explicit = os.getenv("PINPOINT_LIGHT_PORT")
    if explicit:
        return explicit
    for pattern in ("/dev/serial/by-id/*Espressif*", "/dev/serial/by-id/*ESP32*", "/dev/ttyACM*"):
        found = sorted(glob.glob(pattern))
        if found:
            return found[0]
    return None


def _open_serial(port: str) -> Any:
    import serial  # pyserial; imported late so the service starts without it

    return serial.Serial(port, BAUD, timeout=0.2, write_timeout=1.0)


class LightController:
    def __init__(self, *, fps: int = 242, find_port: Callable[[], str | None] = _find_port,
                 open_port: Callable[[str], Any] = _open_serial,
                 heartbeat_seconds: float = HEARTBEAT_SECONDS) -> None:
        self._fps = int(fps)
        self._find_port = find_port
        self._open_port = open_port
        self._heartbeat = heartbeat_seconds
        self._lock = threading.RLock()
        self._serial: Any = None
        self._port: str | None = None
        self._mode = "flat"
        self._preset = "driver"
        self._pattern: dict[str, Any] | None = None
        self._reported_mode: str | None = None
        self._error: str | None = None
        self._stop = threading.Event()
        self._thread: threading.Thread | None = None
        self._status_provider: Callable[[], str] | None = None
        self._sent_status: str | None = None

    def set_status_provider(self, provider: Callable[[], str]) -> None:
        self._status_provider = provider

    def _update_status_locked(self) -> None:
        if self._serial is None or self._status_provider is None:
            return
        state = self._status_provider()
        if state not in {"searching", "ready", "processing"}:
            return
        if state != self._sent_status:
            self._serial.write(f"led {state}\n".encode("ascii"))
            self._sent_status = state

    # -- public -----------------------------------------------------------------
    def start(self) -> None:
        if self._thread is not None and self._thread.is_alive():
            return
        self._stop.clear()
        self._thread = threading.Thread(target=self._run, name="light-controller", daemon=True)
        self._thread.start()

    def stop(self) -> None:
        self._stop.set()
        if self._thread is not None:
            self._thread.join(timeout=2)
        self._close()

    def set_mode(self, mode: str, preset: str | None = None, pattern: dict[str, Any] | None = None) -> bool:
        """Remember the wanted ring mode and send it now if the ESP32 is connected.

        In strobe, `pattern` ({pulseUs, gapsUs}) overrides the named preset, which is then
        only a label for the club group."""
        if mode not in RING_MODES:
            raise ValueError("Ring mode must be off, flat or strobe.")
        if preset is not None and preset not in STROBE_PRESETS:
            raise ValueError("Unknown strobe preset.")
        with self._lock:
            self._mode = mode
            if preset is not None:
                self._preset = preset
            self._pattern = dict(pattern) if pattern and mode == "strobe" else None
            return self._apply_locked()

    def status(self) -> dict[str, Any]:
        with self._lock:
            return {
                "available": True,
                "connected": self._serial is not None,
                "port": self._port,
                "mode": self._mode,
                "rateHz": self._fps,
                "preset": self._preset if self._mode == "strobe" else None,
                "pattern": self._pattern if self._mode == "strobe" else None,
                "reportedMode": self._reported_mode,
                "error": self._error,
            }
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

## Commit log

2026-09-18 Add hardware, Raspberry Pi tools & UI updates
    Bulk additions and updates: add extensive hardware CAD/STL assets and enclosure releases, output artifacts, PDFs and image resources; introduce Raspberry Pi tooling, scripts and services (camera, cal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
    [assembly_reference_v0.5.0.stl, assembly_reference_v0.5.1.stl, assembly_reference_v0.5.2.stl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]
2026-09-18 Revamp README: new intro, badges, and docs
    Completely rewrite README to provide a clearer, structured project overview. Replaces the old header and long changelog with a centered logo/title, release badges, and an experimental warning. Adds sections detailing the three project parts (mobile app, Pi service, hardware), features for both Pi and app, hardware requirements, getting-started steps (Node.js 20+, dev build note, build commands), Pi setup and calibration guidance, scripts/test commands, project layout, documentation table, a security note, and contributing instructions. Overall cleanup and reorganization to make onboarding and development setup easier.
2026-09-25 LM1 3.37.0 / Pi 0.48.0: measurement workflow, stereo club, flight model
    Measurement workflow (from an audit of 40 real captures):
    - Pre-shot readiness check when the ball arms: camera alignment (same
    limits as the stereo fit), ground calibration, exposure vs club speed,
    face profile. Readiness event + status field; card on Monitor/Putting.
    - Keep ball-only shots when the club is not tracked; classify nudges,
    re-placed balls and rolls as not-a-strike instead.
    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
2026-09-25 LM1 3.38.0 / Pi 0.49.0: named clubs with face size and per-club stats
    - "My clubs" in the club picker: name, club type (for the flight and
    spin models), optional loft and measured face size with a
    how-to-measure guide. Stored on the device and in the account.
    - setClub/arm carry the named club (protocol 2.34.0). The Pi echoes
    bagClubId/bagClubName on captures and writes the face size as the
    club profile (source: app), never replacing a hand-made profile.
    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
2026-09-25 Pi 0.49.1 / 0.50.0: ground tag thickness, head tracking, club gates
    - PINPOINT_GROUND_TAG_THICKNESS_MM moves the world origin from the
    tag face onto the hitting surface. With the tag on a 4 mm plate,
    resting balls read ~4 mm low and failed the 5 mm stereo gate; on
    five real chips the error moved from -1..-6 to -2..+3 mm. Both
    cameras shift together, so triangulation is unchanged. Saved-capture
    replays apply the same shift. Deployed with 4 mm.
    - Track the club head as well as the shaft/hosel point: a chrome head
    over a light floor is darker than the background and its sole is
    seen differently by the two cameras. The head is found by change in
    either direction at ground level b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
    [club_stereo.py, club_vision.py, launch_measurements.py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]
2026-09-25 Pi 0.51.0: contact-window stereo start check, club track fallback
    - The stereo start check allowed no time for contact: the ball can be
    hit anywhere in the 4.1 ms between the last still and first moving
    frames, so a clean 10.9 m/s shot sat 40 mm "from" the resting ball
    and failed the 30 mm limit. Measure the distance to the nearest
    start any contact time in that window could produce, and report the
    implied contact time. Ten recent shots: 17-29 mm became 1-3 mm.
    - Try hosel and head points, with and without the contact frame; use
    the best-ranked track that passes the attack-angle, smash and speed
    checks. Club data on the last ten shots: 5 (was 3); morning chips
    unchanged at 13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
    [ball_detector.py, club_stereo.py, launch_measurements.py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]
2026-09-25 LM1 3.39.0 / Pi 0.52.0 + 0.53.0: swing loop, ball-referenced ground, placement
    Pi 0.52.0 / app 3.39.0:
    - Swing loop above ball speed (Monitor card and shot details): the
    captured swing from 10 frames before the ball moves to 9 after, in
    slow motion; tap to stop, step or jump, impact marked. New
    captureClip command sends a fixed, display-brightened crop around
    ball, club and early flight in batches of 8.
    - Ignore persistent changes when finding the club (a shifted white
    shoe was tracked at 0.0 m/s); count any club seen as swing evidence
    (a topped chip was classed as a roll).
    Pi 0.53.0:
    - Take each shot's ground from the resting 42.67 mm ball, triangulated
    by both cameras before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
    [ball_detector.py, capture_quality.py, club_stereo.py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]
2026-10-06 LM1 3.44.0 / Pi 0.62.0: sessions, staggered cameras, strobe effect
    - App 3.40-3.44: sessions with typed reference data and comparison,
    staggered-camera notice, device/calibration/history updates
    - Pi 0.54-0.62: level-rig ground, staggered capture, strobe copies,
    ESP32 light controller, status LEDs, OGS bridge, rejection hints
    - Strobe demo/test firmware sources, enclosure STLs v0.5.3-0.7.2,
    prototype scripts and docs
    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
    [assembly_reference_v0.5.3.stl, assembly_reference_v0.6.0.stl, assembly_reference_v0.6.1.stl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]
2026-10-06 Pi 0.62.1-0.62.3: strobe diagnostics, source-switch fix, faster raw conversion
    - 0.62.1: strobe shots that cannot be measured say why (ring state, flash
    pattern, copies found); always save diagnostics.strobe; install.sh now
    installs light_controller, raw_frames, rejection_hints, strobe_copies
    - 0.62.2: stop the raw/8-bit analysis source flipping while a ball is on the
    mat (a flip restarted calibration, learned the ball as background and left
    the status LED white with nothing detected); report ball removed on restart
    - 0.62.3: raw 10-bit to 8-bit conversion in two OpenCV passes (identical
    output, about 7x faster on the Pi); wedge patterns with under 3 flashes per
    frame are explain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
    [ball_detector.py, pinpoint_protocol.py, raw_frames.py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]
2026-10-07 Pi service: adaptive exposure, strobe fixes
    Add adaptive exposure policy and tests, a launch consistency plan, and strobe-pair timing to measure slow shots. Bump service to 0.62.4 and update changelog. Key changes: new adaptive_capture module and unit tests; BallMonitor triggers auto exposure sweep on club/scene changes and avoids holding raw frames outside strobe mode; strobe_copies gains a pairs-fit path for two-flash-per-frame patterns and improved reporting; rejection hints and strobe messages adjusted for pair-mode behavior; camera_source default light mode set to auto; reduced clip width/bytes and tweaked JPEG quality; BallDetector memory and encoding optimizations; launch_measurements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
    [adaptive_capture.py, ball_detector.py, camera_source.py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]
2026-10-08 Mission-control UI refresh: black canvas, hairlines, mono telemetry labels, HUD hero
    Theme tokens reworked (true black, cool neutrals, ice-blue signal colour, sharper radii,
    no shadows). Buttons are white/uppercase, nav gets a top-line active indicator, header
    becomes a wordmark, hero gets reticle corners. Green-tinted hardcoded colours moved to
    theme tokens.
2026-10-08 Bottom menu: merge Putting into Play tab with Swing/Putting switch; 3.44.1 release prep
2026-10-09 Shutter speed limited only by the sensor (Pi 0.63.0, app 3.45.0)
    The Pi reads the exposure range from libcamera when the cameras open, capped at
    one frame period, and accepts any whole microsecond in it in every light mode.
    The automatic sweep and the 250 us measurement rule are unchanged. A shutter set
    by hand leaves Auto so the sweep cannot overwrite it. The app shows the applied
    shutter, warns above the measurement limit and offers 10-4000 us presets.
